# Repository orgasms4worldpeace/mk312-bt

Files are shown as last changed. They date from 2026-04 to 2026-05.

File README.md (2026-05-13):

# MK-312BT

DIY build of the **ErosTek ET-312B** e-stim power box, with Bluetooth (HC-05) or WiFi (ESP8266) wireless control. Boards, BOM, firmware, case, and the documentation needed to actually build one.

> ⚠️ **Safety.** This is a high-voltage device. Don't injure yourself. No warranty.

## How to build one

Work through the numbered directories in order. The full step-by-step walkthrough is in **[`build-guide.md`](build-guide.md)**.

| Step | Directory | What you do |
|---|---|---|
| 1 | [`1-order-boards/`](1-order-boards/) | Send the main-board + front-panel gerbers to JLCPCB |
| 2 | [`2-order-parts/`](2-order-parts/) | Import the BOM into Mouser. Pre-match MOSFETs by Vt — this prevents Error 20 |
| 3 | [`3-build-and-flash/`](3-build-and-flash/) | Solder, print the case, flash the ATmega16A |
| 4 | [`4-wireless/`](4-wireless/) | Pick **Bluetooth** (HC-05) or **WiFi** (ESP8266 — required for macOS / iOS) |
| 5 | [`5-software/`](5-software/) | Pick a control client (links to upstream projects — none bundled) |

If anything misbehaves, [`3-build-and-flash/troubleshooting/`](3-build-and-flash/troubleshooting/) has per-failure-code analyses and the archived metafetish.club forum threads.

## Speculative work in progress

See [`Roadmap.md`](Roadmap.md) for hardware/firmware ideas that haven't been verified end-to-end yet. Nothing in there is on the build path until it lands in the numbered directories.

## What this repo is (and isn't)

A 2026 reorganization of two dormant upstream projects into one build-journey monorepo. Scope: **boards, BOM, firmware, case, build instructions**. Control software stays upstream where it's maintained.

- Upstream for the box: [CrashOverride85/mk312-bt](https://github.com/CrashOverride85/mk312-bt) — boards, firmware, case
- Upstream for the WiFi adapter: [Rangarig/MK312WIFI](https://github.com/Rangarig/MK312WIFI) — pulled into [`4-wireless/wifi/`](4-wireless/wifi/) as a `git subtree`
- Control clients (`mk312-gui`, `ErosWeb`, `three-twelve-bee`, `restim`, etc.): index at [`5-software/`](5-software/) — install whichever from its own repo

This repo is **not** a fork claiming originality, **not** the "official" MK-312BT (there is no official), and **not** a maintained software hub. It's a curation effort with attribution preserved.

### Hardware lineage

```
ErosTek ET-312B               commercial e-stim box (early 2000s, still sold)
└─ metafetish/mk312-bt        community DIY clone, repo deleted ~Dec 2020
   └─ CrashOverride85/mk312-bt   preservation fork, current upstream
      └─ this repo                  2026 reorganization
```

v1.4 board files were DM'd to CrashOverride85 shortly after the metafetish repo was deleted, with no original Eagle source. The design has been built successfully by several people. v1.2 / v1.3 boards (with Eagle source) live in the upstream `CrashOverride85/mk312-bt` repo for anyone who wants to modify the design. Longer story in [`build-guide.md`](build-guide.md#provenance).

### Forum archive

The `metafetish.club` forum — where most community debugging knowledge accumulated — is now offline. Threads on building, Error 20, parts substitution, and firmware live as PDFs in [`3-build-and-flash/troubleshooting/`](3-build-and-flash/troubleshooting/).

## Credit

| Person / project | What they did |
|---|---|
| **CrashOverride85** | Preserved the metafetish repo; ongoing upstream for the box |
| **Rangarig** & **cLx** | MK312WIFI design, schematics, ESP firmware |
| **timduru** | Additional MK312WIFI code contributions |
| **kinkytofu** | [`buttshock-py`](https://github.com/kinkytofu/buttshock-py) — original ET-312 serial-protocol library, predecessor of every Python client |
| **clxjaguar** (cLx) | [`mk312-gui`](https://github.com/clxjaguar/mk312-gui) PyQt client, `mk312-raw-control` |
| **fenbyfluid** | [`three-twelve-bee`](https://github.com/fenbyfluid/three-twelve-bee) web client |
| **boyinsea** | [`ErosWeb`](https://github.com/boyinsea/ErosWeb) sub/dom remote-play client |
| **diglet48** | [`restim`](https://github.com/diglet48/restim) audio-input signal generator |
| **Rubberfate** | [`mk312com`](https://github.com/Rubberfate/mk312com) Python wrapper |
| **Carumbad** | Home Assistant + MQTT bridges |
| **The metafetish.club community** | Board iteration + decades of debug knowledge sitting in the archived threads |
| **ErosTek** | Designers of the ET-312B that this clones |

License: each upstream's original license carries over. New connective material in this repo (READMEs, `build-guide.md`, BOM tooling) is offered freely.

## Getting help

The active community lives in the `#boxes-pulse-based-diy` and `#312-chat` channels on [Joanne's E-Stim Community Discord](https://discord.gg/rY8C27S).

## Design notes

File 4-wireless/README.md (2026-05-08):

# Step 4 — Wireless control

The MK-312BT exposes a serial protocol on the same header that drives the wireless module. Pick one of two pin-compatible options:

## Bluetooth (HC-05) — [`bluetooth/`](bluetooth/)

- **Original / canonical** option. Uses an HC-05 ZS-040 module
- Cheapest, most documented, works with any Bluetooth Classic SPP client
- Pairing: `MK-312BT` / pin `1234`
- Range and reliability hit the usual Bluetooth Classic limits
- Auto-config flow: flash a one-time `.bin` to the AVR that AT-configures the HC-05 for you. See [`bluetooth/hc05-setup.md`](bluetooth/hc05-setup.md)

## WiFi (ESP8266) — [`wifi/`](wifi/)

- **Drop-in replacement** for the HC-05 — pin-compatible. Plug an ESP8266-01S module into the same socket.
- Better range and reliability than Bluetooth, easier integration with VR and network apps
- Configuration: power on → device boots into AP mode (`WifiAP` shown on LCD) → connect with phone → set your WiFi → device joins the network and shows its IP on the LCD
- Communication: UDP broadcast `MK312-ICQ` on port 8842 returns the device IP, then TCP on port 8843 (one client at a time)
- Source: [Rangarig/MK312WIFI](https://github.com/Rangarig/MK312WIFI), pulled in as a git subtree
- Includes the ESP firmware (Arduino), a custom KiCad PCB design, and a .NET example client

### Ordering the adapter PCB — [`wifi/pcb/jlcpcb-package/`](wifi/pcb/jlcpcb-package/)

Drop-in upload bundle for **JLCPCB SMT-only assembly**: gerbers, BOM, and CPL prebuilt. JLC pre-mounts the only SMD part (U1, AMS1117-3.3 regulator); you hand-solder the 6 through-hole parts (caps, transistor, button, headers). ~$20-25 for 5 boards. See [`wifi/pcb/jlcpcb-package/README.md`](wifi/pcb/jlcpcb-package/README.md) for the upload walkthrough and THT parts shopping list.

## Which should I use?

| Use case | Pick |
|---|---|
| Standard / phone app control | Bluetooth (HC-05) |
| VR headset, network app, or "BT just doesn't work for me" | WiFi (ESP8266) |
| Scripting the protocol from Python or Unity | WiFi — TCP is friendlier than rfcomm |

## The serial header is the same for both

Both modules use the same physical pinout (TX/RX/GND/VCC/STATE) on the MK-312BT mainboard. Swap between them without changing the box itself.

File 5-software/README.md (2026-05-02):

# Step 5 — Software

Once the box is built, flashed, and equipped with a wireless adapter (or wired through the LINK port with an RS-232 cable), you need a client to control it. **This directory is a links-only index** — no bundled forks. Use the upstream projects directly.

Earlier versions of this repo bundled `clxjaguar/mk312-gui` as a git subtree. The 2026-04 cleanup removed it — this repo focuses on the hardware/PCB/firmware stack, not on maintaining forks of someone else's control GUI. Pick whichever client below matches your transport and platform, and follow its install instructions.

The MK312WIFI bundled .NET reference client at [`../4-wireless/wifi/DotNetClient/`](../4-wireless/wifi/DotNetClient/) stays in place — part of the upstream MK312WIFI package (shipped alongside the firmware and PCB) and a useful Unity/VR starting point. Not an end-user GUI.

## Recommended

| Client | Transport | Platform | Status | When to pick |
|---|---|---|---|---|
| **[clxjaguar/mk312-gui](https://github.com/clxjaguar/mk312-gui)** | LINK serial cable, **MK312WIFI bridge** (UDP/TCP) | Win/Mac/Linux (PyQt5) | Active 2025-10 | **Default pick.** Speaks the WiFi-adapter protocol natively (cLx co-authored MK312WIFI). The canonical PyQt control GUI. |
| **[fenbyfluid/three-twelve-bee](https://github.com/fenbyfluid/three-twelve-bee)** ([live demo](https://three-twelve-bee.netlify.app)) | Web Serial API (Chrome/Edge) | Any OS with Chrome/Edge | Stale 2024-01 | Browser-based — no install. Targets ET-312 specifically; protocol-compatible with MK-312-BT. Ships the ErosLink routine viewer. |
| **[boyinsea/ErosWeb](https://github.com/boyinsea/ErosWeb)** | Web Serial API (USB-serial cable to LINK port) | Mac/Win/iPad (Chrome/Edge for sub) | Stale 2020-10 | Sub/Dom remote-play architecture with PeerJS voice/video built in. |

## Other / specialized

| Project | What | Notes |
|---|---|---|
| [clxjaguar/mk312-raw-control](https://github.com/clxjaguar/mk312-raw-control) | Python "link mode" override via serial — for protocol experimentation | Active 2026-02 |
| [diglet48/restim](https://github.com/diglet48/restim) | Audio-input signal generator (funscript / video sync) | Active 2026-04. **Caveat:** the restim wiki's [commercial-hardware page](https://github.com/diglet48/restim/wiki/commercial-hardware) admits the 312-family audio-input integration is theoretically capable but **never validated end-to-end**. Treat as experimental. |
| [Rubberfate/mk312com](https://github.com/Rubberfate/mk312com) | Lower-level Python wrapper library | Stale 2021. A library, not a GUI — useful for custom integrations. |
| [Carumbad/HomeAssistant_ET312](https://github.com/Carumbad/HomeAssistant_ET312) | Home Assistant integration | Active 2026-04. ET-312 native, protocol-compatible with MK-312-BT. |
| [Carumbad/et312_mqtt](https://github.com/Carumbad/et312_mqtt) | MQTT bridge | Stale 2020. |
| [kinkytofu/buttshock-py](https://github.com/kinkytofu/buttshock-py) | Original Python ET-312 protocol library | Archived 2016 — historical reference, predecessor of all the above. |

## What's in the MK312WIFI bundle (for completeness)

(See note above on the .NET reference client at [`../4-wireless/wifi/DotNetClient/`](../4-wireless/wifi/DotNetClient/) — kept with the WiFi package as upstream shipped it.)

## Bluetooth (HC-05) clients?

If you went the bluetooth route in step 4, **none of the above speak Bluetooth Classic SPP** — they're all serial-cable or WiFi-bridge clients. Options:

- An Android app from the e-stim community (search the [#312-chat Discord](https://discord.gg/rY8C27S) channel)
- A serial-over-Bluetooth shim on Windows/Linux (HC-05 paired as virtual COM port)
- **macOS users: HC-05 won't work reliably** because Apple deprecated SPP. Use the WiFi adapter instead.

## What you need physically

Whatever client you pick, you'll need one of:
- An **MK312WIFI adapter** (built per [`../4-wireless/wifi/`](../4-wireless/wifi/)) — pin-compatible drop-in for the HC-05 socket, talks WiFi
- An **HC-05 module** (BOM-listed) — works on Win/Linux/Android, **broken on macOS Monterey+**
- A **USB-to-RS232 cable** for the LINK port (BOM lists the [DSD-TECH FT232RL cable](https://www.amazon.com/DSD-TECH-RS232-Serial-FT232RL/dp/B07XXWVH69/) under "PC Link Cable") — works everywhere

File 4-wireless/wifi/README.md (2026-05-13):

# MK312 WiFi adapter

A drop-in replacement for the HC-05 Bluetooth module on the MK-312BT, based on the **ESP8266-01S**. Pin-compatible with the same Radio Header socket — the box doesn't need any change.

This is a collaboration between **Rangarig** and **cLx**, with additional code imported from [timduru's branch](https://github.com/timduru/MK312WIFI/commits/timdev/). Upstream lives at [Rangarig/MK312WIFI](https://github.com/Rangarig/MK312WIFI) and is pulled into this repo as a `git subtree`.

> No guarantees are given. If you use this hardware to injure yourself, no responsibility is taken.

## Why use the WiFi adapter instead of the HC-05?

- Better range and reliability than Bluetooth Classic
- Works on **macOS Monterey+** and **iOS** (where HC-05 / Bluetooth Classic SPP is broken/unsupported)
- Easier integration with VR headsets, network apps, scripting from any language

The serial header on the MK-312BT is identical for both — swap modules without changing the box.

## What's in this directory

| Path | Contents |
|---|---|
| [`firmware/`](firmware/) | Arduino `.ino` source plus pre-built `.bin` files for the ESP8266 |
| [`pcb/`](pcb/) | KiCad schematic + board source and fab gerbers for the adapter PCB |
| [`pcb/jlcpcb-package/`](pcb/jlcpcb-package/) | Ready-to-upload bundle for ordering 5 boards from JLCPCB with SMT assembly (~$20–25) — see its [README](pcb/jlcpcb-package/README.md) |
| [`media/`](media/) | Photos and schematics referenced by this README |

## Hardware

Use the provided PCB layout, or wire your own. **The MK-312BT supplies 5 V** on the Radio Header, so you need a 3.3 V regulator (the AMS1117-3.3 on the adapter PCB) — direct 5 V will kill the ESP. The signal-level resistor bridge is already on the box side, so no extra level-shifting is needed.

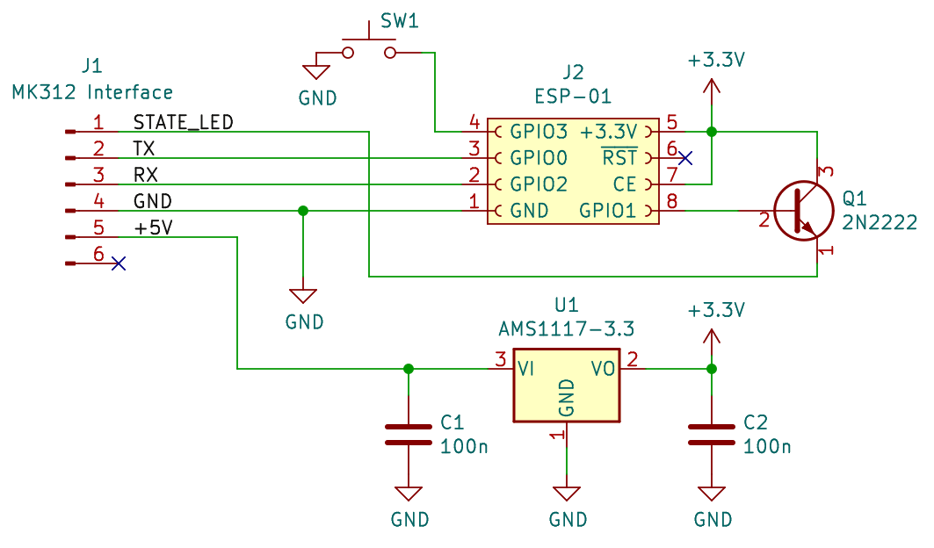
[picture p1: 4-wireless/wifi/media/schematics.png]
MK312 WiFi adapter schematic


| ESP pin | In between | MK-312BT |
|---|---|---|
| GND | — | GND |
| VCC | 3.3 V regulator (AMS1117-3.3) | VCC (5 V) |
| CHIP_EN | — | — |
| GPIO0 | — | TX |
| GPIO2 | — | RX |
| GPIO1 | NPN transistor | STATE |
| GPIO3 | AP-mode switch to GND | — |

The hardware UART outputs bootloader garbage that confuses the MK-312BT, so the firmware uses a software-serial implementation on the pins listed above.

## BOM (per adapter)

| Qty | Component |
|-----|---|
| 1 | ESP8266-01S module |
| 1 | AMS1117-3.3 regulator |
| 2 | 100 nF (104) ceramic disc capacitors |
| 1 | 2N2222 NPN transistor |
| 1 | Tactile switch 6×6 mm |
| 1 | 5-pin pin header, **right-angle** |
| 1 | 2×4 socket header, angled |

If you're ordering the PCB from JLCPCB, the [`pcb/jlcpcb-package/`](pcb/jlcpcb-package/) bundle has JLC pre-mount the AMS1117 for you — you hand-solder the six through-hole parts (~5–10 min per board).

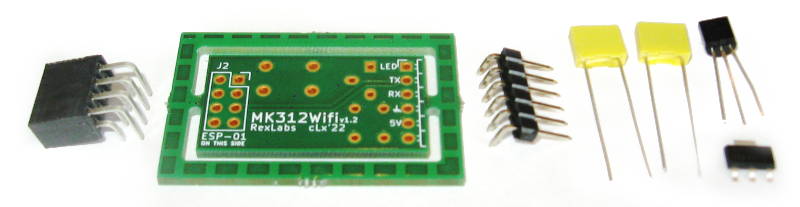
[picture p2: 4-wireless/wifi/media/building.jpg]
Built adapter


## Flashing the ESP firmware

The ESP8266-01 runs on 3.3 V — **set your USB-serial adapter to 3.3 V mode** or the chip will die.

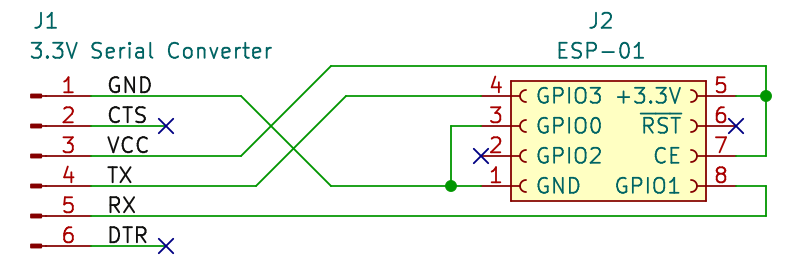
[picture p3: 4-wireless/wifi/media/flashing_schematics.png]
USB-serial wiring
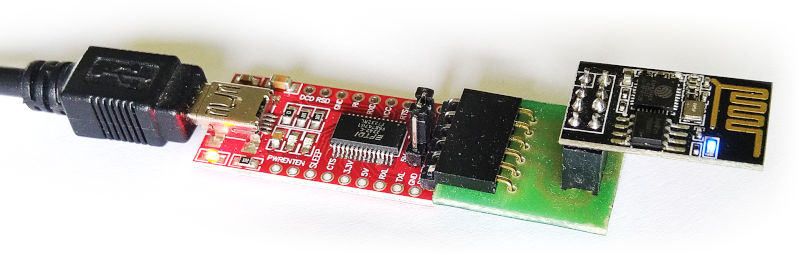
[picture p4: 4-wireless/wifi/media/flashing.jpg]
USB-serial connected
 

ESP-01 top view (row 1 = closer to the board edge):

| Row 1 | Pins | Row 2 |
|---|---|---|
| TX | o&nbsp;&nbsp;o | GND |
| EN | o&nbsp;&nbsp;o | — |
| RST | o&nbsp;&nbsp;o | PRG |
| 3.3V | o&nbsp;&nbsp;o | RX |

To enter programming mode, hold IO0/PRG at GND and briefly pulse RST to GND (or wire RTS from the USB-serial adapter to do it automatically — usually unnecessary).

### Option A — flash the provided `.bin` files

```sh
esptool --chip esp8266 --port /dev/ttyUSB0 --baud 115200 \
        write_flash 0x0 MK312Wifi.ino.bin

esptool --chip esp8266 --port /dev/ttyUSB0 --baud 115200 \
        write_flash 0xEB000 MK312Wifi.mklittlefs.bin
```

The second file holds the HTML/CSS/JS for the web UI on LittleFS at `0xEB000`.

If you have Arduino installed, `esptool` is also available at `~/.arduino15/packages/esp8266/hardware/esp8266/3.1.2/tools/esptool/esptool.py`.

### Option B — build from source with the Arduino IDE

Tested versions:

- Arduino IDE 1.8.19
- ESP8266 boards package 3.0.2 — add `http://arduino.esp8266.com/stable/package_esp8266com_index.json` under **File → Preferences → Additional Boards Manager URLs**, then install **Generic ESP8266 module** in Tools → Board Manager
- WifiManager library 2.0.5-beta — install from [tzapu/WifiManager](https://github.com/tzapu/WifiManager) via **Sketch → Include Library → Add .ZIP Library**
- LittleFS upload plugin — install [arduino-esp8266littlefs-plugin](https://github.com/earlephilhower/arduino-esp8266littlefs-plugin/releases) into the Arduino tools folder. The `data/` directory contents need to be uploaded to LittleFS for the web UI to work.

Open the `.ino`, compile, flash.

## First boot

Plug the adapter into the HC-05 socket facing the correct way and power on the MK-312BT.

The firmware negotiates a key with the box. If negotiation fails, the message LED blinks an error code:

| Blinks | Cause |
|---|---|
| 1 | Invalid checksum |
| 2 | Handshake failed at step 1 |
| 3 | Handshake failed at step 2 |
| 4 | Handshake failed at step 3 |
| 5 | Unexpected reply from device |
| 10 | Unexpected reply from poke operation |
| 11 | Unexpected reply from peek operation |

After successful handshake, the adapter enters AP mode. The MK-312BT LCD shows `WifiAP`.

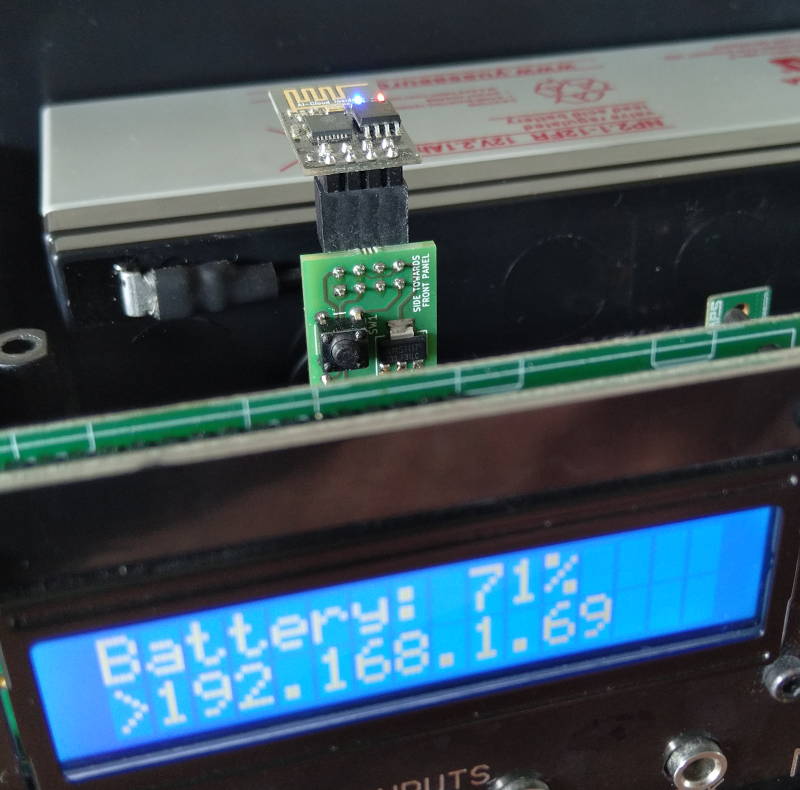
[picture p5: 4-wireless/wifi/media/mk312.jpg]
MK-312BT with WiFi adapter after power-on


1. Connect your phone to the WiFi network `MK312CONFIG-AP`
2. WifiManager's captive portal opens — pick your home WiFi and enter the password
3. The adapter connects to your network and shows its IP address on the MK-312BT LCD
4. The network settings are persisted — subsequent boots reconnect automatically

To change networks later: press the AP-mode button on the adapter, or boot with the configured network unavailable (it falls back to AP mode automatically).

## Network protocol

### Discovery

Send a UDP broadcast to port **8842** containing `MK312-ICQ`. The adapter replies with its IP address.

### Control

Open a TCP connection to the adapter on port **8843**. **One client at a time.**

From here it speaks the same protocol as the LINK serial port. Full reference: [docs.buttplug.io — Erostek ET-312B protocol](https://docs.buttplug.io/docs/stpihkal/protocols/erostek-et312b/).

- **Encrypted mode** (default): send `0x00`, receive `0x07`, then do the standard key negotiation.
- **Unencrypted mode** (optional): instead of normal key negotiation, send `0x2f4242`. This is an invalid checksum but the firmware recognizes it as a request for unencrypted mode. The reply is `0x69`. No encryption needed from there.

Existing serial-protocol clients should adapt with minimal changes; the encryption is the only difference.

## Web interface

Connect a browser to the adapter's IP on **port 80**. Simple HTML page using a **websocket server on port 81** for control. Message format: `<command>=<argument>`.

HTTP also exposes:

- `GET /EXEC?cmd=<command>&val=<argument>`
- `GET /RAW?cmd=<address>&val=<byte>`

Commands:

| Command | Argument |
|---|---|
| `Mode` | `0x76`–`0x8e` for the different modes |
| `DisableADC` | `1` to override pots, `0` to re-enable |
| `EnableADC` | `1` to restore pots, `0` to override |
| `LevelA` | `0`–`255` (requires `DisableADC=1`) |
| `LevelB` | `0`–`255` (same) |
| `startRamp` | (no argument) |
| `CutLevels` | `1` to set both channels to zero |
| `MultiAdjust` | `0`–`100` (scaled in the current mode range) |

## Using legacy serial clients

Software written for a real serial port (HC-05, RS-232 cable) can talk to the adapter through a virtual COM port:

- **Linux:** `socat -v pty,link=/home/$USER/tcptty0,raw tcp:<adapter-ip>:8843` — then connect your client to `/home/$USER/tcptty0`
- **Windows:** [VSPE](https://www.youtube.com/watch?v=7g6v_m208LQ) (Virtual Serial Port Emulator) is known to work

## Native clients

- See the example C# implementation that ships alongside this README upstream
- [clxjaguar/mk312-gui](https://github.com/clxjaguar/mk312-gui) — PyQt GUI with native support for cable, unencrypted, and legacy network links

## Bonus

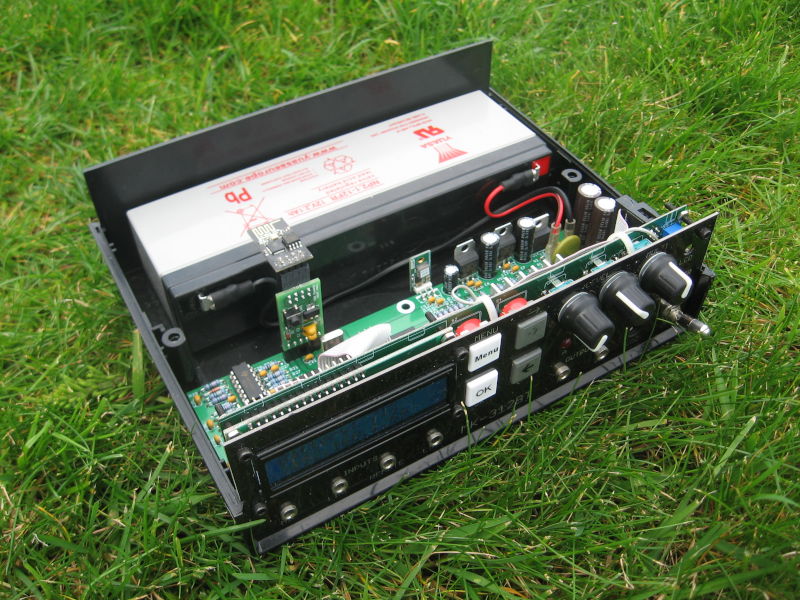
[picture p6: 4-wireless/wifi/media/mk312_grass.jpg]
MK-312BT with WiFi adapter in the grass


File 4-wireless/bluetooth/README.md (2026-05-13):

# Bluetooth (HC-05)

The original wireless option for the MK-312BT. An HC-05 ZS-040 module plugs into the J9 "Radio Header" socket.

## Files in this directory

| File | What it is |
|---|---|
| **[`hc05-setup.md`](hc05-setup.md)** | **Canonical configuration walkthrough.** Wiring, AT-mode entry, per-platform terminal setup (picocom on macOS/Linux, Arduino IDE Serial Monitor or Termite on Windows), every AT command you need, the IPSCAN power tradeoff with comparison table, pairing per OS, and the macOS "Disconnected" cosmetic quirk. **Read this when configuring an HC-05.** |
| `HC05PINOUT.png` | HC-05 inner module pinout. Solder pin 32 (STATE) to the breakout board to drive the front-panel "Radio" LED. |
| `MK-312BT V1.2 HC-05 Initialization ATMEGA16.bin` | One-shot AVR firmware that auto-configures the HC-05 from the box itself — useful only without a USB-TTL adapter. Flash it, plug HC-05 in, power on with HC-05 button held, watch LCD. Then re-flash with the real firmware. |
| `MK-312BT V1.2 HC-05 Initialization ATMEGA16.bas` | BASIC source of the auto-config firmware (BASCOM-AVR), for reference and modification. |
| `AT COMMANDS README.txt` | Original short-form AT command list. Superseded by `hc05-setup.md`. |

## Which HC-05 module to buy

Not all HC-05 modules are equal. After building several units, the **DSD Tech HC-05 Pass-through Module ([Amazon B01G9KSAF6](https://www.amazon.com/DSD-TECH-HC-05-Pass-through-Communication/dp/B01G9KSAF6))** has been the most reliable for mk312-bt builds, for two reasons:

- **Pin 32 (STATE) is already soldered to the breakout board.** This is the #1 fiddly step on cheap clones — you have to manually wire-bridge a 0.5 mm pad on the inner module to drive the front-panel "Radio" LED. The DSD Tech variant ships with this connection already made.
- **Stable AT-mode firmware.** Some JY-MCU and generic ZS-040 clones reject `AT+NAME?` queries even when the name was set successfully (see warning in [`hc05-setup.md`](hc05-setup.md)) and have other quirks. DSD Tech modules pass the standard AT command set without surprises.

Generic ZS-040 modules from random sellers will work too if you're willing to solder pin 32 yourself and tolerate AT-command quirks — but for a build-once, ship-it unit, the DSD Tech version is worth the extra $1–2.

## Quick start

If you'd rather skip the reading: pair as `MK-312BT` with PIN `1234`, but configure those values onto the HC-05 first — it ships as `HC-05` / `1234` / 9600 baud and the box speaks 19200. See [`hc05-setup.md`](hc05-setup.md) for how.

## Heads up

- **macOS Monterey+ has poor Bluetooth Classic SPP support.** HC-05 pairs, but data sessions drop. Use the [WiFi adapter](../wifi/) instead.
- **iOS doesn't speak SPP at all** — WiFi adapter is your only option.
- **HC-05 idle draw is ~43 mA on default settings**, which makes the stock 7805 linear regulator run warm. Either swap to a switching regulator (mEZD71201A-G drop-in) or set `AT+IPSCAN=1024,1,1024,512` to drop idle to ~15 mA. See the IPSCAN section in `hc05-setup.md`.

→ Back to [Step 4 — Wireless](../README.md) | Up to [build guide → Bluetooth](../../build-guide.md#bluetooth-hc-05-configuration)

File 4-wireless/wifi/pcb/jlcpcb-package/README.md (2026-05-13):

# JLCPCB-ready package — MK312 WiFi adapter

A drop-in upload bundle for ordering the [MK312WIFI adapter PCB](../) from JLCPCB with **SMT-only assembly**: JLC pre-mounts the one SMD part (U1, the 3.3V regulator); you hand-solder the 6 through-hole parts.

This is the **cheapest reasonable path** for this board: ~$20–25 for 5 boards. Full PCBA-with-THT runs $65–100+ because of THT setup fees; DIY-everything is $12–17 if you're willing to hand-solder the SOT-223 regulator too.

## Files in this package

| File | What it is | Upload to JLC |
|---|---|---|
| [`gerbers.zip`](gerbers.zip) | Standard KiCad gerbers (9 files) — copper, masks, silkscreen, edge cuts, drill | ✅ Yes |
| [`bom.csv`](bom.csv) | BOM: just U1 (AMS1117-3.3, LCSC `C6186`) — the only part JLC assembles | ✅ Yes (in PCBA tab) |
| [`cpl.csv`](cpl.csv) | Pick-and-place: position and rotation for U1 | ✅ Yes (in PCBA tab) |
| [`cpl-all-parts.csv`](cpl-all-parts.csv) | Full pick-and-place (all 7 parts) — reference only, not uploaded | ❌ No |

## Step-by-step at JLCPCB

1. Go to https://jlcpcb.com → **Order Now**
2. Upload `gerbers.zip`
3. PCB settings — defaults are fine. Confirm:
   - **Layers: 2**
   - **Dimensions: 30 × 17 mm** (auto-detected)
   - **Quantity: 5** (minimum) or however many you want
   - **PCB Color: any** (green default is cheapest)
   - **Surface Finish: HASL (with lead)** — cheapest, fine for hand-soldering. Lead-free HASL or ENIG also work
4. Scroll down → enable **PCB Assembly**
   - **Assembly Side: Top side** (U1 is on top)
   - **Tooling holes: Added by JLCPCB** (free, optional)
   - **PCBA Qty: 5** (or however many you want assembled)
5. Click **Confirm** → upload `bom.csv` for the BOM and `cpl.csv` for the CPL
6. JLC shows a parts review screen. Confirm:
   - **U1 / AMS1117-3.3 / C6186** — should be flagged as **Basic** part (no extended-part fee). Rock-solid — JLC has stocked this for years
7. Confirm placement preview — U1 should sit roughly at the middle-left of the board
8. Save to cart → checkout

## What you'll receive

5 boards (or however many) with **only U1 (the SOT-223 regulator) pre-soldered on the top side**. The 6 holes for the THT parts stay empty — that's expected.

## Then hand-solder these 6 THT parts

Buy from Mouser/Digikey/Amazon/AliExpress — these are commodity parts:

| Ref | Part | Qty per board | Sourcing notes |
|-----|---|---|---|
| C1, C2 | 100 nF (0.1 µF) ceramic disc capacitor, 50V, 2.54mm pitch | 2 | Any generic 100nF disc cap |
| Q1 | PN2222A NPN transistor, TO-92 | 1 | PN2222A or 2N2222A interchangeable |
| SW1 | 6mm tactile pushbutton switch, 4-pin THT | 1 | Standard "Omron-style" tactile switch |
| J1 | 1×6 male pin header, **right-angle**, 2.54mm pitch | 1 | Plugs into the MK-312BT mainboard's HC-05 socket — **angled is critical** |
| J2 | 2×4 female socket header, 2.54mm pitch | 1 | The ESP-01S plugs into this — make sure it's **female** (socket), not male |

You also need the **ESP-01S module itself** (~$2 on AliExpress / Amazon). It plugs into J2 after assembly.

## Soldering order (suggested)

1. C1, C2 (lowest profile first — easier with the board flat)
2. Q1 (TO-92, watch flat-side orientation per silkscreen)
3. SW1 (tactile button)
4. J2 (2×4 socket — solder pins straight; the ESP-01S plugs in later)
5. J1 (1×6 right-angle header — pins point outward from the board edge to plug into the MK-312BT)
6. Plug in the ESP-01S module — done

Total hand-soldering: ~5-10 minutes per board.

## Verifying assembly

Before plugging into the MK-312BT:

1. Visually check J1 orientation — pin 1 should match the MK-312BT's HC-05 socket pin 1 (see the [MK312WIFI README](../../README.md) for the pinout table)
2. Multimeter continuity check from J1's VCC pin → U1 input → U1 output → ESP socket VCC pin (J2)
3. Power check: apply 5V to J1's VCC/GND, measure 3.3V at J2's VCC pin — must read 3.3V before plugging the ESP in
4. If 3.3V is good, plug in the ESP-01S, install in the MK-312BT, power on. The LCD should show `WifiAP` on first boot

## Caveats / things to verify before clicking "submit"

- **LCSC Part C6186 stock**: rock-solid Basic part historically, but verify on JLC's PCBA Parts Library at order time
- **Rotation of U1**: the CPL specifies 0° rotation. KiCad's `Regulator_Linear:AMS1117-3.3` footprint puts pin 1 at upper-left at 0° — JLC's expected orientation for SOT-223 also puts pin 1 upper-left at 0°. They should match. If JLC's preview shows U1 visibly rotated wrong, edit the rotation in their web UI before confirming
- **Footprint check**: the upstream MK312WIFI project author generated these gerbers for v1.2 of their design. Builders have used them successfully — this is not a fresh untested PCB
- **THT parts library at JLC**: irrelevant for the SMT-only path (you're not asking JLC to source them). But if you ever switch to full PCBA-with-THT, expect some of the 6 THT parts to need substitutes from JLC's smaller THT inventory

## Regenerating from source

The KiCad source is at [`../kicad-source/`](../kicad-source/) (sibling of this package). With KiCad 6+ installed:

```bash
cd ../kicad-source
kicad-cli pcb export gerbers MK312-Wifi.kicad_pcb --output ../jlc-fresh-gerbers/
kicad-cli pcb export pos MK312-Wifi.kicad_pcb --format csv --units mm \
  --use-drill-file-origin --output cpl-fresh.csv
```

This package was hand-built from the upstream `fab-files.zip` (originally `MK312WIFI_PCB_v1.2_Fabrication_Files.zip`) plus manual parsing of the `.kicad_pcb` source for placements.

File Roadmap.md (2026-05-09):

# Roadmap

Speculative ideas, unverified hardware, and "would be nice if" investigations that aren't part of the build path. Move items into the main docs only after they're verified end-to-end on real hardware.

---

## OSOYOO ESP8266 module as a third wireless option

The [OSOYOO ESP8266 WiFi module](https://osoyoo.com/2020/12/20/osoyoo-esp8266-wi-fi-module/) advertises itself as a 6-pin module in HC-05 footprint with a built-in 5 V → 3.3 V converter. If true, it would physically drop into the same socket as the HC-05 with no MK312WIFI PCB to fabricate.

**Status: unverified — likely won't "just work."** The product page documents 5 V tolerance and a 6-pin layout (VCC, GND, E_RX, E_TX, RST, KEY), but stays silent on the two questions that decide whether it functions as a transparent serial-over-WiFi bridge:

- Does it ship with a transparent UART-over-TCP/UDP bridge mode out of the box, or only AT-command operation? Their tutorials reference AiThinker firmware, which is AT-controlled — the host sends AT commands rather than reading/writing serial bytes.
- Can the baud rate be set to **19200** (what the MK-312BT speaks)?

Even with "yes" to both, the existing client software ([clxjaguar/mk312-gui upstream](https://github.com/clxjaguar/mk312-gui) and the [.NET reference client](4-wireless/wifi/DotNetClient/) bundled here) speaks the MK312WIFI protocol (UDP `MK312-ICQ` discovery on port 8842, TCP control on 8843) — an OSOYOO module won't speak that without custom firmware. You'd need to fork the GUI's transport, write a small bridge, or flash MK312Wifi.ino onto the OSOYOO module (assuming GPIO0/1/2/3 are accessible — they may not be).

**TL;DR:** physically a candidate; protocol-wise unproven and probably needs work. Stick with [`4-wireless/wifi/`](4-wireless/wifi/) (build the small PCB) unless you want to experiment on the firmware and client.

---

## bkifft/MK-312WS — alternative ESP32 wireless adapter

[`bkifft/MK-312WS`](https://github.com/bkifft/MK-312WS) is an ESP32-based webserver replacement for the HC-05 socket. ESP32 D1 Mini dev board plugs into a small carrier PCB (KiCad source + gerbers v1/v2/v3 included; v4 marked buggy by the author). Browser-only UI at `http://mk-312ws.local`, no separate client software install.

bkifft is the same builder from the Metafetish forum threads (#8 in the parts substitution thread) — real engineering, not a hobby drive-by. 16 stars, last commit 2022-10-02 (~3.5 years dormant).

### Why it's interesting

- No SMT assembly required — plug an off-the-shelf ESP32 dev board into the carrier
- No client software install — any browser works
- Bigger MCU (ESP32 vs ESP-01S) gives headroom for future features
- Built-in GUI with knobs, mode select, battery display

### Why it's NOT a replacement for the current Rangarig MK312WIFI

Looked at the actual source (`MK-312WS.ino`, `mk312.cpp`, `mk312.h`):

| Feature | Rangarig MK312WIFI | bkifft MK-312WS |
|---|---|---|
| Mode select | ✅ | ✅ |
| Read battery | ✅ | ✅ |
| LevelA / LevelB direct write | ✅ | ❌ planned |
| MultiAdjust (MA) | ✅ | ❌ planned |
| startRamp | ✅ | ❌ commented out in source |
| CutLevels | ✅ | ❌ |
| DisableADC / EnableADC (pot override) | ✅ | ❌ |
| User program upload | ✅ via raw protocol | ❌ planned |
| EEPROM read/write | ✅ via raw protocol | ❌ |
| Recording / playback | ❌ | ❌ planned |
| **Raw protocol proxy** (lets mk312-gui, .NET ref, ErosWeb, three-twelve-bee connect) | ✅ TCP 8843 | ❌ — `handleWebSocketMessage_ws_bytes()` is an empty function; "raw byte websocket" is in the author's `2do.txt` |
| Encryption | ✅ optional | ❌ |
| Configurable AP password | ✅ | ❌ hardcoded `12345678` |

The web UI exposes a fraction of the box's capability, and the empty byte-passthrough means no existing client software can talk to it. The repo went dormant before shipping the planned features.

### Bar to make this the default

- Wire up the empty `handleWebSocketMessage_ws_bytes()` to proxy raw bytes (the table-stakes feature) — would let existing clients connect
- Or: ship the listed planned features in the web UI to reach UI-only feature parity with mk312-gui
- Active maintenance (or someone forking it forward)
- Make the AP password configurable
- Resolve the unanswered "bt overrules webserver?" note in `notes.txt`

Until then: alternative to investigate, not a replacement.

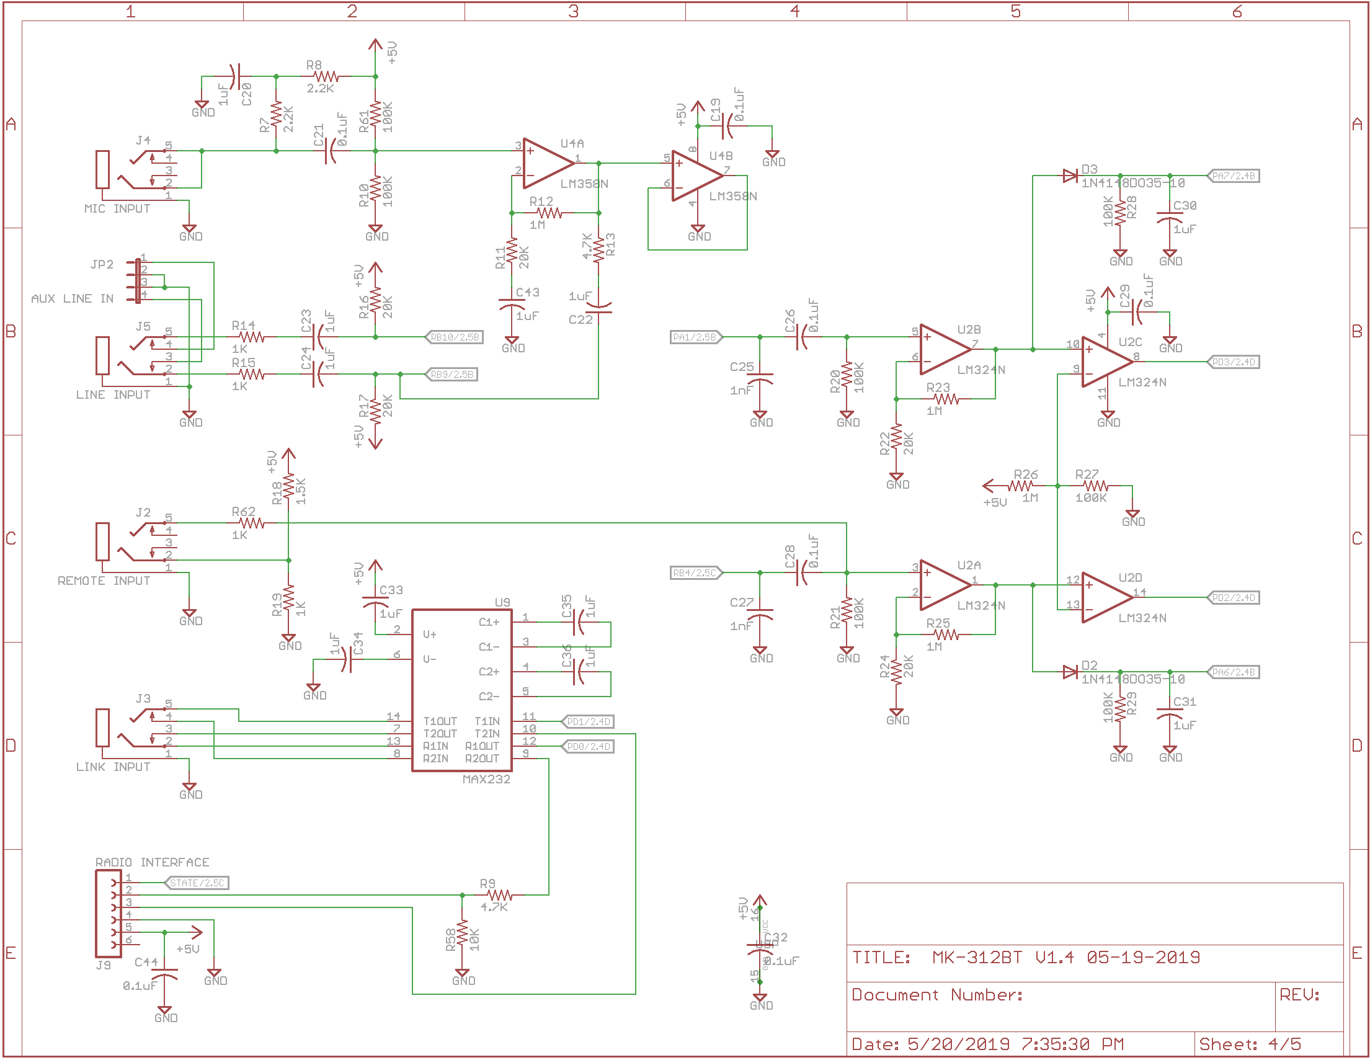
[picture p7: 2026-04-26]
1-order-boards/schematics/pages/v1.4 Schematic Page 4.png

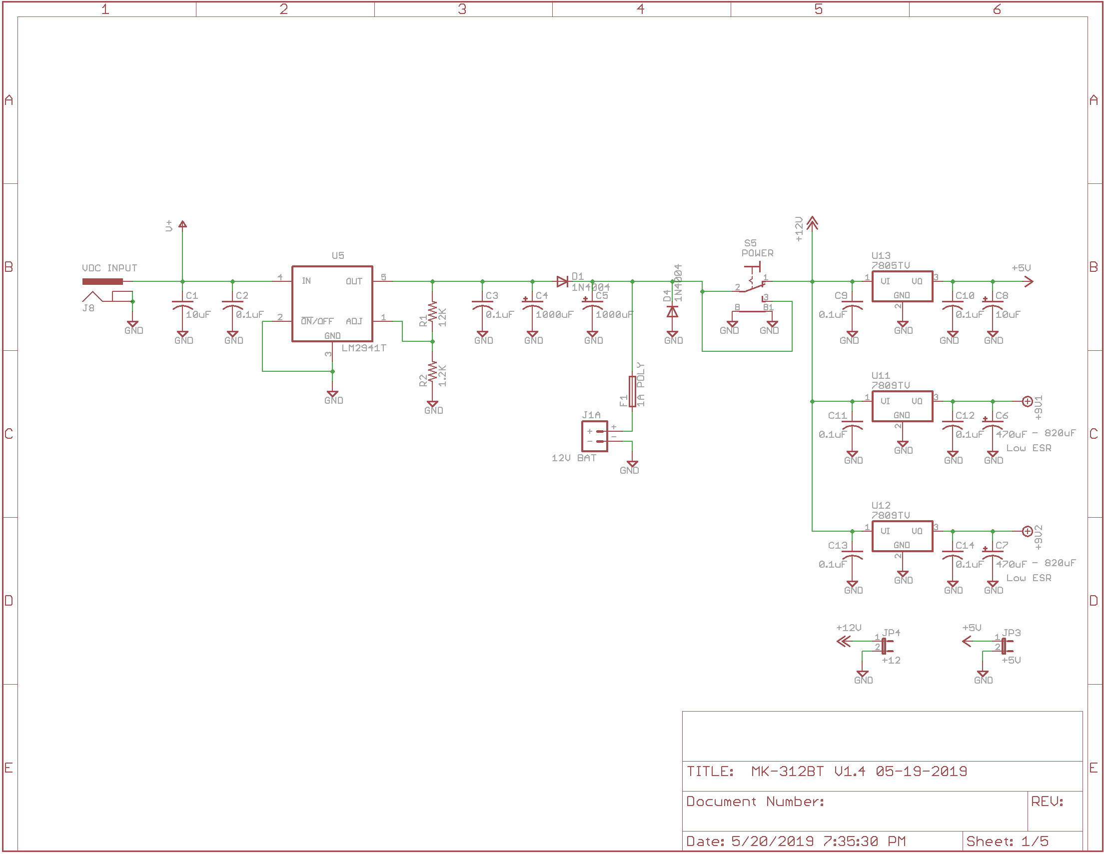
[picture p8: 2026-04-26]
1-order-boards/schematics/pages/v1.4 Schematic Page 1.png

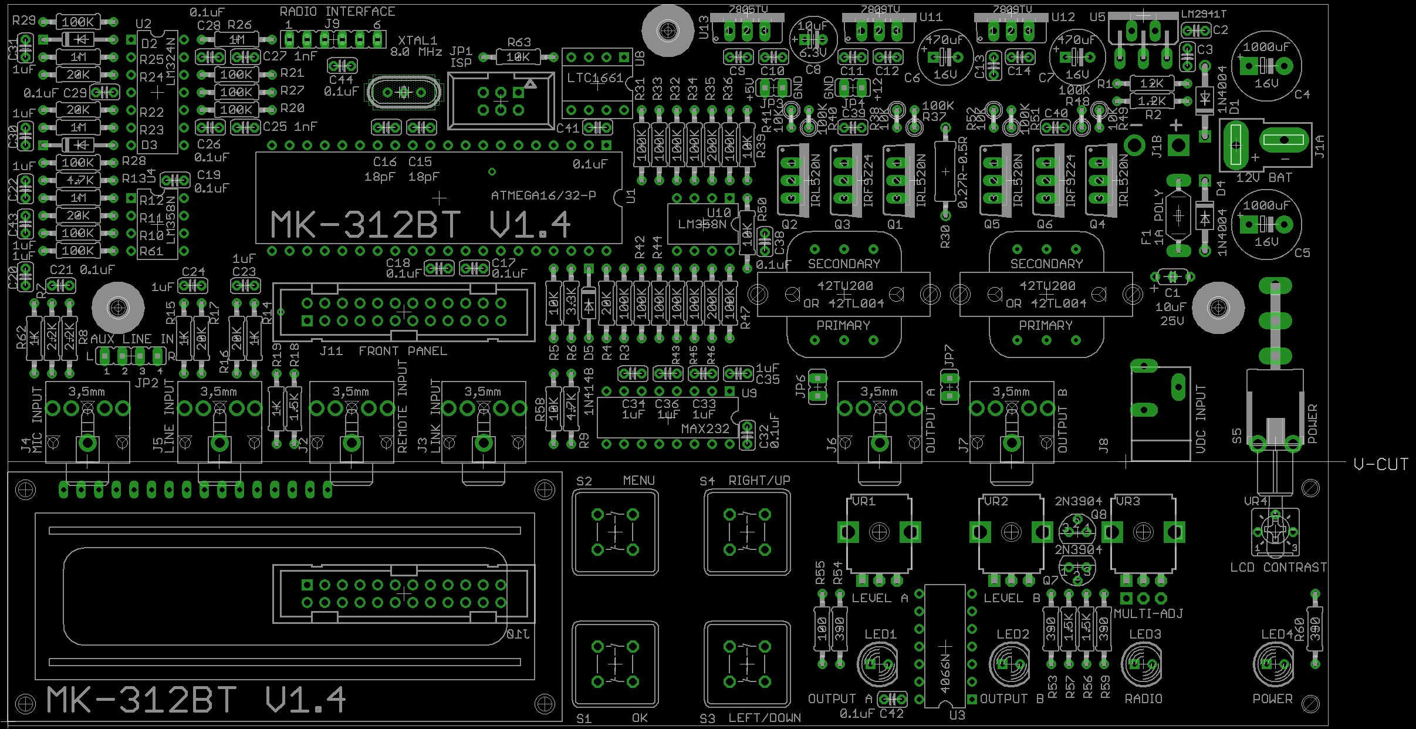
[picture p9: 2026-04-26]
1-order-boards/schematics/v1.4 Part Placement.png

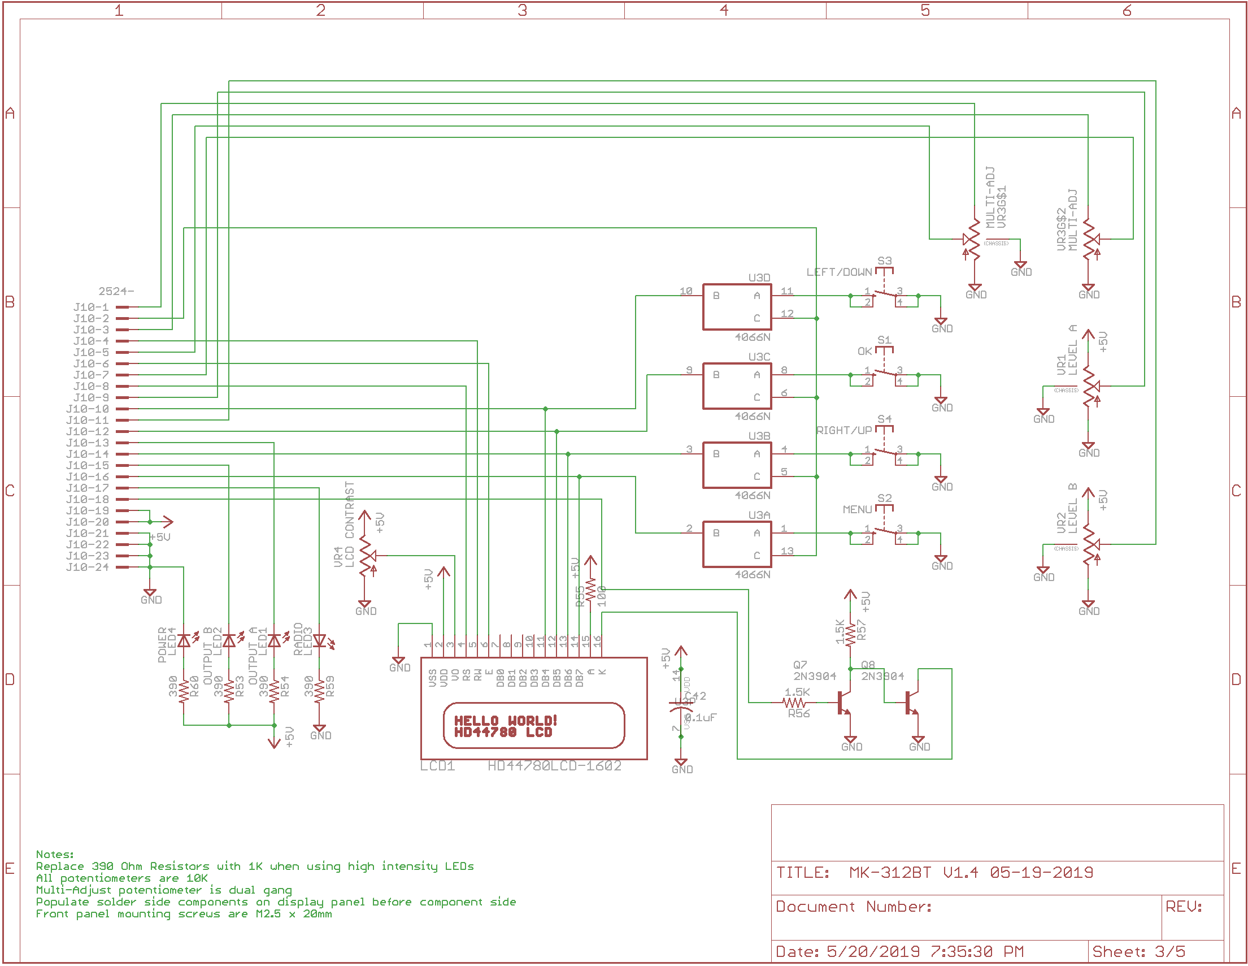
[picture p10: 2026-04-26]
1-order-boards/schematics/pages/v1.4 Schematic Page 3.png

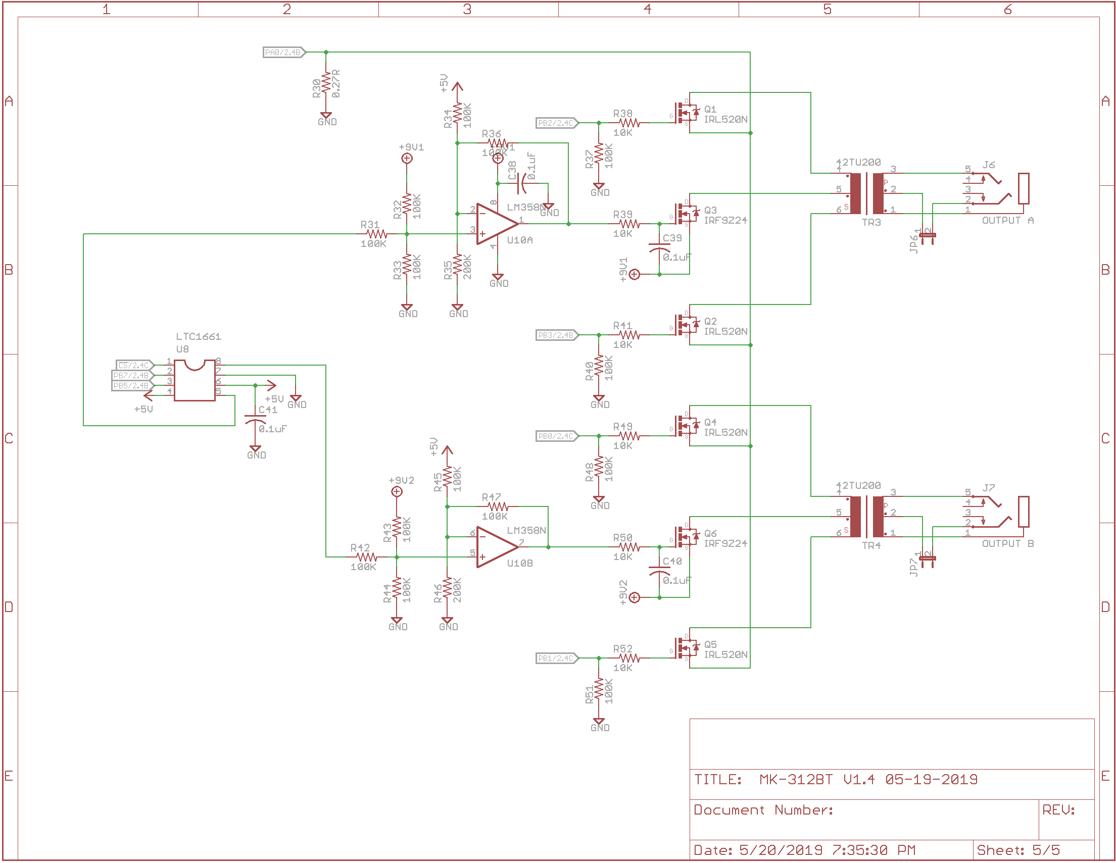
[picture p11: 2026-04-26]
1-order-boards/schematics/pages/v1.4 Schematic Page 5.png

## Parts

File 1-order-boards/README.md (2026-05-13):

# Step 1 — Order boards

You need **two** PCBs to build a working unit, and there's a third optional one most builders should order at the same time:

| Board | File | Required? | Notes |
|---|---|---|---|
| Main board (v1.4) | [`gerbers/v1.4-main-board.zip`](gerbers/v1.4-main-board.zip) | **Yes** | Latest revision. See [v1.4 release notes](v1.4-release-notes.txt) for changes vs v1.3 |
| Front panel (v1.2) | [`gerbers/v1.2-front-panel.zip`](gerbers/v1.2-front-panel.zip) | **Yes** | Front panel design unchanged — v1.2 is current |
| WiFi adapter (optional) | [`../4-wireless/wifi/pcb/jlcpcb-package/gerbers.zip`](../4-wireless/wifi/pcb/jlcpcb-package/gerbers.zip) | Optional but recommended | If you're already paying JLCPCB shipping for the main board + front panel, the marginal cost to add this is ~$5–10. See [combining orders](#combine-with-the-wifi-adapter-while-you-pay-shipping) below. |

Order each as a **separate item in one JLCPCB cart** — the per-board settings differ, but they ship together.

## Recommended fab

[JLCPCB](https://jlcpcb.com) — they detect 2-layer and dimensions automatically when you upload the zip.

## Per-board fab settings

| Setting | Main board | Front panel |
|---|---|---|
| Layers | 2 | 2 |
| Thickness | 1.6 mm | 1.6 mm |
| Surface finish | HASL (Pb-free preferred) | HASL (Pb-free preferred) |
| Copper weight | 1 oz | 1 oz |
| Material | FR4 | FR4 |
| Solder mask | Any color | **Black** recommended (matches case) |
| Silkscreen | White | White |
| Different Design | 2 | 1 |
| Special instructions | V-score the panel as indicated | Place fab markings on **bottom** side |

"Different Design" differs because the main board panel holds 2 panelized designs; the front panel is a single design.

## Combine with the WiFi adapter while you pay shipping

The MK-312-BT supports two wireless options — the original HC-05 Bluetooth module (no PCB needed) and a small WiFi adapter daughter-board that's pin-compatible with the HC-05 socket. The adapter board is its own JLCPCB order with **SMT assembly** (one part, the AMS1117-3.3 regulator), and you hand-solder six through-hole parts after.

If you're already submitting an order for the main board + front panel, the WiFi adapter can ride along in the same cart. JLCPCB lets you submit multiple PCB jobs in one order and ship them together — you only pay shipping once.

| Board | Order type | Setup |
|---|---|---|
| Main board (v1.4) | PCB only | Settings table above |
| Front panel (v1.2) | PCB only | Settings table above |
| WiFi adapter | **PCB + SMT assembly** (one part) | Full step-by-step at [`../4-wireless/wifi/pcb/jlcpcb-package/README.md`](../4-wireless/wifi/pcb/jlcpcb-package/README.md) |

Cost reality check (5-board minimum at JLCPCB, mid-2026 pricing):
- Main board × 5: ~$8–15 PCBs + ~$10–25 shipping
- Front panel × 5: ~$8–15
- WiFi adapter × 5 with SMT: ~$20–25 (PCBs + AMS1117-3.3 assembly)
- **Combined order ships once** — adding the WiFi adapter to a same-day order saves a second shipping charge

You don't have to commit to building WiFi units to order the boards — having spares means you can decide per unit whether to use the HC-05 (cheaper, simpler) or the WiFi adapter (better macOS / iOS support — see [`../4-wireless/README.md`](../4-wireless/README.md)).

## Schematics & layout

For visual reference (don't send these to the fab):

- [`schematics/v1.4 Part Placement.png`](schematics/v1.4%20Part%20Placement.png) — part placement on the main board
- [`schematics/pages/`](schematics/pages/) — schematic pages 1-5

## Need the source files?

v1.4 ships gerbers only — no Eagle source was ever released for v1.4. To modify the design you'd need to either reverse the gerbers in KiCad/Eagle, or work from the older v1.3 Eagle source preserved upstream at [`CrashOverride85/mk312-bt`](https://github.com/CrashOverride85/mk312-bt) (note: v1.3 has known issues that v1.4 fixes — porting changes is non-trivial).

→ Next: [Step 2 — Order parts](../2-order-parts/)

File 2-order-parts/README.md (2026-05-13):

# Step 2 — Order parts

Two BOM files, one purpose: get the right parts in the right quantities.

| File | What it's for |
|---|---|
| [`BOM_Mouser.csv`](BOM_Mouser.csv) | Direct import into Mouser's BOM Tool. Strict 4-column format — don't edit. |
| [`BOM_full.csv`](BOM_full.csv) | Human-readable master with descriptions, designators, and Mouser + Amazon search links. |

## How to use

1. Sign in to [mouser.com](https://www.mouser.com/) and open the **BOM Tool**.
2. Upload `BOM_Mouser.csv`.
3. Review and add to cart.
4. For anything Mouser doesn't carry (or anything cheaper on Amazon — screws, standoffs, headers, LCD), use the Amazon links in `BOM_full.csv`.

## v1.4 part recommendations

[`../1-order-boards/v1.4-release-notes.txt`](../1-order-boards/v1.4-release-notes.txt) covers what changed from v1.3:

- C6, C7 should be **low-ESR** electrolytics
- With 42TU200 transformers and higher output, use 0.27 Ω at R30 and 680–820 µF at C6/C7
- R55 backlight: 100–220 Ω for New Haven LCDs
- J2-J7 can be substituted with [STX-3100-5N](https://www.mouser.com/ProductDetail/Kycon/STX-3100-5N) (no plastic back cover)

## ⚠️ Critical parts — the BOM deliberately over-orders five things

These are intentional over-quantities for matching and spares. **Don't reduce them** when you place the order.

| Part | Designators | Need per board | BOM qty | Why |
|---|---|---|---|---|
| **IRL520N** | Q1, Q2, Q4, Q5 | 4 | 12 | Sort by Vt and pick a quartet matched within ≤30 mV. Typical batch spread is 200–400 mV — you need 3× over-order to find a tight cluster of 4. |
| **IRF9Z24NPBF** | Q3, Q6 | 2 | 6 | Sort and pick a pair matched within ≤50 mV, with absolute Vt 2.85–3.05 V. Reject any > 3.30 V. |
| **R35, R46** (200 kΩ) | R35, R46 | 2 | 4 | Op-amp bias network — wrong value or a damaged trace is a top Failure 20 cause. Spares cost pennies. |
| **R30** (0.27 Ω 1 W) | R30 | 1 | 3 | Current-sense resistor — value-critical for F20 calibration. Easy to damage during desolder rework. |
| **XTAL1** (8 MHz) | XTAL1 | 1 | 2 | Cracked/cold-soldered crystal silently breaks ATmega ISP programming. Cheap insurance. |

The full reasoning — Vt-headroom math, the Vishay vs Infineon supplier trap, sort-and-pair logic for assigning specific FETs to specific board positions — lives in [`../3-build-and-flash/troubleshooting/debug-notes/failure-20-analysis.md`](../3-build-and-flash/troubleshooting/debug-notes/failure-20-analysis.md). Read it before populating boards if you want the full picture; the BOM quantities here are just enough to make that procedure possible.

## 🛠️ Step-by-step — matching the MOSFETs

Do this **before soldering**. Allow 30–45 minutes for 5 boards' worth of parts.

### What you need

- **Component tester** — LCR-P1 or LCR-T7 (the 2-decimal Mega328 variants). Plain 1-decimal Mega328 testers don't have the resolution to sort within 30 mV.
- **Fine-tip permanent marker** (sharpie) to label each FET with its measured Vt.
- **Sorting tray** — egg carton, ice-cube tray, or a piece of paper with rows labeled by Vt range.

### The flow

```mermaid
flowchart TD
    accTitle: MOSFET matching workflow
    accDescr: Six-step procedure for sorting and matching MOSFETs by Vt before soldering. Test each FET, label it, sort into clusters, then pick matched sets per board.

    start(["Power on tester<br/>(2-3 throwaway tests to warm up)"])
    discharge["Short Gate↔Source on next FET<br/>(tweezers, 1-2 sec)"]
    test["Insert in ZIF socket<br/>Press TEST<br/>Read Vt"]
    label["Write Vt on FET with sharpie<br/>Drop into sorting tray"]
    wait["Wait 30 sec"]
    more{"More FETs?"}
    sort["Group sorted FETs into matched sets:<br/>IRL520N quartets ≤30 mV<br/>IRF9Z24N pairs ≤50 mV"]
    done(["Solder matched sets per board"])

    start --> discharge
    discharge --> test
    test --> label
    label --> wait
    wait --> more
    more -->|yes| discharge
    more -->|no| sort
    sort --> done

    classDef action fill:#dbeafe,stroke:#2563eb,stroke-width:2px,color:#1e3a5f
    classDef decision fill:#fef9c3,stroke:#ca8a04,stroke-width:2px,color:#713f12
    classDef terminal fill:#dcfce7,stroke:#16a34a,stroke-width:2px,color:#14532d

    class discharge,test,label,wait,sort action
    class more decision
    class start,done terminal
```

### Per-FET procedure

1. **Discharge the gate.** Touch the leftmost lead (Gate) to the rightmost lead (Source) on the TO-220 with tweezers for 1–2 seconds. Skipping this step is the #1 cause of run-to-run jitter.
2. **Insert in the tester.** Hold the FET by the metal tab only — body heat on the leads shifts Vt by ~6 mV/°C, enough to corrupt the reading.
3. **Press TEST.** Read the Vgs(th) value (e.g., `1.94 V`).
4. **Label and sort.** Write the Vt on the FET package with the sharpie. Drop it in your sorting tray under its Vt range.
5. **Wait ~30 seconds** before the next FET — thermal settling.

### Pick the matched sets

After all FETs are tested and sorted:

**IRL520N quartet — one per board (Q1, Q2, Q4, Q5):** pick four FETs within ≤30 mV of each other. Sort that quartet ascending, then pair the lowest two on channel A (Q1, Q2) and the next two on channel B (Q4, Q5).

Example with a clean quartet:

```
Sorted Vt:    1.91   1.92   1.92   1.93     (20 mV spread — excellent)
Channel A:    1.91   1.92                   → Q1, Q2
Channel B:           1.92   1.93            → Q4, Q5
```

**IRF9Z24N pair — one per board (Q3, Q6):** pick two FETs matched within ≤50 mV, **both in the 2.85–3.05 V cluster** if you can. The detailed Vt-acceptability tiers (Use first / Acceptable / Marginal / Reject) are in [`failure-20-analysis.md`](../3-build-and-flash/troubleshooting/debug-notes/failure-20-analysis.md).

### If your sample doesn't yield a tight quartet

Two options:

| Option | Tradeoff |
|---|---|
| Build with a wider quartet (50–80 mV) | Probably passes F20 but pulse symmetry is degraded. Output feels asymmetric and metal electrodes corrode faster (Lilly-wave electromigration). |
| Order more IRL520Ns from the same Mouser reel and merge into the pool | Tightens the available cluster. Adds ~$10 and a week of shipping per board you couldn't match. |

## Tester quirks worth knowing

The LCR-P1 has 2-decimal precision but ~30–100 mV of run-to-run noise from gate-charge memory, probe contact variation, and the tester's own ramp-and-detect algorithm. The per-FET procedure above is what controls those.

For a single FET you suspect of jittering more than expected:

1. Take **5 readings** of the same FET, with full discharge + 30 sec wait between each.
2. Drop the highest and lowest.
3. Average the middle 3 → that's your sorting value.

If a single FET still spreads > 50 mV after that procedure, the tester or ZIF socket has a problem (worn contacts, dead battery, EMI nearby). Borrow a different unit before trusting the data.

## Substitutions

Parts you couldn't find? The metafetish forum archive has practical substitutions from people who actually built the box: [`../3-build-and-flash/troubleshooting/MK-312BT parts substitution - Estim - Metafetish.pdf`](../3-build-and-flash/troubleshooting/MK-312BT%20parts%20substitution%20-%20Estim%20-%20Metafetish.pdf).

→ Next: [Step 3 — Build and flash](../3-build-and-flash/)

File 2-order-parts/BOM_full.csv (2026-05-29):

Last modified: 2026-05-29
Designator | Description | Quantity | Mouser Part # | Manufacturer Part # | Sourced? | Mouser URL | Amazon URL
R55 | RES 100R (LCD backlight series for Newhaven NHD-0216K1Z) | 1 | 71-CMF55100R00FHEB | CMF55100R00FHEB | X | mouser.com/c/?q=71-CMF55100R00FHEB | amazon.com/s?k=CMF55100R00FHEB
R53,R54,R59,R60 | RES 390R | 4 | 71-CMF55390R00FHEB | CMF55390R00FHEB | X | mouser.com/c/?q=71-CMF55390R00FHEB | amazon.com/s?k=CMF55390R00FHEB
C2,C3,C9,C10,C11,C12,C13,C14,C17,C18,C19,C21,C26,C28,C29,C32,C37,C38,C39,C40,C41,C42,C44 | CAP 0.1uF (0.1" spacing) 50V | 23 | 80-C320C104K5R | C320C104K5R5TA | ✓ | mouser.com/c/?q=80-C320C104K5R | amazon.com/s?k=C320C104K5R5TA
F1 | Polyfuse 1.1A hold / 2.2A trip radial 30V (battery in-line protection) | 1 | 652-MF-R110 | MF-R110 | X | mouser.com/c/?q=652-MF-R110 | amazon.com/s?k=MF-R110
R2 | RES 1.2K | 1 | 71-CMF551K2000FHEB | CMF551K2000FHEB | X | mouser.com/c/?q=71-CMF551K2000FHEB | amazon.com/s?k=CMF551K2000FHEB
R18,R56,R57 | RES 1.5K | 3 | 71-CMF551K5000FHEB | CMF551K5000FHEB | X | mouser.com/c/?q=71-CMF551K5000FHEB | amazon.com/s?k=CMF551K5000FHEB
R3,R10,R20,R21,R27,R28,R29,R31,R32,R33,R34,R36,R37,R40,R42,R43,R44,R45,R47,R48,R51,R61 | RES 100K | 22 | 71-CMF55100K00FHEB | CMF55100K00FHEB | X | mouser.com/c/?q=71-CMF55100K00FHEB | amazon.com/s?k=CMF55100K00FHEB
R5,R38,R39,R41,R49,R50,R52,R58,R63 | RES 10K | 9 | 71-CMF5510K000FHEB | CMF5510K000FHEB | X | mouser.com/c/?q=71-CMF5510K000FHEB | amazon.com/s?k=CMF5510K000FHEB
C1 | CAP 10uF CER | 1 | 810-FG11X7R1H106KRT6 | FG11X7R1H106KRT06 | X | mouser.com/c/?q=810-FG11X7R1H106KRT6 | amazon.com/s?k=FG11X7R1H106KRT06
R1A | RES 12K | 1 | 71-CMF5512K000FHEB | CMF5512K000FHEB | X | mouser.com/c/?q=71-CMF5512K000FHEB | amazon.com/s?k=CMF5512K000FHEB
C15,C16 | CAP 18pF | 2 | 80-C315C180J1G | C315C180J1G5TA | X | mouser.com/c/?q=80-C315C180J1G | amazon.com/s?k=C315C180J1G5TA
R14,R15,R19,R62 | RES 1K | 4 | 71-CMF551K0000FHEB | CMF551K0000FHEB | X | mouser.com/c/?q=71-CMF551K0000FHEB | amazon.com/s?k=CMF551K0000FHEB
R12,R23,R25,R26 | RES 1M | 4 | 71-CMF551M0000FHEB | CMF551M0000FHEB | X | mouser.com/c/?q=71-CMF551M0000FHEB | amazon.com/s?k=CMF551M0000FHEB
D1,D4 | DIODE 1N4004 | 2 | 621-1N4004 | 1N4004-T | X | mouser.com/c/?q=621-1N4004 | amazon.com/s?k=1N4004-T
D2,D3,D5 | DIODE 1N4148 | 3 | 512-1N4148 | 1N4148 | X | mouser.com/c/?q=512-1N4148 | amazon.com/s?k=1N4148
C25,C27 | CAP 1nF (0.1" spacing) | 2 | 80-C315C102K1G | C315C102K1G5TA | X | mouser.com/c/?q=80-C315C102K1G | amazon.com/s?k=C315C102K1G5TA
C20,C22,C23,C24,C30,C31,C33,C34,C35,C36,C43 | CAP 1uF (0.1" spacing) | 11 | 80-C315C105K3R | C315C105K3R5TA | X | mouser.com/c/?q=80-C315C105K3R | amazon.com/s?k=C315C105K3R5TA
R35,R46 | RES 200K | 2 | 71-CMF55200K00FHEB | CMF55200K00FHEB | X | mouser.com/c/?q=71-CMF55200K00FHEB | amazon.com/s?k=CMF55200K00FHEB
R11,R16,R17,R22,R24,R4 | RES 20K | 6 | 71-CMF5520K000FHEB | CMF5520K000FHEB | X | mouser.com/c/?q=71-CMF5520K000FHEB | amazon.com/s?k=CMF5520K000FHEB
J10,J11 | PAK100/2500-24 - 2425- 3M WALL HEADER | 2 | 517-N2524-6002RB | N2524-6002RB | X | mouser.com/c/?q=517-N2524-6002RB | amazon.com/s?k=N2524-6002RB
Q7,Q8 | TRANS. 2N3904 | 2 | 512-2N3904BU | 2N3904BU | X | mouser.com/c/?q=512-2N3904BU | amazon.com/s?k=2N3904BU
R6 | RES 3.3K | 1 | 71-CMF553K3000FHEB | CMF553K3000FHEB | X | mouser.com/c/?q=71-CMF553K3000FHEB | amazon.com/s?k=CMF553K3000FHEB
R7,R8 | RES 2.2K | 2 | 71-CMF552K2000FHEB | CMF552K2000FHEB | X | mouser.com/c/?q=71-CMF552K2000FHEB | amazon.com/s?k=CMF552K2000FHEB
R9,R13 | RES 4.7K | 2 | 71-CMF554K7000FHEB | CMF554K7000FHEB | X | mouser.com/c/?q=71-CMF554K7000FHEB | amazon.com/s?k=CMF554K7000FHEB
U3 | CD4066N | 1 | 595-CD4066BE | CD4066BE | X | mouser.com/c/?q=595-CD4066BE | amazon.com/s?k=CD4066BE
U13 | Replaces 7805CV - Switching Regulator | 1 | 495-TSR-1-2450 | TSR 1-2450 | X | mouser.com/c/?q=495-TSR-1-2450 | amazon.com/s?k=TSR%201-2450
U11,U12 | VREG 7809TV | 2 | 511-L7809CV | L7809CV | ✓ | mouser.com/c/?q=511-L7809CV | amazon.com/s?k=L7809CV
XTAL1 | 8MHZ XTAL HC-49S | 1 | 717-9B-8.000MEEJ-B | 815-ABL-8-B2 | X | mouser.com/c/?q=717-9B-8.000MEEJ-B | amazon.com/s?k=815-ABL-8-B2
U1 | ATMEGA 16P | 1 | 556-ATMEGA16A-PU | ATMEGA16A-PU | X | mouser.com/c/?q=556-ATMEGA16A-PU | amazon.com/s?k=ATMEGA16A-PU
LCD1 | LCD HD44780LCD-1602 | 1 | 763-0216K1Z-NSW-BBW | NHD-0216K1Z-NSW-FBW-L | X | mouser.com/c/?q=763-0216K1Z-NSW-BBW | amazon.com/s?k=NHD-0216K1Z-NSW-FBW-L
Q3,Q6 | MOSFET IRF9Z24N P-ch 60V 8A — Vt-matching pool: order 6 total, install 2 closest-matched pair | 6 | 942-IRF9Z24NPBF | IRF9Z24NPBF | X | mouser.com/c/?q=942-IRF9Z24NPBF | amazon.com/s?k=IRF9Z24NPBF
Q1,Q2,Q4,Q5 | MOSFET IRL520N N-ch 100V 10A — Vt pool: order 12, measure all, install 2 closest-matched per channel (Q1+Q2 ch.A, Q4+Q5 ch.B) | 12 | 942-IRL520NPBF | IRL520NPBF | X | mouser.com/c/?q=942-IRL520NPBF | amazon.com/s?k=IRL520NPBF
JP1 | ISP 6 PIN | 1 | 571-5-146254-3 | 5-146254-3 | X | mouser.com/c/?q=571-5-146254-3 | amazon.com/s?k=5-146254-3
U14 | LM2941 | 1 | 926-LM2941CT/NOPB | LM2941CT/NOPB | X | mouser.com/c/?q=926-LM2941CT%2FNOPB | amazon.com/s?k=LM2941CT%2FNOPB
U2 | LM324N | 1 | 595-LM324N | LM324N | ✓ | mouser.com/c/?q=595-LM324N | amazon.com/s?k=LM324N
U10,U4 | LM358N | 2 | 512-LM358N | LM358N | ✓ | mouser.com/c/?q=512-LM358N | amazon.com/s?k=LM358N
LED1,LED2 | Kingbright 5mm Orange diffused (OUTPUT A & B) - Vf 2.0V typ - works as-is with existing 390R at R53/R54 | 2 | 604-WP7113OD | WP7113OD | X | mouser.com/c/?q=604-WP7113OD | amazon.com/s?k=WP7113OD
LED3 | Kingbright 5mm Red diffused (RADIO) - Vf 2.0V typ - works as-is with existing 390R at R59 | 1 | 604-WP7113ID | WP7113ID | X | mouser.com/c/?q=604-WP7113ID | amazon.com/s?k=WP7113ID
LED4 | Kingbright 5mm Green diffused (POWER) - GaP Vf 2.2V typ - works as-is with existing 390R at R60 | 1 | 604-WP7113GD | WP7113GD | X | mouser.com/c/?q=604-WP7113GD | amazon.com/s?k=WP7113GD
U9 | MAX232 | 1 | 700-MAX232CPE | MAX232CPE | X | mouser.com/c/?q=700-MAX232CPE | amazon.com/s?k=MAX232CPE
SOCKET FOR U2,U3 | DIL 14 IC SOCKET gold square-hole (Aries 600-11) | 2 | 535-14-600-11 | 14-600-11 | X | mouser.com/c/?q=535-14-600-11 | amazon.com/s?k=14-600-11
SOCKET FOR U9 | DIL 16 IC SOCKET gold square-hole (Aries 600-11) | 1 | 535-16-600-11 | 16-600-11 | X | mouser.com/c/?q=535-16-600-11 | amazon.com/s?k=16-600-11
SOCKET FOR U1 | DIL 40 IC SOCKET gold square-hole (Aries 600-11) | 1 | 535-40-600-11 | 40-600-11 | X | mouser.com/c/?q=535-40-600-11 | amazon.com/s?k=40-600-11
SOCKET FOR U10,U4,U8(A/B) | DIL 8 IC SOCKET gold square-hole (Aries 600-11) | 4 | 535-08-600-11 | 08-600-11 | X | mouser.com/c/?q=535-08-600-11 | amazon.com/s?k=08-600-11
JP6,JP7 | 2x1 SIP HEADER 0.1 | 2 | 571-5-146285-2 | 5-146285-2 | X | mouser.com/c/?q=571-5-146285-2 | amazon.com/s?k=5-146285-2
VR1, VR2 | ALPS 9mm 10K Pot | 2 | 688-RK09L1140A2U | RK09L1140A2U | X | mouser.com/c/?q=688-RK09L1140A2U | amazon.com/s?k=RK09L1140A2U
VR3 | ALPS 9mm 10K Dual Gang Pot | 1 | 688-RK09L1240A12 | RK09L1240A12 | X | mouser.com/c/?q=688-RK09L1240A12 | amazon.com/s?k=RK09L1240A12
VR4 | Bourns 3362P 10K Pot | 1 | 3362P-1-103LF | 3362P-1-103LF | X | mouser.com/c/?q=3362P-1-103LF | amazon.com/s?k=3362P-1-103LF
S1,S2,S3,S4 | Buttons | 4 | 611-D6C90F2LFS | D6C90 F2 LFS | X | mouser.com/c/?q=611-D6C90F2LFS | amazon.com/s?k=D6C90%20F2%20LFS
J8 | 2.1/5.5mm DC jack | 1 | 490-PJ-002A | PJ-002A | X | mouser.com/c/?q=490-PJ-002A | amazon.com/s?k=PJ-002A
S5 | Toggle Switch with safety actuator | 1 | 611-7101K2AV2BE | 7101K2AV2BE | X | mouser.com/c/?q=611-7101K2AV2BE | amazon.com/s?k=7101K2AV2BE
J9 | Radio Header | 1 | 538-90147-1206 | 90147-1206 | X | mouser.com/c/?q=538-90147-1206 | amazon.com/s?k=90147-1206
Gray button covers | Button Cover | 2 | 611-BTND610F | BTND610F | X | mouser.com/c/?q=611-BTND610F | amazon.com/s?k=BTND610F
White button covers | Button Cover | 2 | 611-BTND600F | BTN D6 00 F | X | mouser.com/c/?q=611-BTND600F | amazon.com/s?k=BTN%20D6%2000%20F
LCD HEADER | LCD Header | 1 | 710-61301611121 | 61301611121 | X | mouser.com/c/?q=710-61301611121 | amazon.com/s?k=61301611121
Knob | Potentiometer Knob | 3 | 450-BA761 | BA761 | X | mouser.com/c/?q=450-BA761 | amazon.com/s?k=BA761
BAT1 Lug (red) | Keystone female crimp lug 22/18 AWG (red) | 1 | 534-8291 | 534-8291 | X | mouser.com/c/?q=534-8291 | amazon.com/s?k=534-8291
BAT1 Lug (blue) | Keystone female crimp lug 16/14 AWG (blue) | 1 | 534-8293 | 534-8293 | X | mouser.com/c/?q=534-8293 | amazon.com/s?k=534-8293
J1A,J1B | PCB male quick-disconnect tab 0.187"/F1 vertical (battery + and −; mates with the 8291 crimps on the battery wire) | 2 | 534-1285 | 1285 | X | mouser.com/c/?q=534-1285 | amazon.com/s?k=Keystone+1285
Power Supply | 18V, 1A .5.5mm OD plug | 1 | 709-GST18U18-P1J | GST18U18-P1J | X | mouser.com/c/?q=709-GST18U18-P1J | amazon.com/s?k=GST18U18-P1J
20K Opt. Variant | RES 18K (optional variant) | 2 | 71-CMF5518K000FHEB | CMF5518K000FHEB | X | mouser.com/c/?q=71-CMF5518K000FHEB | amazon.com/s?k=CMF5518K000FHEB
R30 | RES 0.27R 1W | 1 | 660-MOSX1CT528RR27J | MOSX1CT528RR27J | X | mouser.com/c/?q=660-MOSX1CT528RR27J | amazon.com/s?k=MOSX1CT528RR27J
C4,C5,C6,C7 | Aluminum Organic Polymer Capacitors 25V 1000uF RAD Low ESR (14 mOhm) - upgraded from 470-820uF spec for use with 0.27R at R30 | 4 | 80-A750MV108M1EAAE14 | A750MV108M1EAAE014 | X | mouser.com/c/?q=80-A750MV108M1EAAE14 | amazon.com/s?k=A750MV108M1EAAE014
J2,J3,J4,J5,J6,J7 | Phone Connectors 3.5mm PCB STEREO BLK 5P W/SWITCH | 6 | 806-STX-3100-5N | STX-3100-5N | X | mouser.com/c/?q=806-STX-3100-5N | amazon.com/s?k=STX-3100-5N
TR1,TR2 | Audio Transformers / Signal Transformers XFMR OUT 200CT-8 3.2 | 2 | 42TU200-RC | 42TU200-RC | X | mouser.com/c/?q=42TU200-RC | amazon.com/s?k=42TU200-RC
PACTEC Case | Case | 1 | 616-63025-510-000 | 63025-510-000 | X | mouser.com/c/?q=616-63025-510-000 | amazon.com/s?k=63025-510-000
U8A | Digital to Analog Converters - DAC uP 2x 10-B DAC in MS | 1 | 584-LTC1661IN8#PBF | LTC1661IN8#PBF | X | mouser.com/c/?q=584-LTC1661IN8%23PBF | amazon.com/s?k=LTC1661IN8%23PBF
Ribbon Cable | Samtec IDSD-12-D-03.00 24-cond IDC socket 3.00in | 1 | 200-IDSD12D0300 | IDSD-12-D-03.00 | X | mouser.com/c/?q=200-IDSD12D0300 | amazon.com/s?k=IDSD-12-D-03.00
Battery | 12V 2.5AH Sealed Lead Acid Battery | 1 | 547-PS-1220F1 | PS-1220F1 |  | mouser.com/c/?q=547-PS-1220F1 | amazon.com/s?k=PS-1220F1
C8 | 10 uF 50V 77 mOhms ORganic aluminum Polymer Capacitor | 1 | 581-RPF0508100M050K | RPF0508100M050K |  | mouser.com/c/?q=581-RPF0508100M050K | amazon.com/s?k=RPF0508100M050K
 |  |  |  |  | X
Misc
- Hardware
 | M2.5 x 20mm socket head screw (Front panel screws) | 4 |  |  |  |  | amazon.com/s?k=M2.5%20x%2020mm%20socket%20head%20screw%20%28Front%20panel%20screws%29
 | #4 x 1/4" sheet metal screw (Main board to case) | 6 |  |  |  |  | amazon.com/s?k=%234%20x%201%2F4%22%20sheet%20metal%20screw%20%28Main%20board%20to%20case%29
 | M2.5 nut (Front panel nut) | 22 |  |  |  |  | amazon.com/s?k=M2.5%20nut%20%28Front%20panel%20nut%29
 | 18 Gauge Wire Black | 300mm |  |  |  |  | amazon.com/s?k=18%20Gauge%20Wire%20Black
 | 18 Gauge Wire Red | 300mm |  |  |  |  | amazon.com/s?k=18%20Gauge%20Wire%20Red
- Wireless Module (pick ONE — bluetooth OR wifi)
 | Bluetooth Module HC-05 — DSD Tech Pass-through (B01G9KSAF6) RECOMMENDED: pin 32 STATE pre-soldered to breakout (drives front-panel Radio LED — the #1 fiddly step on generic clones), reliable AT-mode firmware. Works with Bluetooth-classic clients on Win/Linux/Android — macOS Monterey+ has poor SPP support, use WiFi adapter instead | 1 |  |  |  |  | amazon.com/dp/B01G9KSAF6
 | (see BOM_full_WiFi.csv for the wifi adapter alternative)
- PC Link Cable (optional — required only for clients that talk to the LINK port instead of bluetooth/wifi adapter)
 | DSD TECH USB to RS232 cable (FT232RL chip) — connects PC to MK-312 LINK port; works with mk312-gui / three-twelve-bee / ErosWeb on Win/Mac/Linux | 1 |  |  |  |  | amazon.com/dp/B07XXWVH69
Build Tools
 | Component tester (LCR-P1 or LCR-T7 2-decimal Mega328 variant — REQUIRED for IRL520N / IRF9Z24N Vt matching to prevent Error 20. Plain 1-decimal Mega328 testers only resolve to ~50 mV which is useless for sorting at the 20-30 mV matching tolerance — see ../2-order-parts/README.md for procedure) | 1 |  |  |  |  | amazon.com/s?k=LCR-P1+component+tester
 | Backup / sanity tester (Mega328 1-decimal — use for absolute Vt sanity check, dead-FET detection, resistor/cap/diode tests; NOT precise enough for matching) | 1 |  |  |  |  | amazon.com/dp/B0DDBPWYP8
Firmware Flashing
 | USBasp programmer for ISP — KeeYees with 10→6-pin adapter. Cheapest option but ships WITHOUT the J1 jumper installed (status LEDs stay dark — flashing still works, you just can't see activity). Either drop a 0.1" jumper cap on J1 yourself, or pick a better one: see build-guide.md "Pick a programmer" — DIYmall B08F9FZKP9 (jumper installed), Adafruit USBtinyISP, or DIAMEX USB-ISP V4 are sturdier picks. | 1 |  |  |  |  | amazon.com/dp/B0885RKVMC
 | USB to TTL 5PIN Serial Converter (for HC-05 AT-mode config flashing) | 1 |  |  |  |  | amazon.com/dp/B07D6LLX19

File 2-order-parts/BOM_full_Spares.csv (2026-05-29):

Last modified: 2026-05-29
Designator | Description | Quantity | Mouser Part # | Manufacturer Part # | Sourced? | Mouser URL | Amazon URL
 |  | NOTE: These parts are ordered in excess of PCB footprint count. MOSFET spares are for Vt-threshold matching — test the full pool and install the closest-matched units. Crystal and resistor spares are insurance against handling damage.
XTAL1 (spare) | 8MHZ XTAL HC-49S | 1 | 717-9B-8.000MEEJ-B | 815-ABL-8-B2 | X | mouser.com/c/?q=717-9B-8.000MEEJ-B | amazon.com/s?k=815-ABL-8-B2
Q3,Q6 pool remainder | MOSFET IRF9Z24N P-ch 60V 8A — pool remainder after Vt matching: full pool of 6 ordered via main BOM, these 4 are surplus after selecting the closest-matched pair | 4 | 942-IRF9Z24NPBF | IRF9Z24NPBF | X | mouser.com/c/?q=942-IRF9Z24NPBF | amazon.com/s?k=IRF9Z24NPBF
Q1,Q2,Q4,Q5 pool remainder | MOSFET IRL520N N-ch 100V 10A — surplus after selecting 2 closest-matched per channel (Q1+Q2 ch.A, Q4+Q5 ch.B) from pool of 12 | 8 | 942-IRL520NPBF | IRL520NPBF | X | mouser.com/c/?q=942-IRL520NPBF | amazon.com/s?k=IRL520NPBF
R35,R46 spares | RES 200K CMF55 1/4W metal film | 2 | 71-CMF55200K00FHEB | CMF55200K00FHEB | X | mouser.com/c/?q=71-CMF55200K00FHEB | amazon.com/s?k=CMF55200K00FHEB
R30 spares | RES 0.27R 1W metal oxide | 2 | 660-MOSX1CT528RR27J | MOSX1CT528RR27J | X | mouser.com/c/?q=660-MOSX1CT528RR27J | amazon.com/s?k=MOSX1CT528RR27J

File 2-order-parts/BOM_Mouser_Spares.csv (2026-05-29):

Mouser Part Number | Quantity | Manufacturer Part Number | Customer Part Number | Description
717-9B-8.000MEEJ-B | 1 | 815-ABL-8-B2 | XTAL1 (spare) | 8MHz XTAL HC-49S (spare)
942-IRF9Z24NPBF | 4 | IRF9Z24NPBF | Q3,Q6 pool remainder (main BOM orders 6 total — install 2 closest-matched pair, these 4 are surplus after matching) | MOSFET P-ch 60V 8A IRF9Z24N
942-IRL520NPBF | 8 | IRL520NPBF | Q1,Q2,Q4,Q5 pool remainder (install 2 closest-matched per channel: Q1+Q2 ch.A, Q4+Q5 ch.B — 8 surplus after selecting best 4) | MOSFET N-ch 100V 10A IRL520N
71-CMF55200K00FHEB | 2 | CMF55200K00FHEB | R35,R46 spares | RES 200K
660-MOSX1CT528RR27J | 2 | MOSX1CT528RR27J | R30 spares | RES 0.27R 1W Metal Oxide

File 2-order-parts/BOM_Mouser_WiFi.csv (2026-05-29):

Mouser Part Number | Quantity | Manufacturer Part Number | Customer Part Number | Description
750-AMS1117-3.3 | 1 | AMS1117-3.3 | U1 (WiFi PCB) — SMD SOT-223 — DO NOT ORDER if using JLCPCB PCBA SMT assembly (LCSC C6186 factory-fitted) | LDO REG 3.3V SOT-223 (SKIP if using JLC PCBA)
80-C320C104K5R | 2 | C320C104K5R5TA | C1,C2 (WiFi PCB) | CAP 0.1uF 50V
512-PN2222ABU | 1 | PN2222ABU | Q1 (WiFi PCB) | TRANS. PN2222A NPN
653-B3F-1000 | 1 | B3F-1000 | SW1 (WiFi PCB) | Tactile Switch SPST
571-826629-6 | 1 | 826629-6 | J1 (WiFi PCB) | TE 6-pin Connector
200-PPPC042LFBN-RC | 1 | PPPC042LFBN-RC | J2 (WiFi PCB) | 4-pin Socket 2x2

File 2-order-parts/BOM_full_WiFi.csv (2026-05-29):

Last modified: 2026-05-29
Designator | Description | Quantity | Mouser Part # | Manufacturer Part # | Sourced? | Mouser URL | Amazon URL
 |  | NOTE: This is the WiFi adapter PCB BOM. The AMS1117-3.3 LDO regulator is an SMD SOT-223 part. If ordering via JLCPCB PCBA (recommended) it is factory-assembled — DO NOT order from Mouser. Only the 5 through-hole parts (C1 C2 Q1 SW1 J1 J2) need to be hand-soldered by the builder.
U1 (WiFi PCB) | AMS1117-3.3 LDO 3.3V regulator SOT-223 — SMD factory-assembled by JLCPCB PCBA (LCSC C6186) — DO NOT ORDER from Mouser if using JLC SMT assembly service | 1 | 750-AMS1117-3.3 | AMS1117-3.3 |  | mouser.com/c/?q=750-AMS1117-3.3 | amazon.com/s?k=AMS1117-3.3
C1,C2 (WiFi PCB) | CAP 0.1uF (0.1" spacing) 50V | 2 | 80-C320C104K5R | C320C104K5R5TA | X | mouser.com/c/?q=80-C320C104K5R | amazon.com/s?k=C320C104K5R5TA
Q1 (WiFi PCB) | TRANS. PN2222A NPN | 1 | 512-PN2222ABU | PN2222ABU | X | mouser.com/c/?q=512-PN2222ABU | amazon.com/s?k=PN2222ABU
SW1 (WiFi PCB) | Omron B3F-1000 SPST tactile switch | 1 | 653-B3F-1000 | B3F-1000 | X | mouser.com/c/?q=653-B3F-1000 | amazon.com/s?k=B3F-1000
J1 (WiFi PCB) | TE 826629-6 6-pin connector | 1 | 571-826629-6 | 826629-6 | X | mouser.com/c/?q=571-826629-6 | amazon.com/s?k=826629-6
J2 (WiFi PCB) | Samtec PPPC042LFBN-RC 4-pin socket | 1 | 200-PPPC042LFBN-RC | PPPC042LFBN-RC | X | mouser.com/c/?q=200-PPPC042LFBN-RC | amazon.com/s?k=PPPC042LFBN-RC

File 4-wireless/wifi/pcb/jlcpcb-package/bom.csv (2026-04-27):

Comment | Designator | Footprint | LCSC Part #
AMS1117-3.3 | U1 | SOT-223-3 | C6186

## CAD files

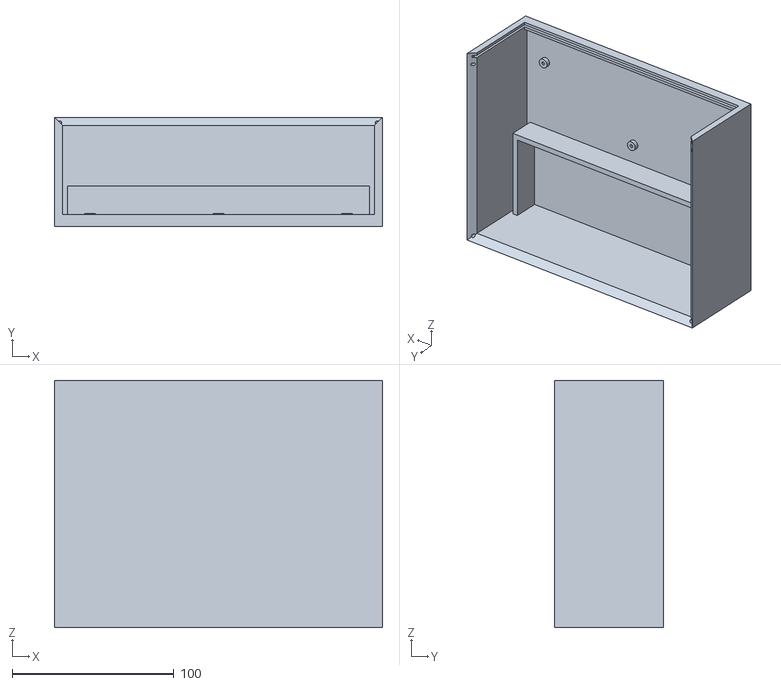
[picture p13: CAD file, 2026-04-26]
3-build-and-flash/case/case_v1.26.stl
203.0 x 67.5 x 153.0

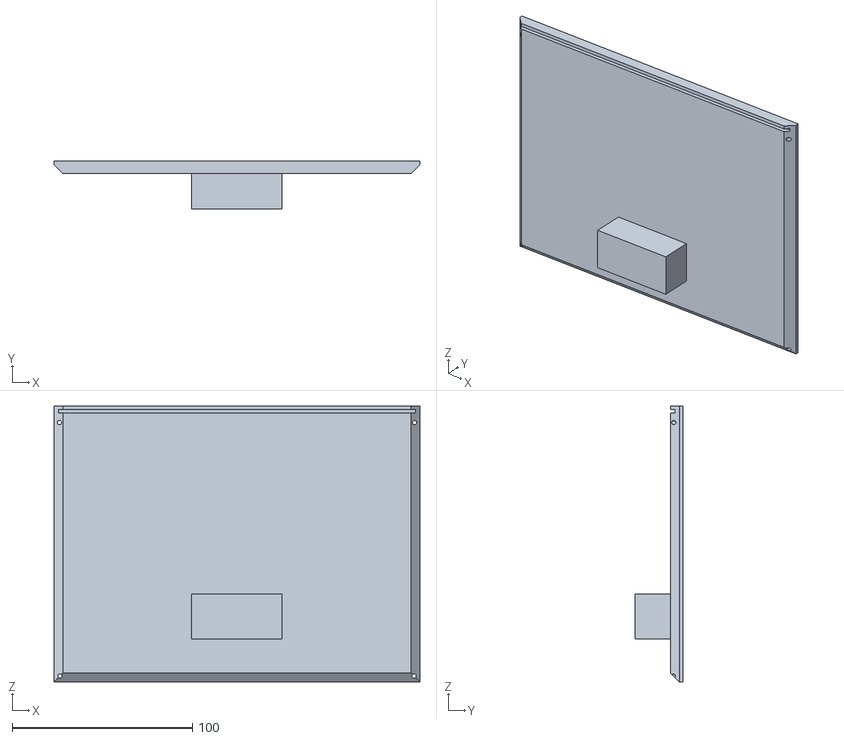
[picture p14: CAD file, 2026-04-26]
3-build-and-flash/case/lid_v1.26.stl
203.0 x 26.5 x 153.0

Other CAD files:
3-build-and-flash/case/case_v1.26.f3d

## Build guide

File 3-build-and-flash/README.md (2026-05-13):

# Step 3 — Build and flash

Boards arrived, parts arrived. Time to solder, print the case, flash the AVR.

The full walkthrough — assembly checklist, MOSFET matching, firmware flashing for macOS/Linux/Windows, fuse settings, HC-05 configuration — is in [`build-guide.md`](../build-guide.md) at the repo root.

## What's in this directory

| | |
|---|---|
| [`firmware/`](firmware/) | Pre-built `.bin` files for the ATmega16A + a quick-reference avrdude command |
| [`case/`](case/) | 3D-printable case STL + Fusion 360 source (v1.26) |
| [`troubleshooting/`](troubleshooting/) | Failure-code analyses, board test methodology, archived metafetish forum threads |

## Hardware you'll need (beyond the BOM)

- **AVR programmer** for the 6-pin ISP header (JP1) — USBasp clone ([B0885RKVMC](https://amazon.com/dp/B0885RKVMC) includes the 10→6-pin adapter) or anything avrdude supports
- **Case hardware** — 4× M2.5×20 screws, up to 3× M2.5×5 screws, double-sided foam tape for battery dampening

## When something goes wrong

- **Error 20 on first boot** → almost always mismatched MOSFETs. See [`troubleshooting/debug-notes/failure-20-analysis.md`](troubleshooting/debug-notes/failure-20-analysis.md) for the R32/R43 diagnostic and the pre-build matching procedure.
- **LCD shows solid blocks, no text** → see [`troubleshooting/debug-notes/board-test-methodology.pdf`](troubleshooting/debug-notes/board-test-methodology.pdf) for the bench procedure.
- **Anything else** → [`troubleshooting/`](troubleshooting/) has every other failure code and the metafetish forum archive.

→ Next: [Step 4 — Wireless control](../4-wireless/)

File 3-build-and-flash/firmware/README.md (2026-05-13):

# Firmware

Pre-built `.bin` files ready to flash to the ATmega16A on the main board.

| File | What it is |
|---|---|
| `cr-custom-boot-messages/f005-HelloFriend.bin` | **Default application firmware.** Patched frankenbutt-f005 with "Hello Friend" boot screen. Flash this and the box runs. |
| `cr-custom-boot-messages/f005-ElectrodesReady.bin` | Alternative: same f005 build, "Electrodes Ready" boot screen |
| `other-fw/f005.bin` | Alternative: unpatched frankenbutt-f005, no custom boot message |
| `backup_eeprom.bin`, `backup_flash.bin` | Reference dumps from a working unit (read with `avrdude -U eeprom:r:... -U flash:r:...`). Source for the disassembly-based [`../troubleshooting/debug-notes/`](../troubleshooting/debug-notes/) analyses. |

All bundled `.bin` files include the LCD character-map fix (left/right arrows instead of up/down) and work with the MK-312BT's stock display.

## How to flash

See **[`build-guide.md` → Firmware: flashing the AVR](../../build-guide.md#firmware-flashing-the-avr)** for the full Win/Mac/Linux walkthrough — programmer choice, avrdude install per platform, fuse settings, and exact commands for both USBasp and Arduino-as-ISP.

Quick reference (USBasp, all platforms):

```sh
# Set fuses (do this once per chip)
avrdude -c usbasp -p m16 -U lfuse:w:0xFF:m -U hfuse:w:0xDC:m

# Flash firmware
avrdude -c usbasp -p m16 -U flash:w:cr-custom-boot-messages/f005-HelloFriend.bin
```

## Source

The firmware is a patched version of **buttshock-et312-frankenbutt-f005**. The patches handle the LCD character-map differences. To rebuild from source, see the upstream buttshock project.

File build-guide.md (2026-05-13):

# MK-312BT build guide

Comprehensive end-to-end walkthrough — board ordering, parts, assembly, firmware, and HC-05 bluetooth configuration. For the at-a-glance journey, see the [root README](README.md).

## Provenance

The "original" content here came from the `metafetish/mk312-bt` repo at the point it was deleted (~27 Dec 2020), preserved by [CrashOverride85](https://github.com/CrashOverride85/mk312-bt). v1.4 files (gerbers, schematics, notes — no Eagle source) were DM'd to that maintainer shortly after the original was deleted; provenance of v1.4 itself is hazy but the design has been successfully built by several people. See the [v1.4 release notes](1-order-boards/v1.4-release-notes.txt) for changes vs v1.3 before ordering parts.

The metafetish.club forum is now offline — surviving posts are archived in [`3-build-and-flash/troubleshooting/`](3-build-and-flash/troubleshooting/).

The active community lives in the `#boxes-pulse-based-diy` and `#312-chat` channels on [Joanne's E-Stim Community Discord](https://discord.gg/rY8C27S).

## Parts ordering information

See the Documentation link above for BOMs.

Prebuilt Mouser cart for electronic components of the v1.3R board:
https://www.mouser.com/ProjectManager/ProjectDetail.aspx?AccessID=a2725b2f11

You will still need screws/standoffs/cases etc, which can be sourced
elsewhere as listed in the spreadsheet.

## Board ordering instructions

Preferred board house is https://jlcpcb.com

You'll need 2 gerber zip files (click links to download):

- [v1.2 Front Panel](1-order-boards/gerbers/v1.2-front-panel.zip) — the front panel design hasn't changed since v1.2
- [v1.4 Main Board](1-order-boards/gerbers/v1.4-main-board.zip) — current main board revision

**NOTE:** Order Front Panel and Main Board as seperate items (but they
can be in the same cart), due to difference in "Different Design"
setting. See below.

- 2 Layer PCB and Dimensions should be detected when you upload the
  zip with the gerbers
- Quantity: No requirement, choose whatever you like
- Thickness: 1.6
- PCB Color:
   - Main Boards: No requirement, choose whatever you like
   - Front Panel: Black is recommended, but not required. Choose whatever you like otherwise.
- Surface finish: HASL
- Copper weight: 1oz
- Gold fingers: No
- Material: Standard FR4
- Panel by jlcpcb: No
- Different Design 
   - Main Boards: 2
   - Front Panel: 1
- Remarks:
   - Main Boards: V Score the Main Boards panel as indicated.
   - Front Panel: Place all Fab Markings (Serial Numbers/Date Codes) on the BOTTOM side of the front panel board.
   
## Error 20: match the MOSFETs before you solder

Error 20 is by far the most common first-boot failure. It almost always traces to mismatched MOSFETs — when the IRL520 quartet or the IRF9Z24 pair have meaningfully different gate threshold voltages (Vt), the output stage can't keep R32 and R43 balanced and the firmware throws Error 20. The DAC (LTC1661) can contribute too, but the MOSFETs are the dominant cause and the only one you can prevent with five minutes of measurement.

**Before soldering**, measure the Vt of every IRL520 and every IRF9Z24 with a component tester (a cheap one that works fine: [amazon.com/dp/B0DDBPWYP8](https://www.amazon.com/dp/B0DDBPWYP8)). Group them by Vt and pick a tight set for each board:

- Bad set — `Vt = 1.82 V, 1.91 V, 2.21 V, 2.34 V` — half a volt of spread, will probably throw Error 20
- Good set — `Vt = 1.90 V, 1.91 V, 1.91 V, 1.92 V` — within ~20 mV, works reliably

Use four closely-matched IRL520s for one board, and likewise pair up the two IRF9Z24s.

**If the board is already built and Error 20 shows up**, measure the DC voltage across R32 and across R43 with the unit powered on:

- Both should read between **4.0 V and 4.4 V**.
- Far more important: **the two readings should be very close to each other**. A clear difference between R32 and R43 is the smoking gun for a MOSFET mismatch.

If R32 and R43 are matched and in range, the FETs aren't the issue — check FET orientation, transformer orientation, and that R35/R46 are 200 kΩ. If R32 and R43 are mismatched, the practical fix is to desolder the MOSFETs and drop in a matched set.

Background reading: [`3-build-and-flash/troubleshooting/MK-312BT Failure 20 - Estim - Metafetish.pdf`](3-build-and-flash/troubleshooting/MK-312BT%20Failure%2020%20-%20Estim%20-%20Metafetish.pdf).

## Board Assembly Instructions - IMPORTANT

1. Trim Potentiometer knobs to correct length if desired
2. Use black permanent marker to black out front panel hole walls if
   desired
3. Cut the tabs off of the base of the pots so the board sits flush
   with the display facade if desired
4. To correctly fit LCD - solder header to LCD board first. Next
   insert LCD panel into front panel daughter board. Then put screws
   on front panel facade and finger tighten M2.5 screws first. Adjust
   positions as needed so everything lines up and sits well. Finally
   solder LCD header to front panel daughter board.
5. Make sure Pin 32 (LED2) on the HC-05 module is actually soldered
   and making connection to the ZS-040 break out board or "Radio" LED
   may not function on the front panel
6. Be very careful not to bridge pins when soldering the LM 2941
   (U14). Apply heat to 1 pad only and carefully apply solder. If a
   bridge occurs - remove the IC, clean the pads throughly with flux
   and solder wick and then retry. Pins 2 and 3 can be bridged because
   they are both ground. Ensure that no other pins are bridged. Check
   with multimeter continuity tester for bridges before power on!
7. Make sure to check the orientation of all electrolytic caps. (+)
   indicates the positive and a solid white "|" indicates the negative.
8. **MAKE SURE YOUR POWER PLUG IS CENTER POSITIVE OR THINGS WILL GO
   BADLY.** If you fuck up and plug in a reversed polarity supply -
   replace electrolytic caps C1 and C4.
9. Please remember to adjust the LCD contrast potentiometer - if
   incorrectly set the unit and backlight will power on but the
   interface will not be displayed.
10. Place transformers with P facing the output jacks (yes we are
    using the transformers "backwards" if you follow orientation given
    in the transformer datasheet )
11. Trim pins of 4066 IC (U3) Socket on the front panel board flush
    before soldering so buttons can clear. If the buttons still
    interfere, carefully disassemble the button and cut off the bit of
    the plastic housing that interferes with the 4066 IC socket pins.
12. Using side cutters cut off the screw boss/screw mount on the case
    that touches/interferes with the ribbon cable socket on the
    display board.
13. The LCD display has metal retention tabs that may short the
    soldered leads of C43. When installing the display board ensure
    that this does not happen (shorten the capacitor leads and bend
    the offending metal tab out of the way if necessary
14. If Error 20 is encountered on first boot, see the **Error 20** section above — it covers MOSFET matching (the usual cause) and the R32/R43 voltage check that diagnoses it.

## Firmware: flashing the AVR

The board uses an **ATmega16A** clocked from an external **8 MHz crystal**. Flashing has three steps regardless of platform: connect a programmer to the 6-pin ISP header (JP1), set fuses so the chip uses the crystal, then write the firmware. The firmware itself is a raw `.bin` file that you can pull straight out of [`3-build-and-flash/firmware/`](3-build-and-flash/firmware/).

### Pick a firmware

| File | What it is |
|---|---|
| `cr-custom-boot-messages/f005-HelloFriend.bin` | **Recommended default.** Patched frankenbutt-f005 with a "Hello Friend" boot screen. Flash this and the box runs. |
| `cr-custom-boot-messages/f005-ElectrodesReady.bin` | Alternative: same f005 build, "Electrodes Ready" boot screen. |
| `other-fw/f005.bin` | Alternative: unpatched frankenbutt-f005, no custom boot message. |

All bundled `.bin` files include the LCD character-map fix (left/right arrows instead of up/down). If you just want a working box, flash `f005-HelloFriend.bin`.

### Pick a programmer

Ranked from "just buy this" to "if you have one already":

| Programmer | Cost | Why pick it |
|---|---|---|
| **[Adafruit USBtinyISP v2.0](https://www.adafruit.com/product/46)** | ~$22 | Drop-in for the USBasp use case (use `-c usbtiny` instead of `-c usbasp`). Adafruit-quality build, current firmware, includes 6-pin and 10-pin ribbon cables, status LEDs work out of the box. **Best balance of reliability and price.** |
| **[DIAMEX USB-ISP-Programmer V4](https://www.diamex.de/dxshop/USB-ISP-Programmer-PROG-USB-V4)** | ~$25 | German-made, current USBasp firmware, no driver dance. Best choice if you'll flash more than one board. Use `-c usbasp`. |
| **[Pololu USB AVR Programmer v2.1](https://www.pololu.com/product/3172)** | ~$22 | Speaks STK500v2 (use `-c stk500v2`), exceptionally reliable, includes 6-pin cable and integrated USB-to-serial adapter — bonus, you can use it for the LINK port too. |
| **DIYmall USBasp** ([Amazon B08F9FZKP9](https://www.amazon.com/dp/B08F9FZKP9)) | ~$10 | Cheapest option that explicitly ships with the **jumper cap installed** (lights the activity LEDs) and the **10→6-pin adapter included**. The defaults that the BOM pick (B0885RKVMC) is missing. |
| **HiLetgo USBasp** ([Amazon B00AX4WQ00](https://www.amazon.com/HiLetgo-ATMEGA8-Programmer-USBasp-Cable/dp/B00AX4WQ00)) | ~$8 | Most popular cheap clone. Has power + write LEDs; verify the listing includes the 6-pin adapter (varies by seller revision). |
| **Arduino UNO/Nano + ArduinoISP sketch** | $0 if you have one | Slower but uses what you already own. Uses `-c avrisp` — see [Arduino-as-ISP](#flash-with-arduino-as-isp) below. |
| **[Atmel-ICE](https://www.microchip.com/en-us/development-tool/ATATMEL-ICE)** | $80–100 | Microchip's official tool. Overkill unless you're doing real AVR work. Use `-c atmelice_isp`. |

> ⚠️ **The current BOM pick — KeeYees [B0885RKVMC](https://amazon.com/dp/B0885RKVMC) — works but has a real problem:** it ships **without the J1 jumper installed**, so the status LEDs stay dark and you can't tell if the USBasp is actually doing anything. The fix is either to drop a 0.1" jumper cap on J1 yourself ($0.50 in any electronics drawer) or to pick one of the better options above. For a single build the KeeYees is fine if you don't mind blind-flashing; for a kit you'll use again, the Adafruit USBtinyISP is the real recommendation.

**Cheap-clone gotchas in general:**
- **Stale firmware** → slow SPI. Add `-B 8` to the avrdude command if you get sync errors. Higher = slower.
- **Proprietary non-USBasp firmware** → some ship with AT89-style firmware that avrdude can't talk to. If your OS sees "USBTiny" or similar instead of "USBasp," return it.
- **Missing 10→6-pin adapter** → the MK-312BT's ISP header (JP1) is 6-pin, not the 10-pin standard the USBasp output uses. Verify the listing includes the adapter or buy one separately for ~$2.
- **Missing or absent jumpers** → JP1/J1 controls LED activity on most clones; without it, no visible feedback. Dropping a jumper cap on yourself is fine if you're comfortable with that.

### Install avrdude

#### macOS (Homebrew)

```sh
brew install avrdude
```

That's it. USBasp works out of the box, no driver setup.

#### Linux (Debian / Ubuntu / Mint)

```sh
sudo apt install avrdude
```

For non-root USB access add a udev rule (otherwise you'll need `sudo` on every flash):

```sh
sudo tee /etc/udev/rules.d/99-usbasp.rules <<'EOF'
SUBSYSTEM=="usb", ATTR{idVendor}=="16c0", ATTR{idProduct}=="05dc", GROUP="plugdev", MODE="0666"
EOF
sudo udevadm control --reload-rules
sudo usermod -aG plugdev $USER   # log out and back in for this to take effect
```

#### Windows

1. Install avrdude. Pick one:
   - [WinAVR](https://sourceforge.net/projects/winavr/) — bundles avrdude + GCC, last release is dated but works fine for flashing
   - Standalone modern build from [mariusgreuel/avrdude](https://github.com/mariusgreuel/avrdude/releases)
   - GUI wrapper if you want one: [AVRDUDESS](https://github.com/ZakKemble/AVRDUDESS)
2. Plug the USBasp in. Windows will fail to install a driver — expected.
3. Install [Zadig](https://zadig.akeo.ie/), select **USBasp** in the device dropdown, set the driver target to **libusb-win32**, click **Replace Driver**.
4. avrdude can now talk to the USBasp.

### The three things you actually need to do

Everything else above is supporting detail. The actual flashing is three commands. If you understand what each flag means, you can adapt them to any programmer / chip / firmware file.

#### Step 1 — Identify your programmer's avrdude name

avrdude doesn't auto-detect what's plugged in; you have to tell it via the `-c` flag. Here's what to use:

| Hardware you have | `-c` flag value |
|---|---|
| USBasp clone (the BOM pick, the HiLetgo, the DIAMEX, basically anything labeled "USBasp") | `usbasp` |
| Arduino UNO/Nano running the ArduinoISP sketch | `avrisp` (and you'll also need `-P <port> -b 19200`) |
| Atmel/Microchip Atmel-ICE | `atmelice_isp` |
| Atmel AVRISP mkII | `avrispmkII` |

Don't know what you've got? List every supported programmer:

```sh
avrdude -c help 2>&1 | head -40
```

For this guide we'll use `-c usbasp` since that's what the BOM lists.

#### Step 2 — Set the fuses

Fuses are tiny configuration bits stored in the chip that control hardware behavior — most importantly, where the chip gets its clock from. The MK-312BT board has an external 8 MHz crystal soldered on, but the ATmega16 ships configured for its slow internal RC oscillator. You have to switch it once per chip.

```sh
avrdude -c usbasp -p m16 -U lfuse:w:0xFF:m -U hfuse:w:0xDC:m
```

What each flag means:

| Flag | Meaning |
|---|---|
| `avrdude` | The flasher program itself |
| `-c usbasp` | Use the USBasp programmer (from Step 1) |
| `-p m16` | Target chip is an ATmega16. (`m16a` works too — the A is silicon revision, same fuse map) |
| `-U lfuse:w:0xFF:m` | **U**pload to memory area `lfuse` (low fuse byte), action `w` (write), value `0xFF`, format `m` (immediate, the value is right there in the command) |
| `-U hfuse:w:0xDC:m` | Same idea for the high fuse byte: write `0xDC` |

**Why `0xFF` and `0xDC`?** Those values configure: external 8+ MHz crystal, JTAG disabled, EEPROM preserved across flashes, brownout detector at 4.3 V. Full bit-by-bit breakdown in the [Fuse byte reference](#fuse-byte-reference) below.

> ⚠️ **Don't fat-finger the fuse values.** Wrong fuses can lock the chip out of ISP — recovering it requires a high-voltage parallel programmer. Copy/paste the command above; don't retype.

avrdude will read the current fuses, write the new values, and read them back to verify. Look for `lfuse verified` and `hfuse verified`.

#### Step 3 — Flash the firmware

```sh
avrdude -c usbasp -p m16 -U flash:w:f005-HelloFriend.bin
```

Same flags as before, with one new `-U` operation:

| Flag | Meaning |
|---|---|
| `-U flash:w:f005-HelloFriend.bin` | Memory area `flash` (program code), action `w` (write), source = the file `f005-HelloFriend.bin`. avrdude auto-detects the file format from the extension (`.bin` = raw binary, `.hex` = Intel HEX). |

avrdude erases flash, writes the new firmware, then reads it back byte-for-byte to verify. Takes ~30 seconds on a USBasp. You'll see `verified` at the end if all good.

Power-cycle the box and you should see the boot screen.

#### Useful extra flags

| Flag | When to add it |
|---|---|
| `-v` | Verbose. Shows what avrdude is doing — add it any time something's not working. |
| `-B 8` | Slow down the SCK (clock) line. Cheap USBasp clones often need this if you get "target doesn't answer." Higher number = slower. Try `-B 32` if `-B 8` doesn't help. |
| `-n` | Dry run / no-write. Reads but doesn't write. Useful for testing the connection before committing to a fuse change. |
| `-e` | Erase chip first (avrdude does this automatically before `flash:w:`, so you rarely need it explicitly). |
| `-P <port>` | Specify the serial port. Only needed for serial-based programmers like Arduino-as-ISP — USBasp uses libusb and doesn't need a port. |
| `-b <baud>` | Baud rate. Same: only for serial-based programmers (Arduino-as-ISP needs `-b 19200`). |

#### Test the connection before flashing

Optional but useful — run avrdude in just-look-at-the-chip mode to confirm the wiring is right before you commit:

```sh
avrdude -c usbasp -p m16 -v
```

Expect `AVR device initialized and ready to accept instructions` followed by the device signature `0x1e9403` (ATmega16) or `0x1e9489` (ATmega16A). If something goes wrong, see [Troubleshooting](#troubleshooting-flashing) below — don't start adding flags blindly.

### First-time walkthrough (USBasp on macOS — same idea on Linux/Windows)

> **For a normal build with reputable parts, the four commands below should just work.** No `-B 8`, no `-F`, no slow-SCK tricks, no driver gymnastics. Workarounds belong in the troubleshooting section, not the happy path.

**1. Plug the USBasp into your computer.** USB cable to your Mac/PC. ISP cable not yet connected to the board.

**2. Connect the USBasp to the board's ISP header (JP1).** Use the 10→6-pin adapter that came with the USBasp. Pin 1 on both ends — a small triangle on the silkscreen, a red stripe on the ribbon cable. Match them.

**3. Power the board** with its normal 18 V supply.

**4. Verify the chip:**

```sh
avrdude -c usbasp -p m16 -v
```

Expect `Device signature = 0x1e9403` (ATmega16) or `0x1e9489` (ATmega16A). That confirms the programmer reached the chip.

**5. Set the fuses** (once per chip):

```sh
avrdude -c usbasp -p m16 -U lfuse:w:0xFF:m -U hfuse:w:0xDC:m
```

Look for `lfuse verified` and `hfuse verified`.

**6. Flash the firmware:**

```sh
cd /path/to/mk312-bt/3-build-and-flash/firmware/cr-custom-boot-messages
avrdude -c usbasp -p m16 -U flash:w:f005-HelloFriend.bin
```

Progress bars, then `verified`. About 30 seconds on a USBasp.

**7. Disconnect, power-cycle, smile.** Pull the ISP cable, unplug the 18 V supply, plug it back in. The LCD should show "Hello Friend" briefly, then the main menu. If you get **Error 20**, see the [Error 20 section](#error-20-match-the-mosfets-before-you-solder) above — that's a hardware problem, not a flashing problem.

### Troubleshooting flashing

Most builds don't need this section. If steps 4–6 above fail, work through these checks **in order** — diagnose first, apply the targeted fix.

```mermaid
flowchart TD
    accTitle: AVR flashing troubleshooting decision tree
    accDescr: Diagnostic flow for avrdude failures. First check whether the OS sees the programmer, then check whether the programmer can reach the chip, then check whether the signature is valid.

    start(["avrdude failed"])
    sees_prog{"OS sees the<br/>programmer?"}
    fix_usb["Try different USB cable/port<br/>brew reinstall avrdude (macOS)<br/>Re-run Zadig (Windows)<br/>Re-check udev rule (Linux)"]
    reaches_chip{"Programmer reaches<br/>chip?<br/>(Device signature reads)"}
    fix_cable["Flip ISP cable orientation<br/>Check board is powered<br/>If still bad: -B 8 to slow SCK<br/>(only after the above)"]
    valid_sig{"Signature is<br/>0x1e9403 or<br/>0x1e9489?"}
    bad_prog["Signature like 0x1e0000 or 0x000000<br/>= programmer/cable fault.<br/>Try a different programmer.<br/>Cross-test with ATmega328P:<br/>avrdude -c usbasp -p m328p"]
    proceed(["Proceed to step 5<br/>(set fuses)"])

    start --> sees_prog
    sees_prog -->|no| fix_usb
    sees_prog -->|yes| reaches_chip
    reaches_chip -->|no| fix_cable
    reaches_chip -->|yes| valid_sig
    valid_sig -->|no| bad_prog
    valid_sig -->|yes| proceed

    classDef bad fill:#fee2e2,stroke:#dc2626,stroke-width:2px,color:#7f1d1d
    classDef question fill:#fef9c3,stroke:#ca8a04,stroke-width:2px,color:#713f12
    classDef good fill:#dcfce7,stroke:#16a34a,stroke-width:2px,color:#14532d

    class fix_usb,fix_cable,bad_prog bad
    class sees_prog,reaches_chip,valid_sig question
    class start,proceed good
```

**Programmer not detected** — `could not find USB device with vid=0x16c0 pid=0x5dc`:

| OS | Confirm what's plugged in | If missing |
|---|---|---|
| macOS | `system_profiler SPUSBDataType \| grep -A 4 -i usbasp` — expect VID `0x16c0`, PID `0x05dc` | Different USB cable / port. USB-C-only Mac? Try a powered USB-A → C adapter. `brew reinstall avrdude`. |
| Linux | `lsusb \| grep -i usbasp` | Missing udev rule (see Install section). Did you log out/in after `usermod -aG plugdev $USER`? |
| Windows | Device Manager → **libusb-win32 devices** → "USBasp" | Re-run Zadig, replace driver with libusb-win32 for USBasp specifically. |

**Programmer detected, chip not** — `target doesn't answer`:

1. Flip the 6-pin ISP connector — pin 1 mismatch is the most common cause. Backwards orientation won't damage anything, just won't work.
2. Confirm the board is powered (its 18 V supply, plus check 5 V regulator output).
3. *Only after* the above two: try `-B 8` to slow SCK. Some cheap USBasp clones with stale firmware need this. If `-B 8` doesn't help, try `-B 32`. If still failing, the clone itself is the problem — borrow a different programmer.

**Signature reads as `0x1e0000` or all zeros:** the programmer or cable is faulty, not the target. This is **not** a slow-SCK problem and `-B 8` won't fix it. Cross-test by trying to read an unrelated chip (e.g., an Arduino's ATmega328P at `-p m328p`). Same partial signature on a different chip = programmer/cable issue. Get a different programmer.

**Don't reach for `-F` (force).** That flag tells avrdude to ignore signature mismatches and write anyway. It only makes sense if you've already confirmed the chip is fine and the signature read is broken for unrelated reasons. If you're tempted to use `-F` to "just make it work," you're about to flash a chip that doesn't match the firmware build target.

### Flash with Arduino-as-ISP

If you don't have a USBasp but do have an Arduino UNO/Nano lying around, it works as a programmer:

1. Open Arduino IDE → **File → Examples → 11. ArduinoISP → ArduinoISP** → upload to the Arduino.
2. Wire the Arduino to the MK-312BT ISP header: pin 10 → RESET, 11 → MOSI, 12 → MISO, 13 → SCK, plus 5 V and GND. Add a 10 µF cap between the Arduino's RESET and GND to stop the IDE auto-resetting it during flash operations.
3. Find the Arduino's serial port:
   - **macOS**: `ls /dev/cu.usb*` → e.g., `/dev/cu.usbmodem14101`
   - **Linux**: `ls /dev/ttyACM*` → e.g., `/dev/ttyACM0`
   - **Windows**: Device Manager → Ports → look for "Arduino", e.g., `COM7` (use `\\.\COM7` in avrdude commands)

Test, set fuses, flash — same three steps, just `-c avrisp -P <port> -b 19200` instead of `-c usbasp`:

```sh
# macOS / Linux
avrdude -c avrisp -P /dev/cu.usbmodem14101 -b 19200 -p m16 -t
avrdude -v -c avrisp -P /dev/cu.usbmodem14101 -b 19200 -p m16 -U lfuse:w:0xFF:m -U hfuse:w:0xDC:m
avrdude -v -c avrisp -P /dev/cu.usbmodem14101 -b 19200 -p m16 -U flash:w:f005-HelloFriend.bin
```

```cmd
:: Windows (substitute your COM port number)
avrdude -c avrisp -P \\.\COM7 -b 19200 -p m16 -t
avrdude -v -c avrisp -P \\.\COM7 -b 19200 -p m16 -U lfuse:w:0xFF:m -U hfuse:w:0xDC:m
avrdude -v -c avrisp -P \\.\COM7 -b 19200 -p m16 -U "flash:w:f005-HelloFriend.bin"
```

### Fuse byte reference

| Fuse | Value | Means |
|---|---|---|
| Low fuse  | `0xFF` | External crystal (8 MHz+), max startup time |
| High fuse | `0xDC` | JTAG disabled, EEPROM preserved across flash, BOD enabled at 4.3 V |

**Don't fat-finger these.** Wrong fuse bytes can lock out ISP — recovery requires an HV (parallel) programmer. Copy/paste the commands above; don't retype.

### Build from source (advanced)

The `.bin` files in this repo are pre-built. To rebuild from scratch:

1. **Get the toolchain.** macOS: `brew install avr-gcc`. Linux: `sudo apt install gcc-avr binutils-avr avr-libc`. Windows: install [WinAVR](https://sourceforge.net/projects/winavr/) (it bundles avr-gcc).
2. **Get the source.** The project is **buttshock-et312-frankenbutt-f005**. Clone it from GitHub if it's still there, or grab a copy from the e-stim community Discord (`#312-chat`).
3. **Get the original ET-312 firmware blob.** ErosTek ships their firmware encrypted/scrambled. The `buttshock-et312-firmware` toolchain has a script that downloads and unscrambles it:
   ```sh
   git clone https://github.com/buttshock/buttshock-et312-firmware
   cd buttshock-et312-firmware
   scripts/fw-utils.py --downloadfw
   ```
   Per [cLx's notes](http://clx.freeshell.org/mk312bt.html), this download path may not work anymore — if it fails, the unscrambled blob is also floating around the same Discord / Telegram channels.
4. **Build the patched version:**
   ```sh
   cd ../buttshock-et312-frankenbutt/m005
   make
   ```
   This produces `m005.bin` ready for `avrdude -U flash:w:m005.bin`.
5. The MK-312BT-specific patches (left/right arrows for the LCD character map) are already applied in the bundled `f005-*.bin` files in this repo. If you build from clean upstream you'll need to re-apply those, or you'll see garbled arrows on screen.

### Internal oscillator? Don't.

There's a workaround involving the chip's calibration byte and `OSCCAL` if you skip the external 8 MHz crystal. It's fragile per-chip, and gets you timing/interrupt/serial failures whenever it's slightly off. Forget this crap. Use the external crystal, period.

## MK312-BT Original Fab Notes

(These are the old fab notes from the repo, mostly kept here for
history sake. Ordering instructions above cover most of this.)

### Main Boards

1. V Score the Main Boards panel as indicated.
2. Main Boards has 2 board designs panelized on 1 panel.
3. Thickness is standard 1.6mm (0.063inches)
4. Board is 2 layers
5. HASL Finish - Pb Free Preferred if possible, otherwise Pb HASL is OK
6. 1oz copper
7. FR4 material
8. Main Boards : Green solder mask, White Silkscreen (silkscreen BOTH top and bottom sides)
9. ITAR : NO
10. IPC-A-610 - Class2 (If possible - otherwise ignore)
11. Main Board Dimensions : (193.04mm x 104.14mm) or (7.600 inches x 4.100 inches) 

### Front Panel Boards

1. Place all Fab Markings (Serial Numbers/Date Codes) on the BOTTOM side of the front panel board. 
2. Thickness is standard 1.6mm (0.063inches)
3. Board is 2 layers
4. HASL Finish - Pb Free Preferred if possible, otherwise Pb HASL is OK
5. 1oz copper
6. FR4 material
7. Front Panel Boards : Black Solder Mask, While Silkscreen
8. ITAR : NO
9. IPC-A-610 - Class2 (If possible - otherwise ignore)
10. Front Panel Board Dimensions :  (196.85mm x 58.72mm) or (7.750inches x 2.312inches) 

## Bluetooth (HC-05) configuration

The HC-05 module ships with default settings (name "HC-05", PIN 1234, baud 9600) — it needs to be reconfigured before it'll talk to the MK-312BT. Skip this entire section if you're using the WiFi adapter instead — see [`4-wireless/wifi/`](4-wireless/wifi/).

> **macOS users:** HC-05 / Bluetooth Classic SPP is unreliable on macOS Monterey+ (Apple deprecated SPP support). Pairing works but data drops out. Use the [WiFi adapter](4-wireless/wifi/) instead.

### Two ways to configure it

| Method | Effort | When to pick |
|---|---|---|
| **Manual via USB-TTL serial adapter** ⭐ | Plug HC-05 into laptop, send AT commands. ~5 minutes. | Recommended. You already need a USB-TTL adapter for the LINK port anyway (BOM lists `amazon.com/dp/B07D6LLX19`). |
| **Auto-config via one-shot AVR firmware** | Flash a special firmware that AT-configures the HC-05 in-place from the AVR side, then flash the real firmware back. | Only useful if you're building several boards or have no USB-TTL adapter. Firmware: [`4-wireless/bluetooth/MK-312BT V1.2 HC-05 Initialization ATMEGA16.bin`](4-wireless/bluetooth/) (BASIC source `.bas` also included). |

### Manual config (recommended path)

**👉 See [`4-wireless/bluetooth/hc05-setup.md`](4-wireless/bluetooth/hc05-setup.md) for the complete walkthrough** — it covers the three quirks that quietly break first-time setups (no local echo, CR+LF requirement, fixed 38400 baud in command mode), per-platform terminal setup (picocom on macOS/Linux, Arduino IDE Serial Monitor or Termite on Windows), the IPSCAN power-vs-responsiveness tradeoff with a comparison table, and the macOS "Disconnected" cosmetic quirk.

Quick summary of what you'll do:

1. **Wire** USB-TTL adapter to HC-05: VCC↔VCC, GND↔GND, **TX↔RXD**, **RX↔TXD** (the cross is the most common mistake — each board labels pins from its own perspective). If your HC-05 breakout has no button, also wire 3.3 V to the HC-05's `EN` pin.
2. **Enter AT mode**: hold the button on the HC-05 breakout (or pull `EN` high) while connecting power. LED should blink slowly (~once every 2 s). Fast blink = data mode, retry.
3. **Find the serial device**: `ls /dev/cu.usbserial-*` (macOS), `ls /dev/ttyUSB*` (Linux), Device Manager (Windows).
4. **Open a terminal at 38400 baud with CR+LF and local echo enabled** (AT mode is hardcoded to 38400 regardless of what you set with `AT+UART`):
   ```sh
   picocom -b 38400 --omap crcrlf --echo /dev/cu.usbserial-XXXXXXXX
   ```
5. **Test**: type `AT` + Enter → expect `OK`. If nothing comes back, see the troubleshooting in `hc05-setup.md`.
6. **Configure** (each command should reply `OK`):
   ```
   AT+NAME=MK-312BT
   AT+UART=19200,0,0
   AT+PSWD=1234
   AT+POLAR=1,1
   AT+IPSCAN=1024,1,1024,512
   ```
7. **Verify** by reading values back: `AT+NAME?`, `AT+UART?`, `AT+PSWD?`, `AT+IPSCAN?`.
8. **Check / solder pin 32** on the HC-05 inner module to the breakout board (the STATE pin — drives the front-panel "Radio" LED). The recommended **DSD Tech HC-05 (Amazon B01G9KSAF6)** ships with this connection already made — verify with a multimeter (continuity from inner-module pin 32 to the breakout's STATE/EN pad) and skip the solder step if it's already there. On generic ZS-040 clones you'll need to bridge it yourself with a fine wire. See [`HC05PINOUT.png`](4-wireless/bluetooth/HC05PINOUT.png).
9. **Plug into the MK-312BT** at the J9 "Radio Header" socket. Pair from your host with PIN `1234`.

#### A note on IPSCAN

The community-default `AT+IPSCAN=1024,1,1024,1` makes the HC-05 nearly invisible (~5 mA idle) but slow to reconnect (~30 s after every power-on). The more practical `1024,1,1024,512` gives ~15–20 mA idle and <2 s reconnect by keeping page-scan at full duty cycle while killing the inquiry-scan that dominates idle current. Use `1024,512,1024,512` (HC-05 default) only if you've replaced the 7805 with a switching regulator (see cLx's page for the mEZD71201A-G drop-in mod, currently silicon for ~$15).

`hc05-setup.md` has the full table comparing all three settings against the stock 7805 thermal limits.

### Auto-config alternative

If you'd rather not buy a USB-TTL adapter, the repo includes a one-shot AVR firmware that configures the HC-05 in-place:

1. Verify pin 32 on the HC-05 inner module is connected to the breakout board (auto-config relies on the STATE line to detect the HC-05). DSD Tech B01G9KSAF6 modules have this pre-soldered; generic ZS-040 clones need a wire bridge — see [`HC05PINOUT.png`](4-wireless/bluetooth/HC05PINOUT.png).
2. Flash [`4-wireless/bluetooth/MK-312BT V1.2 HC-05 Initialization ATMEGA16.bin`](4-wireless/bluetooth/) onto the ATmega16 using the same avrdude commands from the [Firmware section](#firmware-flashing-the-avr) above.
3. Plug the HC-05 into the board's J9 socket — but **don't power up yet**.
4. **Put the HC-05 in command mode BEFORE the AVR boots.** The HC-05 only checks its EN (KEY) pin at power-on, so timing matters:
   - **Press and hold** the button on the HC-05 breakout (pulls EN high)
   - **While still holding the button**, apply power to the MK-312BT
   - The HC-05 enters command mode instantly at power-on. Its LED slow-blinks (~0.5 Hz once per ~2 s) to confirm.
   - You can **release the button after ~2 seconds** — command mode persists until power is removed. The auto-config AVR firmware now sends its AT commands while the HC-05 is listening.

   Holding the button *after* power-up doesn't put the HC-05 in command mode — the EN check only happens at boot. Get the timing right or the auto-config silently fails.
5. Watch the LCD: it'll display progress and finally "HC-05 OK" (or similar).
6. Power off, flash the real application firmware (`f005-HelloFriend.bin` or another `f005-*.bin`) back onto the AVR.
7. If it stops on "Communicating with HC-05," your fuses are wrong — make sure the external 8 MHz crystal fuses are set per the [Firmware section](#firmware-flashing-the-avr). Don't try to make this work with the internal RC oscillator.

### Pairing

After config, pair from your host with PIN `1234`:

| Platform | How |
|---|-----|
| **macOS** | System Settings → Bluetooth → "MK-312BT" → 1234. After ~30 s the panel will show "Disconnected" — this is cosmetic; the bond is permanent. Verify with `ls /dev/cu.MK-312BT*`. **SPP support is poor on Monterey+; consider the WiFi adapter.** |
| **Linux** | `bluetoothctl` → `pair XX:XX:XX:XX:XX:XX` → 1234. To get a serial port: `sudo rfcomm bind 0 XX:XX:XX:XX:XX:XX` → use `/dev/rfcomm0`. |
| **Windows** | Settings → Devices → Bluetooth → "MK-312BT" → 1234. A virtual COM port appears in Device Manager. |
| **Android** | Settings → Bluetooth → "MK-312BT" → 1234. App connects to the bonded device. |
| **iOS** | Doesn't speak Bluetooth Classic SPP at all. Use the WiFi adapter. |

Then point your control client (e.g., [`mk312-gui`](https://github.com/clxjaguar/mk312-gui)) at the assigned serial port at 19200 baud.

## 3D Printable Case

STL files for a 3D printable case are in [`3-build-and-flash/case/`](3-build-and-flash/case/). For hardware, this case requires:

- 4 M2.5x20 screws
- up to 3 M2.5x5 screws
- some dampening for the battery (double sided foam tape may work)

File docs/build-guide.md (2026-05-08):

# MK-312BT build guide

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

## Provenance

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

The metafetish.club forum is now offline — surviving posts are archived in [`troubleshooting/`](troubleshooting/).

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

## Parts ordering information

See the Documentation link above for BOMs.

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

## Board ordering instructions

Preferred board house is https://jlcpcb.com

You'll need 2 gerber zip files (click links to download):

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

Use four closely-matched IRL520s for one board, and likewise pair up the two IRF9Z24s.

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

Background reading: [`troubleshooting/MK-312BT Failure 20 - Estim - Metafetish.pdf`](troubleshooting/MK-312BT%20Failure%2020%20-%20Estim%20-%20Metafetish.pdf).

## Board Assembly Instructions - IMPORTANT

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

## Firmware: flashing the AVR

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

### Pick a firmware

| File | What it is |
|---|---|
| `cr-custom-boot-messages/f005-HelloFriend.bin` | **Recommended default — application firmware.** Patched frankenbutt-f005 with a "Hello Friend" boot screen. Flash this and the box runs. |
| `cr-custom-boot-messages/f005-ElectrodesReady.bin` | Alternative application: same f005 build, "Electrodes Ready" boot screen. |
| `other-fw/f005.bin` | Alternative application: unpatched frankenbutt-f005, no custom boot message. |
| `other-fw/t002_bootloader.bin` | **Optional ET-312 bootloader.** Flash this *first* if you want to update the firmware over the LINK port later without dragging the USBasp out again. Then flash one of the f005 application firmwares on top. By itself the bootloader doesn't run the box — you still need the application. |
| `other-fw/unpatched_312-16.upg` | **Source input for the patcher** — not flashable directly. Encrypted ET-312 v1.6 firmware blob from ErosTek. Feed into buttshock fw-utils when rebuilding from source. See [Build from source](#build-from-source-advanced) below. |

All bundled `.bin` files include the LCD character-map fix (left/right arrows instead of up/down). If you just want a working box, flash `f005-HelloFriend.bin` and skip ahead. If you want field-updatable firmware, flash `t002_bootloader.bin` first and then `f005-HelloFriend.bin`.

### Pick a programmer

Ranked from "just buy this" to "if you have one already":

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

### Install avrdude

#### macOS (Homebrew)

```sh
brew install avrdude
```

That's it. USBasp works out of the box, no driver setup.

#### Linux (Debian / Ubuntu / Mint)

```sh
sudo apt install avrdude
```

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

```sh
sudo tee /etc/udev/rules.d/99-usbasp.rules <<'EOF'
SUBSYSTEM=="usb", ATTR{idVendor}=="16c0", ATTR{idProduct}=="05dc", GROUP="plugdev", MODE="0666"
EOF
sudo udevadm control --reload-rules
sudo usermod -aG plugdev $USER   # log out and back in for this to take effect
```

#### Windows

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

### The three things you actually need to do

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

#### Step 1 — Identify your programmer's avrdude name

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

Don't know what you've got? List every supported programmer:

```sh
avrdude -c help 2>&1 | head -40
```

For this guide we'll use `-c usbasp` since that's what the BOM lists.

#### Step 2 — Set the fuses

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

```sh
avrdude -c usbasp -p m16 -U lfuse:w:0xFF:m -U hfuse:w:0xDC:m
```

What each flag means:

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

#### Step 3 — Flash the firmware

```sh
avrdude -c usbasp -p m16 -U flash:w:f005-HelloFriend.bin
```

Same flags as before, with one new `-U` operation:

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

Power-cycle the box and you should see the boot screen.

#### Useful extra flags

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

#### Test the connection before flashing

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

```sh
avrdude -c usbasp -p m16 -v
```

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

### First-time walkthrough (USBasp on macOS — same idea on Linux/Windows)

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

**3. Power the board** with its normal 18 V supply.

**4. Verify the chip:**

```sh
avrdude -c usbasp -p m16 -v
```

Expect `Device signature = 0x1e9403` (ATmega16) or `0x1e9489` (ATmega16A). That confirms the programmer reached the chip.

**5. Set the fuses** (once per chip):

```sh
avrdude -c usbasp -p m16 -U lfuse:w:0xFF:m -U hfuse:w:0xDC:m
```

Look for `lfuse verified` and `hfuse verified`.

**6. Flash the firmware:**

```sh
cd /path/to/mk312-bt/3-build-and-flash/firmware/cr-custom-boot-messages
avrdude -c usbasp -p m16 -U flash:w:f005-HelloFriend.bin
```

Progress bars, then `verified`. About 30 seconds on a USBasp.

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

### Troubleshooting flashing

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

```mermaid
flowchart TD
    accTitle: AVR flashing troubleshooting decision tree
    accDescr: Diagnostic flow for avrdude failures. First check whether the OS sees the programmer, then check whether the programmer can reach the chip, then check whether the signature is valid.

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

    class fix_usb,fix_cable,bad_prog bad
    class sees_prog,reaches_chip,valid_sig question
    class start,proceed good
```

**Programmer not detected** — `could not find USB device with vid=0x16c0 pid=0x5dc`:

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

**Programmer detected, chip not** — `target doesn't answer`:

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

### Flash with Arduino-as-ISP

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

```sh
# macOS / Linux
avrdude -c avrisp -P /dev/cu.usbmodem14101 -b 19200 -p m16 -t
avrdude -v -c avrisp -P /dev/cu.usbmodem14101 -b 19200 -p m16 -U lfuse:w:0xFF:m -U hfuse:w:0xDC:m
avrdude -v -c avrisp -P /dev/cu.usbmodem14101 -b 19200 -p m16 -U flash:w:f005-HelloFriend.bin
```

```cmd
:: Windows (substitute your COM port number)
avrdude -c avrisp -P \\.\COM7 -b 19200 -p m16 -t
avrdude -v -c avrisp -P \\.\COM7 -b 19200 -p m16 -U lfuse:w:0xFF:m -U hfuse:w:0xDC:m
avrdude -v -c avrisp -P \\.\COM7 -b 19200 -p m16 -U "flash:w:f005-HelloFriend.bin"
```

### Fuse byte reference

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

### Build from source (advanced)

The `.bin` files in this repo are pre-built. To rebuild from scratch:

1. **Get the toolchain.** macOS: `brew install avr-gcc`. Linux: `sudo apt install gcc-avr binutils-avr avr-libc`. Windows: install [WinAVR](https://sourceforge.net/projects/winavr/) (it bundles avr-gcc).
2. **Get the source.** The project is **buttshock-et312-frankenbutt-f005**. Clone it from GitHub if it's still there, or grab a copy from the e-stim community Discord (`#312-chat`).
3. **Get the original ET-312 firmware blob.** ErosTek ships their firmware encrypted/scrambled. The `buttshock-et312-firmware` toolchain has a script that downloads and unscrambles it:
   ```sh
   git clone https://github.com/buttshock/buttshock-et312-firmware
   cd buttshock-et312-firmware
   scripts/fw-utils.py --downloadfw
   ```
   Per [cLx's notes](http://clx.freeshell.org/mk312bt.html), this download path may not work anymore — if it fails, the unscrambled blob is also floating around the same Discord / Telegram channels.
4. **Build the patched version:**
   ```sh
   cd ../buttshock-et312-frankenbutt/m005
   make
   ```
   This produces `m005.bin` ready for `avrdude -U flash:w:m005.bin`.
5. The MK-312BT-specific patches (left/right arrows for the LCD character map) are already applied in the bundled `f005-*.bin` files in this repo. If you build from clean upstream you'll need to re-apply those, or you'll see garbled arrows on screen.

### Internal oscillator? Don't.

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

## MK312-BT Original Fab Notes

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

### Main Boards

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

### Front Panel Boards

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

## Bluetooth (HC-05) configuration

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

### Two ways to configure it

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

### Manual config (recommended path)

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

Quick summary of what you'll do:

1. **Wire** USB-TTL adapter to HC-05: VCC↔VCC, GND↔GND, **TX↔RXD**, **RX↔TXD** (the cross is the most common mistake — each board labels pins from its own perspective). If your HC-05 breakout has no button, also wire 3.3 V to the HC-05's `EN` pin.
2. **Enter AT mode**: hold the button on the HC-05 breakout (or pull `EN` high) while connecting power. LED should blink slowly (~once every 2 s). Fast blink = data mode, retry.
3. **Find the serial device**: `ls /dev/cu.usbserial-*` (macOS), `ls /dev/ttyUSB*` (Linux), Device Manager (Windows).
4. **Open a terminal at 38400 baud with CR+LF and local echo enabled** (AT mode is hardcoded to 38400 regardless of what you set with `AT+UART`):
   ```sh
   picocom -b 38400 --omap crcrlf --echo /dev/cu.usbserial-XXXXXXXX
   ```
5. **Test**: type `AT` + Enter → expect `OK`. If nothing comes back, see the troubleshooting in `hc05-setup.md`.
6. **Configure** (each command should reply `OK`):
   ```
   AT+NAME=MK-312BT
   AT+UART=19200,0,0
   AT+PSWD=1234
   AT+POLAR=1,1
   AT+IPSCAN=1024,1,1024,512
   ```
7. **Verify** by reading values back: `AT+NAME?`, `AT+UART?`, `AT+PSWD?`, `AT+IPSCAN?`.
8. **Check / solder pin 32** on the HC-05 inner module to the breakout board (the STATE pin — drives the front-panel "Radio" LED). The recommended **DSD Tech HC-05 (Amazon B01G9KSAF6)** ships with this connection already made — verify with a multimeter (continuity from inner-module pin 32 to the breakout's STATE/EN pad) and skip the solder step if it's already there. On generic ZS-040 clones you'll need to bridge it yourself with a fine wire. See [`HC05PINOUT.png`](../4-wireless/bluetooth/HC05PINOUT.png).
9. **Plug into the MK-312BT** at the J9 "Radio Header" socket. Pair from your host with PIN `1234`.

#### A note on IPSCAN

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

### Auto-config alternative

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

   Holding the button *after* power-up doesn't put the HC-05 in command mode — the EN check only happens at boot. Get the timing right or the auto-config silently fails.
5. Watch the LCD: it'll display progress and finally "HC-05 OK" (or similar).
6. Power off, flash the real firmware (`t002_bootloader.bin`, or one of the alternatives) back onto the AVR.
7. If it stops on "Communicating with HC-05," your fuses are wrong — make sure the external 8 MHz crystal fuses are set per the [Firmware section](#firmware-flashing-the-avr). Don't try to make this work with the internal RC oscillator.

### Pairing

After config, pair from your host with PIN `1234`:

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

## 3D Printable Case

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

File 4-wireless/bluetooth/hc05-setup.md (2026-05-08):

# Configuring an HC-05 Bluetooth Module for the mk312-bt

A cross-platform setup guide covering hardware, terminal configuration, the three quirks that quietly break most first-time setups, and the IPSCAN power/responsiveness tradeoff that matters for thermal and battery behavior.

---

## What you need

| Item | Notes |
|---|---|
| HC-05 module | ZS-040 breakout (with onboard button) is easiest |
| USB-to-TTL adapter | FTDI FT232RL or CP2102; must support 3.3V logic |
| 4 jumper wires | Female-to-female if the HC-05 has male headers |
| Terminal program | picocom (macOS/Linux), Arduino Serial Monitor or Termite (Windows) |

Any 3.3V-capable USB-to-TTL adapter will work for the HC-05 step. The DSD TECH SH-U09C5 (with a 1.8/2.5/3.3/5V slide switch) is preferred if you're building a full mk312-bt because the same adapter can later be used on the mk312's LINK port, which requires 1.8–3.6V signal levels.

---

## Wiring

| USB-TTL adapter | HC-05 |
|---|---|
| VCC (3.3V or 5V — both work; ZS-040 has its own regulator) | VCC |
| GND | GND |
| TX | RXD |
| RX | TXD |

The TX/RX cross is the single most common wiring error. Each board's pin labels are written from its own perspective: "TX" on one side connects to "RX" on the other.

If your HC-05 breakout has no button, also wire the adapter's 3.3V output to the HC-05's EN (or KEY) pin. If it has a button, leave EN unconnected.

---

## Entering AT mode

The HC-05 has two operating modes:

- **Data mode** — normal Bluetooth operation; runs at the configured baud (default 9600). AT commands ignored.
- **AT/command mode** — runs at a fixed 38400 baud. Accepts configuration commands.

To enter AT mode:

1. Disconnect VCC from the HC-05.
2. Press and hold the button on the breakout.
3. Reconnect VCC.
4. Release the button after ~2 seconds.

The status LED should now blink slowly, roughly once every 2 seconds. Fast blinking (~2 per second) means it booted into data mode and AT commands will not work — power-cycle and try again.

---

## Why first-time setups fail

The HC-05 has three undocumented behaviors that quietly break naive terminal sessions:

1. **No local echo.** Characters you type are not echoed. The screen stays blank until the module replies, so it feels like the keyboard is dead.
2. **Requires CR+LF line endings.** Every command must terminate with `\r\n`. Most terminals send only `\r` on Enter, and the module silently waits for a `\n` that never arrives.
3. **AT mode is hard-coded to 38400 baud.** Whatever baud you set with `AT+UART` applies only to data mode. Command mode is always 38400.

Nearly every "my HC-05 doesn't respond" thread online is one of these three.

---

## Connecting the terminal

### macOS

Find the device:

```
ls /dev/cu.usbserial-*
```

Connect:

```
picocom -b 38400 --omap crcrlf --echo /dev/cu.usbserial-XXXXXXXX
```

Install picocom via Homebrew if needed: `brew install picocom`.

Exit with `Ctrl-A` then `Ctrl-X`.

### Linux

Find the device:

```
ls /dev/ttyUSB*
```

Connect:

```
picocom -b 38400 --omap crcrlf --echo /dev/ttyUSB0
```

Install picocom: `sudo apt install picocom` (Debian/Ubuntu) or equivalent.

If you get a permission error, add yourself to the dialout group: `sudo usermod -aG dialout $USER`, then log out and back in.

### Windows

The COM port appears in Device Manager → Ports (COM & LPT) as "USB Serial Port (COMx)".

The simplest option is the **Arduino IDE Serial Monitor**:

1. Tools → Port → select COMx
2. Open Serial Monitor (magnifying-glass icon)
3. Baud rate dropdown (bottom right): **38400**
4. Line ending dropdown: **Both NL & CR**

Type commands in the input box and press Enter.

**Termite** (free, from CompuPhase) is also a clean option. Configure: 38400 baud, 8N1, "Append CR-LF" enabled, "Local echo" enabled.

PuTTY works but is fiddlier — it doesn't natively send CR+LF on Enter, requiring manual CTRL-J after each Enter, or workaround scripts. Avoid PuTTY for this task unless it's already installed and you don't want to add another tool.

---

## Verifying communication

Type:

```
AT
```

Press Enter. Expected reply: `OK`.

| Reply | Meaning |
|---|---|
| `OK` | Working correctly |
| `ERROR:(0)` | Command not recognized — almost always missing `\n` line ending |
| (nothing) | Wiring (TX/RX swap), wrong baud, or not in AT mode |

---

## Configuration for the mk312-bt

Once `AT` returns `OK`, send these in order. Each should reply `OK`.

```
AT+NAME=MK-312BT
AT+UART=19200,0,0
AT+PSWD=1234
AT+POLAR=1,1
```

> ⚠️ **Use `=` (equals), not `-` (hyphen) after the AT command.** Easy mistake when copy-pasting or typing fast. `AT+NAME=MK-312BT` is correct; `AT+NAME-MK-312BT` returns `ERROR:(0)` because the HC-05 parser thinks you're calling a command literally named `AT+NAME-MK-312BT`. The hyphen and equals keys are adjacent on US keyboards.

> ⚠️ **Don't put hyphens *inside* the name itself either** — many HC-05 clone firmwares accept only `[A-Za-z0-9]` for `AT+NAME=`. `AT+NAME=MK-312BT` returns `ERROR:(0)` on those firmwares even with the equals sign correct. Use `MK312BT` (no hyphen) instead — the Bluetooth advertising name is whatever you put here, it doesn't need to match the project's hyphenated convention. Same can be true if **macOS smart-dashes** silently converted your `-` into `–` (en-dash) somewhere in the paste path; turn it off in System Settings → Keyboard → Text Input → Edit… → uncheck "Use smart dashes" if you want to keep using a hyphen.

> ⚠️ **`AT+NAME?` returns `ERROR:(0)` on some HC-05 firmware revisions** even when the name is set correctly. JY-MCU clones and certain ZS-040 batches let you *set* the name with `AT+NAME=...` but won't let you *read* it back via the query form. Other queries (`AT+UART?`, `AT+PSWD?`, `AT+IPSCAN?`) still work. To verify the name actually took, exit AT mode and look for "MK-312BT" in your host's Bluetooth scan list — that's the only ground truth.

| Command | Purpose |
|---|---|
| `AT+NAME=MK-312BT` | Bluetooth advertising name |
| `AT+UART=19200,0,0` | Data-mode baud / 1 stop bit / no parity — matches the mk312's ATmega16 |
| `AT+PSWD=1234` | Pairing PIN |
| `AT+POLAR=1,1` | LED polarity for the radio LED on the mk312 front panel |

The IPSCAN command from the original mk312-bt repo is intentionally omitted here — it deserves its own section because the right value depends on your build.

---

## The IPSCAN tradeoff

`AT+IPSCAN` controls how often the HC-05's radio listens for inquiries (new devices wanting to discover it) and pages (already-paired devices wanting to reconnect). Format:

```
AT+IPSCAN=<inq_interval>,<inq_window>,<page_interval>,<page_window>
```

All four values are in 0.625ms units. The window must be ≤ the interval. The window-to-interval ratio is the radio's listening duty cycle.

| Pair | Controls |
|---|---|
| `inq_interval, inq_window` | Discovery by new (unpaired) devices |
| `page_interval, page_window` | Reconnection by already-paired devices |

### The math

Each IPSCAN unit is **0.625 ms** (one Bluetooth Classic time slot). So:

- `1024` = 640 ms scan interval
- `512` = 320 ms scan window (50% duty cycle of a 640 ms interval)
- `1` = 0.625 ms scan window (~0.1% duty cycle, basically off)

`page_window` matters most for reconnect speed: the wider the window, the more likely the host's reconnect attempt overlaps with the HC-05 actually listening. Below ~10 ms window, most hosts time out before they hit a listen slot, and reconnect either takes 30+ seconds or fails outright.

### Three sensible settings, ranked by host compatibility

| Setting | Idle draw | New-device discovery | Paired reconnect | Windows | macOS Sequoia/Sonoma | Best for |
|---|---|---|---|---|---|---|
| `1024,512,1024,512` (HC-05 default) | ~43 mA | <5 s | <2 s | ✅ Snappy | ✅ Best chance — but see SPP caveat below | Switching regulator installed, or always wall-powered |
| **`1024,1,1024,512` (hybrid — recommended)** | ~15–20 mA | 30 s – minutes | <2 s | ✅ Snappy | ✅ Snappy *when SPP works at all* | Stock 7805, fast reconnect priority. **Default pick for both Windows and macOS.** |
| `1024,1,1024,1` (mk312 repo default) | ~5–8 mA | 30 s – minutes | 30 s+ | ⚠️ Works but feels broken | ❌ Often fails — macOS times out before the 0.625 ms page window aligns with macOS's page request | Stock 7805, battery-life priority. Avoid if macOS is involved. |

### Why the mk312 repo picks the most aggressive setting

The mk312-bt project ships with `1024,1,1024,1` because the stock 7805 linear regulator must dissipate the HC-05's 43mA idle draw as heat at 12V input — enough to make the regulator noticeably warm. Reducing both duty cycles to ~0.1% drops idle current to roughly 5–8mA, eliminating the thermal load and substantially extending battery life.

The cost is responsiveness. Cold discovery may take a minute or more. More importantly, even already-paired devices will take 30+ seconds to reconnect after every power-on, because the page-scan window is narrower than most hosts' default page-scan timeouts.

### The hybrid is the practical sweet spot

`1024,1,1024,512` cuts the inquiry-scan to near zero — where most of the idle current goes, since the radio is broadcasting "I exist" continuously to nobody — while keeping page-scan at the default duty cycle so paired devices reconnect promptly. Discovery of new devices is slow, but that only matters during initial pairing, and you can temporarily revert to the default just for that one event.

### If you've installed a switching regulator

The cLx article (clx.freeshell.org/mk312bt.html) recommends replacing the 7805 with a drop-in 5V switching regulator such as the Texas Instruments mEZD71201A-G. With that mod, the thermal pressure is gone and battery life is markedly better even at full HC-05 idle draw. Use the default `1024,512,1024,512` and get fast everything with no tradeoff.

### Applying your choice

Re-enter AT mode and send the command:

```
AT+IPSCAN=1024,1,1024,512
```

(or whichever value you've chosen). Other settings are unaffected. IPSCAN can be changed independently any time.

---

## Verifying the configuration

Re-enter AT mode and read back the values:

```
AT+NAME?
AT+UART?
AT+PSWD?
AT+IPSCAN?
```

Confirm each response matches what you set. Common readback formats:

```
+NAME:MK-312BT
+UART:19200,0,0
+PSWD:"1234"
+IPSCAN:1024,1,1024,512
```

(Quote style on `PSWD` varies by firmware revision.)

---

## Pairing

Exit AT mode (close picocom or terminal) and power-cycle the HC-05 **without** holding the button. The LED should now blink fast — data mode, ready to advertise.

Pair from your host as you would any Bluetooth device, using PIN `1234`. The host will assign a serial port to the bonded device.

| Platform | Serial port path |
|---|---|
| macOS | `/dev/cu.MK-312BT` (or similar) |
| Linux | `/dev/rfcomm0` after `sudo rfcomm bind 0 <MAC>` |
| Windows | `COMx` — assigned automatically; visible in Device Manager |

### macOS quirk: "Disconnected" in the Bluetooth panel

On macOS, the System Settings Bluetooth panel will display "Disconnected" 15–30 seconds after pairing, even though pairing succeeded. This is documented Apple behavior across multiple HC-05/Classic-SPP forum threads — macOS only maintains an active RFCOMM channel when an application has the serial port open. The pairing/bonding is permanent.

To verify pairing actually worked:

```
ls /dev/cu.MK-312BT*
```

If the device exists, you're paired. Open it from any application and the panel will flip back to "Connected":

```
picocom -b 19200 /dev/cu.MK-312BT
```

Linux and Windows do not exhibit this cosmetic issue.

### macOS Bluetooth Classic SPP reality check

Even with everything configured perfectly, **Bluetooth Classic SPP support is genuinely flaky on macOS Sequoia/Sonoma at the OS level** — not anything you can fix with HC-05 settings. Symptoms include:

- Pairing succeeds, but data sessions drop unexpectedly mid-use
- Disconnects after ~30 seconds even when an app holds the port open
- "MK-312BT" appears in the Bluetooth scan, refuses to bond, and has to be retried
- Works once, fails the next session with no settings change

Confirmed across [Apple Support Communities](https://discussions.apple.com/thread/255488094), [Charith De Silva's HC-05 + Monterey writeup](https://charithdesilva.com/using-an-hc-05-bluetooth-module-for-arduino-with-macos-monterey-2fe0b3e4b63e), and the [Espruino HC-05-on-Mac discussion](https://github.com/orgs/espruino/discussions/4713).

**If macOS gives you grief no matter what IPSCAN value you try, the canonical advice is to use the WiFi adapter** at [`../wifi/`](../wifi/) instead. It exists in this repo specifically because BT Classic on modern macOS is unreliable in ways no HC-05 setting can fix. iOS doesn't speak BT Classic SPP at all and *requires* the WiFi adapter.

### macOS pairing tip: try PIN 0000 if 1234 fails

Several macOS sources note that **macOS attempts PIN `0000` by default** for Bluetooth Classic devices that don't display a PIN themselves. With our setup `AT+PSWD=1234`, macOS will prompt you to manually enter the PIN — usually fine, but if pairing silently fails or the PIN dialog never appears, **reconfigure the HC-05 to use PIN 0000** instead:

```
AT+PSWD=0000
```

Then re-pair from macOS. The mk312-bt convention is `1234`, but `0000` is functionally equivalent for the box and removes one source of macOS pairing weirdness.

---

## Reconfiguring later

Settings persist in the HC-05's flash and survive power cycles. To change them later — including after the module is installed in the mk312 — there's no need to desolder anything: pull the HC-05 daughterboard, jumper to the USB-to-TTL adapter exactly as in the wiring section, hold the button during power-up, and you're back at the AT prompt at 38400 baud.

The mk312 also accepts an RS232 cable plugged into its LINK port, which physically disconnects the Bluetooth module — useful for debugging if the Bluetooth side ever misbehaves in the field.

---

## Quick reference

**Connect (macOS/Linux):**
```
picocom -b 38400 --omap crcrlf --echo <device>
```

**Configure for mk312-bt:**
```
AT+NAME=MK-312BT
AT+UART=19200,0,0
AT+PSWD=1234
AT+POLAR=1,1
AT+IPSCAN=1024,1,1024,512
```

**Verify:**
```
AT+NAME?
AT+UART?
AT+PSWD?
AT+IPSCAN?
```

**Exit picocom:** `Ctrl-A` then `Ctrl-X`.

---

## Sources

Background reading and confirmed-working references for the macOS / Windows compatibility notes:

- [Apple Support Communities — HC-05 Bluetooth module connection to iMac issues](https://discussions.apple.com/thread/255488094)
- [Charith De Silva — Using an HC-05 with macOS Monterey](https://charithdesilva.com/using-an-hc-05-bluetooth-module-for-arduino-with-macos-monterey-2fe0b3e4b63e) — first-hand walkthrough of pairing fails and workarounds on Apple Silicon
- [Espruino discussion — HC-05 Bluetooth on Mac](https://github.com/orgs/espruino/discussions/4713) — community thread on macOS SPP flakiness
- [Wayne's Tinkering Page — HC-05 AT Commands](https://sites.google.com/site/wayneholder/hc-05-bluetooth-command-list) — most thorough AT command reference for ZS-040 boards
- [HC-05 AT Command Set (canonical PDF)](https://s3-sa-east-1.amazonaws.com/robocore-lojavirtual/709/HC-05_ATCommandSet.pdf) — original ITEAD reference
- [Instructables — How to Connect HC-05 to Windows 10/11 & Mac](https://www.instructables.com/How-to-Connect-HC-05-to-Windows-1011-Mac-Apple-Com/) — Windows pairing flow with screenshots
- [cLx — MK-312BT page](http://clx.freeshell.org/mk312bt.html) — switching-regulator (mEZD71201A-G) replacement for the 7805 if you want full HC-05 idle without thermal pressure

For the IPSCAN slot-time math (0.625 ms per unit, page-window-vs-host-timeout reasoning), the source is the Bluetooth Core Specification (Volume 2, Part B — page-scan / inquiry-scan). Not linked here because the spec is a 3000-page PDF; the practical takeaway is reflected in the table above.

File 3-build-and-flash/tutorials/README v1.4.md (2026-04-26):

# Jan 2021 update
The "original" branch of this repository matches the main metafetish/mk312-bt repo at the point it was deleted (which was on or 
about 27th Dec 2020), with zero changes. This represents the mk312-bt that many (myself included) have successfully built.

## v1.4
This master branch includes v1.4 files which were never in the original repo, but were kindly DM'd to me shortly after the original 
repo was deleted. These v1.4 files do not include updated eagle source files, etc., only output gerbers/schematics/notes. I'm 
somewhat hazy about the provenance of the v1.4 files, but I understand it has been successfully built by a few people already, and 
implements various improvements over v1.3 (see the v1.4 [notes](https://github.com/CrashOverride85/mk312-bt/blob/master/gerbers/MK-312BT%20V1.4%2005-19-2019%20Notes.txt) 
file for details and before ordering parts).

# MK-312BT V1.3

Documentation at : http://tinyurl.com/mk312bt-info

~~Forum - now archived/read-only, but with a lot of potentially useful information: https://metafetish.club ([Estim Specific Category Here](https://metafetish.club/c/estim), but may not include all estim messages)~~
Now offline. See a few posts in the [docs](docs/) folder that may help or be of interest.

There are many people familiar / knowledgable on the MK312-BT in the #boxes-pulse-based-diy and #312-chat channels of [Joanne's E-Stim Community](https://discord.gg/rY8C27S) discord server.

## Parts ordering information

See the Documentation link above for BOMs.

Prebuilt Mouser cart for electronic components of the v1.3R board:
https://www.mouser.com/ProjectManager/ProjectDetail.aspx?AccessID=a2725b2f11

You will still need screws/standoffs/cases etc, which can be sourced
elsewhere as listed in the spreadsheet.

## Board ordering instructions

Preferred board house is https://jlcpcb.com

You'll need 2 gerber zip files from the gerbers directory (click links below to download):

- [MK-312 V1.2 Front Panel](https://github.com/CrashOverride85/mk312-bt/blob/master/gerbers/ZIP%20FILES/MK-312BT%20Front%20Panel%20V1.2%20Gerber.zip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)
- [MK-312 V1.3 Main Board](https://github.com/CrashOverride85/mk312-bt/blob/master/gerbers/ZIP%20FILES/MK-312BT%20Main%20Boards%20V1.3%20Gerber.zip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)

**NOTE:** Order Front Panel and Main Board as seperate items (but they
can be in the same cart), due to difference in "Different Design"
setting. See below.

- 2 Layer PCB and Dimensions should be detected when you upload the
  zip with the gerbers
- Quantity: No requirement, choose whatever you like
- Thickness: 1.6
- PCB Color:
   - Main Boards: No requirement, choose whatever you like
   - Front Panel: Black is recommended, but not required. Choose whatever you like otherwise.
- Surface finish: HASL
- Copper weight: 1oz
- Gold fingers: No
- Material: Standard FR4
- Panel by jlcpcb: No
- Different Design 
   - Main Boards: 2
   - Front Panel: 1
- Remarks:
   - Main Boards: V Score the Main Boards panel as indicated.
   - Front Panel: Place all Fab Markings (Serial Numbers/Date Codes) on the BOTTOM side of the front panel board.
   
## Board Assembly Instructions - IMPORTANT

1. Trim Potentiometer knobs to correct length if desired
2. Use black permanent marker to black out front panel hole walls if
   desired
3. Cut the tabs off of the base of the pots so the board sits flush
   with the display facade if desired
4. To correctly fit LCD - solder header to LCD board first. Next
   insert LCD panel into front panel daughter board. Then put screws
   on front panel facade and finger tighten M2.5 screws first. Adjust
   positions as needed so everything lines up and sits well. Finally
   solder LCD header to front panel daughter board.
5. Make sure Pin 32 (LED2) on the HC-05 module is actually soldered
   and making connection to the ZS-040 break out board or "Radio" LED
   may not function on the front panel
6. Be very careful not to bridge pins when soldering the LM 2941
   (U14). Apply heat to 1 pad only and carefully apply solder. If a
   bridge occurs - remove the IC, clean the pads throughly with flux
   and solder wick and then retry. Pins 2 and 3 can be bridged because
   they are both ground. Ensure that no other pins are bridged. Check
   with multimeter continuity tester for bridges before power on!
7. Make sure to check the orientation of all electrolytic caps. (+)
   indicates the positive and a solid white "|" indicates the negative.
8. **MAKE SURE YOUR POWER PLUG IS CENTER POSITIVE OR THINGS WILL GO
   BADLY.** If you fuck up and plug in a reversed polarity supply -
   replace electrolytic caps C1 and C4.
9. Please remember to adjust the LCD contrast potentiometer - if
   incorrectly set the unit and backlight will power on but the
   interface will not be displayed.
10. Place transformers with P facing the output jacks (yes we are
    using the transformers "backwards" if you follow orientation given
    in the transformer datasheet )
11. Trim pins of 4066 IC (U3) Socket on the front panel board flush
    before soldering so buttons can clear. If the buttons still
    interfere, carefully disassemble the button and cut off the bit of
    the plastic housing that interferes with the 4066 IC socket pins.
12. Using side cutters cut off the screw boss/screw mount on the case
    that touches/interferes with the ribbon cable socket on the
    display board.
13. The LCD display has metal retention tabs that may short the
    soldered leads of C43. When installing the display board ensure
    that this does not happen (shorten the capacitor leads and bend
    the offending metal tab out of the way if necessary
14. If Error 20 is encountered on first boot:
   - Check that all FETs and Transformers are turned in the correct direction
   - Check that resistors R35 and R46 are the correct 200k values
   - [See this thread on the message board](https://metafetish.club/t/mk-312bt-failure-20/)

## MK312-BT Firmware

1. We are using an external 8mhz crystal instead of the internal RC
   oscillator that the original uses. We need to set the fuses to
   enable this. 
   - LOW FUSE: 0xFF 
   - HIGH FUSE: 0xDC
2. A patched version of buttshock-et312-frankenbutt-f005 is
   recommended.
3. The firmware needs to be changed to replace the up/down arrows on
   the UI with left right arrows (this is because the LCD we use has a
   different character set)
4. Obtain or modify a copy of the firmware and flash the result onto
   the AVR.
5. If you don't want to use an external crystal - we need to set the
   calibration byte for the internal oscillator. If programming a
   blank chip you first need to read the calibration bytes of that
   part (i.e. using avrdude -t “dump calibration” the fourth byte is
   the calibration byte for 8MHz or use atmel studio to read the
   oscillator calibration byte). Then program that byte into 0x3fff in
   your firmware. These bytes will differ on different chips even from
   the same batch. The firmware reads that byte to set OSCCAL on
   startup. If the byte is inaccurate various problems and failures
   will occur related to timing, interrupts, and serial communication.
   Just use an external crystal dammit.

## MK312-BT Original Fab Notes

(These are the old fab notes from the repo, mostly kept here for
history sake. Ordering instructions above cover most of this.)

### Main Boards

1. V Score the Main Boards panel as indicated.
2. Main Boards has 2 board designs panelized on 1 panel.
3. Thickness is standard 1.6mm (0.063inches)
4. Board is 2 layers
5. HASL Finish - Pb Free Preferred if possible, otherwise Pb HASL is OK
6. 1oz copper
7. FR4 material
8. Main Boards : Green solder mask, White Silkscreen (silkscreen BOTH top and bottom sides)
9. ITAR : NO
10. IPC-A-610 - Class2 (If possible - otherwise ignore)
11. Main Board Dimensions : (193.04mm x 104.14mm) or (7.600 inches x 4.100 inches) 

### Front Panel Boards

1. Place all Fab Markings (Serial Numbers/Date Codes) on the BOTTOM side of the front panel board. 
2. Thickness is standard 1.6mm (0.063inches)
3. Board is 2 layers
4. HASL Finish - Pb Free Preferred if possible, otherwise Pb HASL is OK
5. 1oz copper
6. FR4 material
7. Front Panel Boards : Black Solder Mask, While Silkscreen
8. ITAR : NO
9. IPC-A-610 - Class2 (If possible - otherwise ignore)
10. Front Panel Board Dimensions :  (196.85mm x 58.72mm) or (7.750inches x 2.312inches) 

## Bluetooth Serial Configuration

Refer to
[https://www.itead.cc/wiki/Serial_Port_Bluetooth_Module_(Master/Slave)_:_HC-05](https://www.itead.cc/wiki/Serial_Port_Bluetooth_Module_(Master/Slave)_:_HC-05)
for more information.

```
// Test command to check if we are communicating (expect to receive OK)
AT

//Name the module
AT+NAME=MK-312BT 

//Set baud rate to be same as the ATMEGA16
AT+UART=19200,0,0

//Set the pairing password
AT+PSWD=1234

//Set the LED Indicator polarity (1 = High Drive 0 = Low Drive)
AT+POLAR=1,1

// Reduce power consumption by increasing the scan interval. Without
// this it consumes ~43mA when not connected and causes the 5v regulator
// to get toasty (but still within operational temp range)
AT+IPSCAN=1024,1,1024,1 
```

To do this automatically:
1. Solder Pin32 of the HC05 module (See [bluetooth/HC05PINOUT.PNG](https://github.com/CrashOverride85/mk312-bt/blob/master/bluetooth_conf/HC05PINOUT.png) for reference)
2. Flash the included bin file onto the ATMEGA16
3. Plug the HC-05 bluetooth radio into the board (ensure pin 32 is
   soldered to the carrier board)
4. Place HC-05 in command mode by holding down the button on the HC-05
   module, power up MK-312BT and release button after 2 seconds. LEDs
   on HC-05 will blink slowly (0.5 Hz) to indicate command mode.
5. Watch GUI until it says the HC-05 configuration is finished and
   flash normal firmware back on to the ATMEGA16
6. If program stops on "Communicating with HC-05" make sure OSCCAL
   value for 8 MHz R/C position is copied to &H3FFF of bin location or
   use external 8 MHz crystal with appropriate fuse bits set (FFS use
   the external crystal)

## 3D Printable Case

STL files for a 3D printable case for the MK312 are available in the
case/ directory. For hardware, this case requires:

- 4 M2.5x20 screws
- up to 3 M2.5x5 screws
- some dampening for the battery (double sided foam tape may work)

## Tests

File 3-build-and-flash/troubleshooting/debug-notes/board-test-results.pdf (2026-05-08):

## MK-312-BT v1.4 — Test Results (fillable)

Black probe always = J1B (−) GND post. Click yellow boxes and type. Save the PDF when done.

## Test 1 — Power rails (multimeter: 20 V DC)

# | What to probe (red lead) | Expected | Result | Pass/Fail

1.1 | J1B (+) battery post | 11.5 – 13.5 V 13.3 V
1.2 | JP4 — +12V test point | 11.5 – 13.5 V 13.3 V
1.3 | JP3 — +5V test point | 4.85 – 5.15 V 5.0 V
1.4 | AVR socket pin 11 | 0 V (GND) 0
1.5 | AVR socket pin 31 | 0 V (GND) 0
1.6 | AVR socket pin 10 (VCC) | 4.85 – 5.15 V 5
1.7 | AVR socket pin 30 (AVCC) | 4.85 – 5.15 V 5
1.8 | LCD pin 1 (VSS) | 0 V 0
1.9 | LCD pin 2 (VDD) | 4.85 – 5.15 V 5
1.10 | LCD pin 3 (V0) — sweep VR4 | 0 V → 5 V across sweep .3

## Test 2 — AVR socket → LCD continuity (POWER OFF, AVR REMOVED, ribbon CONNECTED)

# | What to probe (red lead) | Expected | Result | Pass/Fail

2.1 | AVR pin 23 (PC1) → LCD pin 5 (R/W) | BEEP
2.2 | AVR pin 24 (PC2) → LCD pin 6 (E) | BEEP
2.3 | AVR pin 25 (PC3) → LCD pin 4 (RS) | BEEP
2.4 | AVR pin 26 (PC4) → LCD pin 11 (DB4) | BEEP
2.5 | AVR pin 27 (PC5) → LCD pin 12 (DB5) | BEEP
2.6 | AVR pin 28 (PC6) → LCD pin 13 (DB6) | BEEP
2.7 | AVR pin 29 (PC7) → LCD pin 14 (DB7) | BEEP

If any 2.x fails to BEEP, that signal's path is broken — check J11 and J10 pins, then trace.

## Test 3 — Solder bridge between adjacent pins (POWER OFF, AVR REMOVED)

# | What to probe (red lead) | Expected | Result | Pass/Fail

3.1 | AVR pin 22 ↔ 23 (PC0 / PC1) | NO beep
3.2 | AVR pin 23 ↔ 24 (PC1 / PC2) | NO beep
3.3 | AVR pin 24 ↔ 25 (PC2 / PC3) | NO beep
3.4 | AVR pin 25 ↔ 26 (PC3 / PC4) | NO beep
3.5 | AVR pin 26 ↔ 27 (PC4 / PC5) | NO beep
3.6 | AVR pin 27 ↔ 28 (PC5 / PC6) | NO beep
3.7 | AVR pin 28 ↔ 29 (PC6 / PC7) | NO beep

## Test 4 — LCD power, contrast, backlight (POWER ON)

# | What to probe (red lead) | Expected | Result | Pass/Fail

4.1 | Backlight glow (look in dim light) | YES
4.2 | Sweep VR4 fully both directions | Blocks fade dark↔light
4.3 | LCD pin 3 (V0) voltage as VR4 sweeps | ~0 V → ~5 V
4.4 | LCD DB4–7 floating (AVR out, probe 11–14) | ≈ 0 V each

## Notes / observations

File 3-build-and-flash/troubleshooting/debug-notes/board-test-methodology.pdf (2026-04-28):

# MK-312-BT v1.4 — Board Test Methodology

Systematic continuity & voltage checks to localize a build defect on a board that displays only solid blocks (no text). Tests verified against the v1.4 schematic and the BASCOM HC-05 firmware source which is known to drive this LCD correctly.

## Setup before any test

1. Power switch S5 OFF.
2. Disconnect the wall adapter from J8. Battery may stay connected to J1B during voltage tests, but pull it for continuity tests so the board is fully de-energized.
3. Pull the ATmega16 out of its socket using a chip extractor or two flat-blade screwdrivers, alternating from each end. Set it on antistatic foam.
4. Multimeter: rotary to continuity-beep mode for tests 2/3/4, to 20 V DC for test 1.
5. Identify a reliable ground reference on the mainboard: the negative (−) battery terminal at J1B. Every "GND probe" instruction in this document means "touch the J1B (−) post."
6. Test results in this document are derived from schematic page 2 (AVR & J11), schematic page 3 (front-panel J10/LCD/buttons), and the BASCOM HC-05 init source — the latter is ground truth because that firmware demonstrably drove this exact LCD model to readable text.

## Symptom under investigation

Power on → LCD top row shows solid black blocks, bottom row blank. No text ever (one transient "Failure 21" once after a ribbon-flip event, never reproduced). User has confirmed: +12 V at JP4 = 12.9 V ✓, +5 V at JP3 = 5.0 V ✓, fuses LFUSE=0xFF / HFUSE=0xDC ✓, f005 firmware verified after flash ✓.
Therefore: power rails and the AVR are healthy. The fault has to be in the front-panel signal path, in LCD power/contrast, or in a solder bridge between PORTC pins on the mainboard. Tests below isolate which.

# Reference 1 — ATmega16 pinout

The notch on the chip (and on the socket) marks the pin-1 end. With the notch oriented UP, pin 1 is top-left, pin counts go DOWN the left side, then UP the right side. Pins highlighted yellow are the ones referenced in the test procedures.

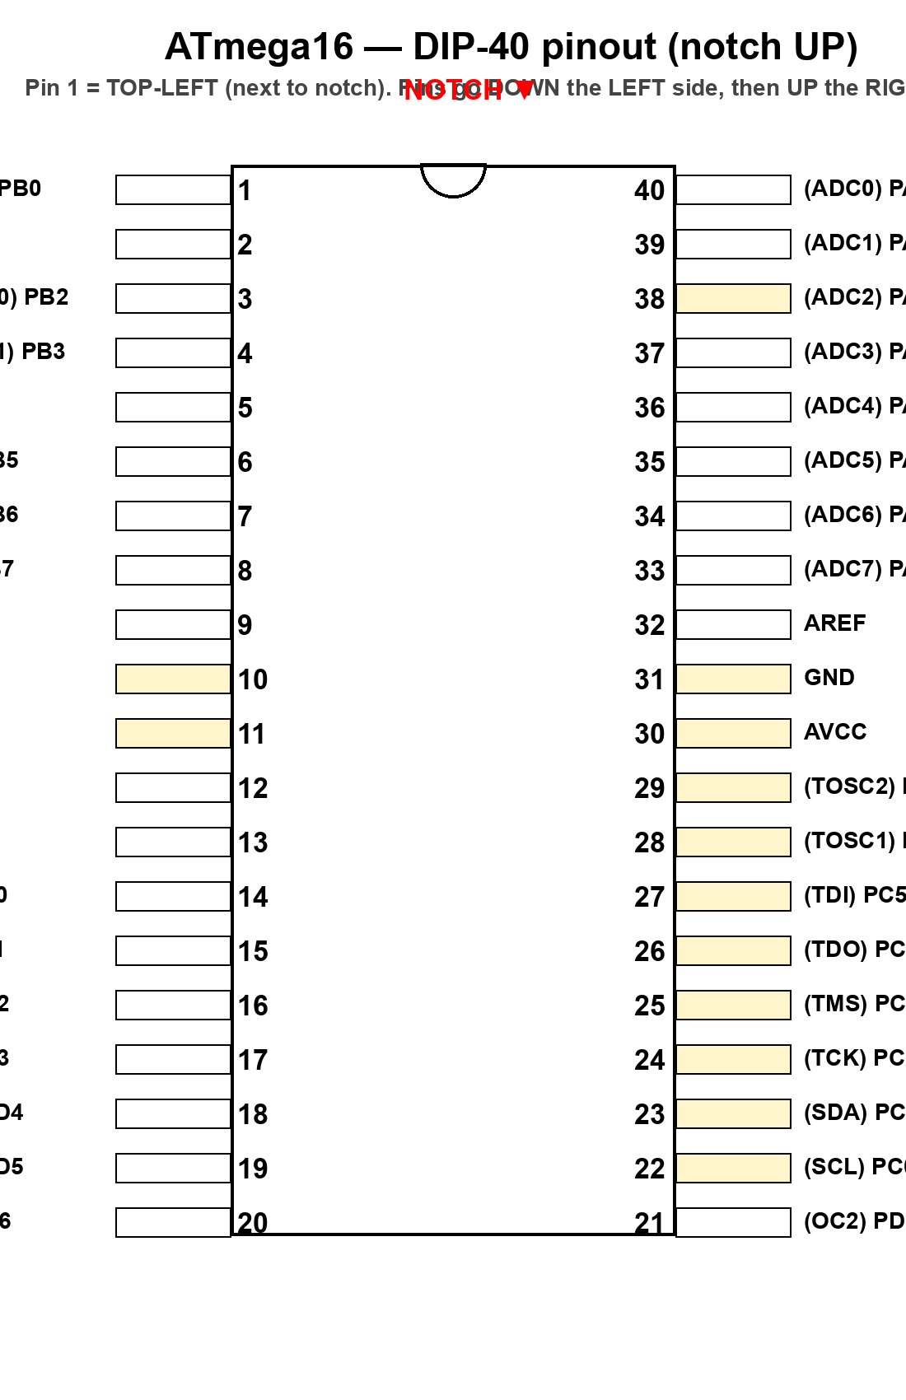
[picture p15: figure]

# Reference 2 — LCD pinout (NHD-0216K1Z)

Newhaven NHD-0216K1Z, HD44780/ST7066U-compatible, 16-pin single inline header. Pin 1 is on the LEFT when looking at the LCD from the FRONT (text side). The back of the module usually has "1" and "16" silkscreened next to the end pins.

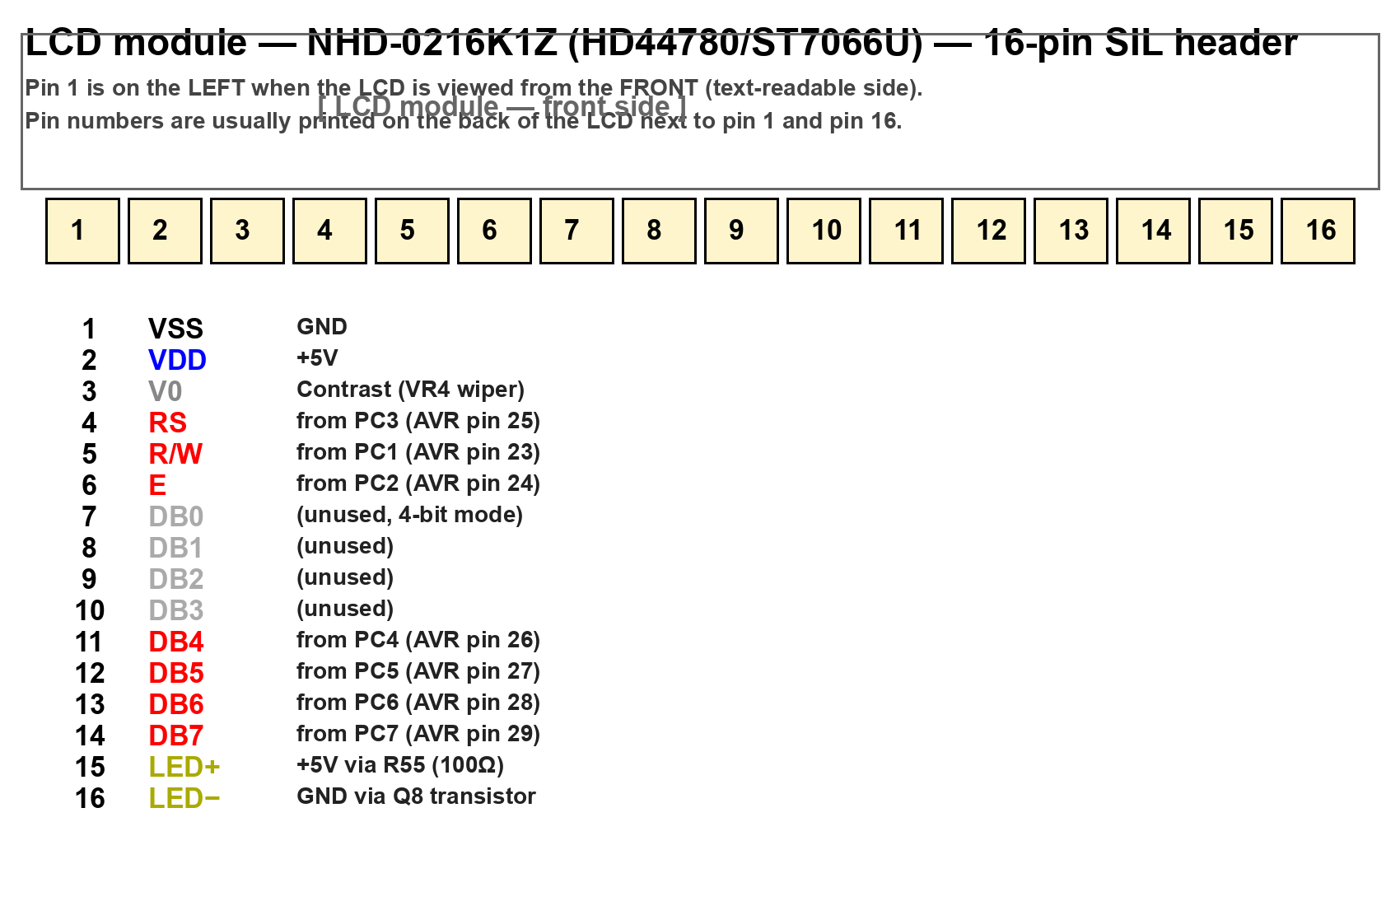
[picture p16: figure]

Pin assignments above are taken from schematic page 3 + the BASCOM HC-05 firmware source: Db4=PC4,
Db5=PC5, Db6=PC6, Db7=PC7, E=PC2, RS=PC3. R/W is firmware-driven LOW on PC1 — it is not tied to GND on the board, so probing PC1 → GND should NOT beep (this is correct).

# Reference 3 — Silkscreen overview (where the test points are)

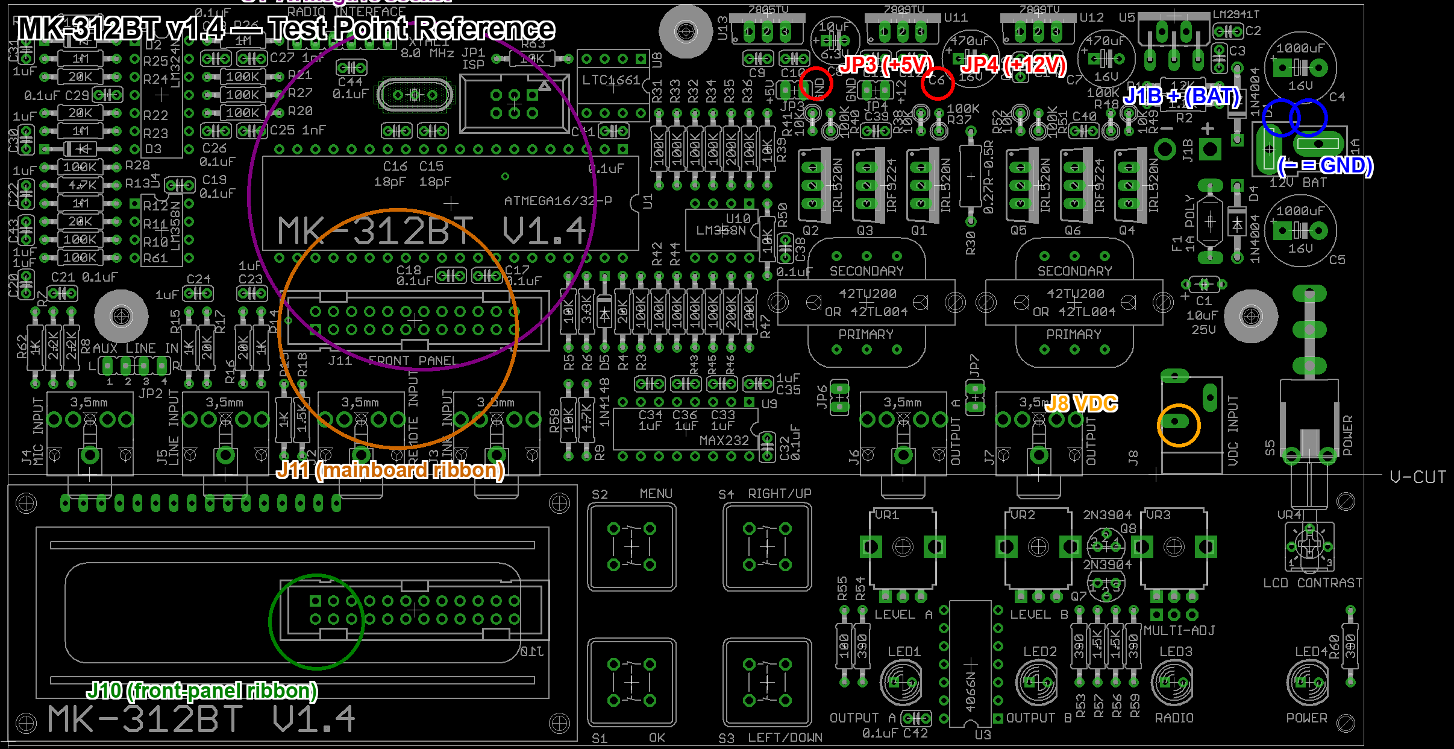
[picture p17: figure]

Top half of the panel = mainboard. Bottom half = front panel (LCD + buttons + pots).
- JP3 / JP4 — small 2-pin headers near the top, just below the linear regulators. JP3 = +5V/GND (the +5V rail test point). JP4 = +12V/GND (the +12V rail test point).
- J1B (battery) — two screw-terminal posts at top-right. Left = +12V battery, right = GND. The right post is the cleanest ground reference for everything in this document.
- J8 (VDC INPUT) — barrel jack on the right edge. Wall-adapter input. The center pin is +. Should read 0 V on battery-only operation.
- U1 (ATmega16 socket) — the 40-pin DIP socket in the middle of the mainboard, oriented with its long axis horizontal. The notch on the socket is on the LEFT.
- J11 — 24-pin ribbon header on the mainboard, just below U1. Connects via ribbon to J10 on the front panel.
- J10 — 24-pin ribbon header on the front-panel side. Other end of the ribbon. Same pin numbers as J11 (J11-1 ↔ J10-1).

# Test 1 — Power rails (DC voltage)

Multimeter: 20 V DC. Power switch S5: ON. AVR can stay in or out for this test.

# | Black probe | Red probe | Expected | Pass / Fail

1.1 | J1B (−) post | J1B (+) post | 11.5 – 13.5 V | ____
1.2 | J1B (−) post | JP4 (+12V pad) | 11.5 – 13.5 V | ____
1.3 | J1B (−) post | JP3 (+5V pad) | 4.85 – 5.15 V | ____
1.4 | J1B (−) post | AVR socket pin 11 | ≈ 0 V (GND) | ____
1.5 | J1B (−) post | AVR socket pin 31 | ≈ 0 V (GND) | ____
1.6 | J1B (−) post | AVR socket pin 10 | 4.85 – 5.15 V (VCC) | ____
1.7 | J1B (−) post | AVR socket pin 30 | 4.85 – 5.15 V (AVCC) | ____
1.8 | J1B (−) post | LCD pin 1 (VSS) | ≈ 0 V | ____
1.9 | J1B (−) post | LCD pin 2 (VDD) | 4.85 – 5.15 V | ____
1.10 | J1B (−) post | LCD pin 3 (V0) | 0.0 – 1.0 V (VR4 contrast) | ____

If 1.10 reads > 1.0 V or stays at 5 V regardless of VR4 rotation: contrast pot wiper is shorted or the V0 trace from VR4 to LCD pin 3 is broken. With contrast at 5 V the LCD will show ALL solid blocks and never text — this is a leading suspect for the symptom.
If 1.6 or 1.7 ≠ +5 V: a trace from JP3 to U1 VCC/AVCC is broken. AVR cannot start.

# Test 2 — AVR socket → LCD continuity (with ribbon connected)

POWER OFF, AVR REMOVED, RIBBON CABLE CONNECTED between J11 and J10. Multimeter to continuity-beep mode.
Each row tests one signal. Probe the SOCKET hole on the mainboard (where the AVR pin would land), and the LCD pin. The trace path is: AVR socket → mainboard trace → J11 pin → ribbon wire → J10 pin → front-panel trace → LCD pin. With a healthy build and correct ribbon orientation, this chain has < 5 Ω end-to-end and the meter beeps.
# | AVR socket pinSignal | | LCD pin | LCD signal | Should | Result

2.1 | 23 | PC1 / R/W | 5 | R/W | BEEP | ____
2.2 | 24 | PC2 / E | 6 | E | BEEP | ____
2.3 | 25 | PC3 / RS | 4 | RS | BEEP | ____
2.4 | 26 | PC4 / DB4 | 11 | DB4 | BEEP | ____
2.5 | 27 | PC5 / DB5 | 12 | DB5 | BEEP | ____
2.6 | 28 | PC6 / DB6 | 13 | DB6 | BEEP | ____
2.7 | 29 | PC7 / DB7 | 14 | DB7 | BEEP | ____
2.8 | 22 | PC0 / mux | — | (to U3 4066 B-pins, not LCD) | no LCD pin | n/a

If ANY of 2.1 – 2.7 fails to beep: there is a break in that signal's path. Most likely causes, in order: (a) cold solder joint on a J11 or J10 pin (re-solder both connectors), (b) cracked PCB trace on the front panel,
(c) ribbon cable wire broken (swap cable), (d) bent/missed pin in J11 or J10 receptacle.

Also worth checking — ribbon orientation: with both ends in the correct orientation, J11-1 connects to J10-1 (and J11-21 = +5V on both ends). If the ribbon is reversed, +5V on J10-21 would map to J11-4 (PC1) — which would push voltage backwards into the AVR's pin and is exactly the kind of event that could trigger a transient "Failure 21" only on the first switch-on after a flip. Verify red stripe on the cable is on the same end (pin 1 side) of both connectors.

# Test 3 — Solder-bridge check between adjacent socket pins

POWER OFF, AVR REMOVED. Continuity-beep mode.
Probe two ADJACENT socket holes. Should NOT beep. A beep here means molten solder bridged between two AVR pins underneath the socket — common cause of "all blocks, no text" because the AVR ends up driving multiple LCD lines together.
# | Pin A | Pin B | Signals | Should beep?

3.1 | 22 | 23 | PC0 (mux) — PC1 (R/W) | NO
3.2 | 23 | 24 | PC1 (R/W) — PC2 (E) | NO
3.3 | 24 | 25 | PC2 (E) — PC3 (RS) | NO
3.4 | 25 | 26 | PC3 (RS) — PC4 (DB4) | NO
3.5 | 26 | 27 | PC4 (DB4) — PC5 (DB5) | NO
3.6 | 27 | 28 | PC5 (DB5) — PC6 (DB6) | NO
3.7 | 28 | 29 | PC6 (DB6) — PC7 (DB7) | NO
3.8 | 29 | 30 | PC7 (DB7) — AVCC | NO (would short DB7 to +5V)
3.9 | 30 | 31 | AVCC — GND | NO (would dead-short the AVR)

If ANY pair beeps: visually inspect the underside of the AVR socket with a magnifying glass and good light. Look for a tiny solder ball or whisker between adjacent pads. Reflow with flux + braid to remove. Re-test before proceeding.

# Test 4 — LCD power, contrast, and backlight

POWER ON, AVR can be in or out. If the symptom is "all blocks, no text" and Test 1 passed, this test isolates contrast/backlight as the cause.

# | Step | Procedure | Expected

4.1 | Backlight on? | Look at the LCD with the lights dim. Is the green/blue backlight glowing? YES (glow visible)
4.2 | Contrast sweep | With the box on and showing blocks, slowly rotate VR4 (LCD CONTRAST) all the way one direction, then the other. Blocks should fade to pale, then darken to solid; SOMEWHERE in the sweep, characters should appear if signals are correct.
4.3 | V0 voltage | Multimeter 20 V DC. Black probe = J1B (−). Red probe = LCD pin 3 (V0). Sweep VR4. V0 should change continuously between ≈ 0 V and ≈ 5 V as VR4 rotates. If it sticks at 5 V → LCD always shows solid blocks regardless of data.
4.4 | DB lines static | AVR removed. Multimeter 20 V DC. Probe LCD pin 11/12/13/14 (DB4–7) vs GND. Without AVR, all DB lines should float ≈ 0 V (no pull-ups on the data bus). If any reads +5V steady, there's a short to VCC.

Why this matters: a stuck-high V0 line (5 V at LCD pin 3) makes the controller render every dot black regardless of what
data the AVR sends — it's a textbook "all blocks, no text" symptom that's purely analog and has nothing to do with
firmware. If 4.3 fails (V0 won't sweep), check VR4 wiper continuity and the 100 Ω R55 between V0 and the +5V backlight
rail.

# Decision tree

Run tests 1 → 2 → 3 → 4 in order. After each, branch on the result:

Test 1 (rails) FAILED any row.
Don't proceed. Fix the rail first — there's no point checking signal paths until VCC/AVCC are correct. Most likely: cold joint on regulator pin or 7805 input cap.
Test 2 (AVR → LCD continuity) FAILED any row.
That signal's trace is broken. Resolder both ends of the implicated J11/J10 pin first (cheapest fix). If still broken, inspect the trace with a magnifier — a hairline crack between J11 and the AVR socket is the most common build defect on this board.

Test 3 (solder bridge) FAILED any row.
Reflow the AVR socket pads with flux. A bridge between PC4–PC7 will look like "all blocks" because two LCD data lines get tied together — the controller sees garbage in both nibbles of every byte.

Test 4 (LCD power) FAILED.
If V0 won't sweep with VR4, the LCD itself can't render text — fix this before assuming anything is wrong with the firmware or the AVR.

All tests PASS but symptom persists.
At that point the LCD signal path is electrically clean and the AVR is healthy. Two remaining hypotheses, in order of likelihood:
(a) LCD module is dead or has wrong controller revision. Swap the LCD with a known-good 1602 (any HD44780/ST7066U/SPLC780 will do) and retry. ~$5 part, fastest test.
(b) LCD reset timing — the f005 firmware does an HD44780 init sequence assuming the LCD is in its reset state at power-on. The Newhaven ST7066U datasheet requires Vcc to rise from 0.1 V to 4.5 V within 0.1–10 ms for its internal POR to fire reliably. If the v1.4 power supply rises slower (typical with 1000 µF bulk caps + ferrite to AVCC), the LCD enters an undefined state and ignores the init sequence. Workaround: a watchdog reset pulse on the LCD or a firmware re-init. See docs/troubleshooting/debug-notes/failure-21-analysis.md §7.1 for the disassembly evidence.

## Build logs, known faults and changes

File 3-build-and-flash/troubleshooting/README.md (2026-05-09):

# Troubleshooting

Three kinds of material here:
1. **`debug-notes/`** — original, evidence-based debug documents written for this repo. Start here for live builds.
2. **`metafetish.club` archive** — saved forum threads from before the canonical MK-312BT discussion site went offline.
3. **`mosfetkiller.de` archive** — translated German DIY-electronics forum thread covering MK-312-BT builds, with a key correction to the canonical fuse settings.

## Active debug notes (read these first)

| File | When to read |
|---|---|
| [`debug-notes/board-test-methodology.pdf`](debug-notes/board-test-methodology.pdf) | **Symptom: LCD shows solid blocks, no text.** Step-by-step bench procedure with annotated silkscreen plus ATmega16/LCD pinout references. Power-rail, AVR-socket→LCD continuity, solder-bridge, and contrast/backlight tests with pass/fail decision tree. |
| [`debug-notes/failure-21-analysis.md`](debug-notes/failure-21-analysis.md) | Disassembly-grade analysis of the v1.4 boot self-test. Refutes the forum lore that "Failure 21 = channel B mirror of Failure 20" — F21 is the wall-adapter voltage sanity check at PA2 (≥17.1 V trips it). Includes the Newhaven ST7066U power-on reset timing hypothesis for the all-blocks-no-text symptom. |

## metafetish.club archive

The metafetish.club forum (the canonical MK-312BT discussion venue) went offline. These PDFs are saved threads from before the shutdown — the highest-quality archived troubleshooting material that exists for this board.

### What's here

| File | When to read |
|---|---|
| [`MK-312BT Failure 20 - Estim - Metafetish.pdf`](MK-312BT%20Failure%2020%20-%20Estim%20-%20Metafetish.pdf) | Box shows "Error 20" on boot — the most common build defect |
| [`Another Failure 20 with measurements and some test mode_ - Estim - Metafetish.pdf`](Another%20Failure%2020%20with%20measurements%20and%20some%20test%20mode_%20-%20Estim%20-%20Metafetish.pdf) | Failure 20 deeper dive with scope measurements and test mode usage |
| [`MK312BT Firmware and function issues (Failure 20), debug suggestions_ - Estim - Metafetish.pdf`](MK312BT%20Firmware%20and%20function%20issues%20%28Failure%2020%29%2C%20debug%20suggestions_%20-%20Estim%20-%20Metafetish.pdf) | Firmware-side debugging when hardware looks fine |
| [`MK-312BT Transformer Question - Estim - Metafetish.pdf`](MK-312BT%20Transformer%20Question%20-%20Estim%20-%20Metafetish.pdf) | Picking transformers, 42TU200 vs 42TL004 |
| [`MK-312BT parts substitution - Estim - Metafetish.pdf`](MK-312BT%20parts%20substitution%20-%20Estim%20-%20Metafetish.pdf) | Substitutes for parts Mouser is out of |
| [`Some oscillograms from estim units - Estim - Metafetish.pdf`](Some%20oscillograms%20from%20estim%20units%20-%20Estim%20-%20Metafetish.pdf) | Reference scope traces from a working unit |
| [`Tri Phase Cable on MK312BT - Estim - Metafetish.pdf`](Tri%20Phase%20Cable%20on%20MK312BT%20-%20Estim%20-%20Metafetish.pdf) | Tri-phase output cable wiring |
| [`Getting the Firmware for MK312 - Estim - Metafetish.pdf`](Getting%20the%20Firmware%20for%20MK312%20-%20Estim%20-%20Metafetish.pdf) | Where the AVR firmware comes from |
| [`Is the MK-312 BT modern_ - Estim - Metafetish.pdf`](Is%20the%20MK-312%20BT%20modern_%20-%20Estim%20-%20Metafetish.pdf) | Background and context — whether this design is still worth building |

## mosfetkiller.de archive

A German-language DIY-electronics forum where several builders worked through MK-312-BT problems in 2021–2022. The thread surfaces a **non-trivial correction to the canonical fuse settings** that the metafetish archive doesn't cover.

| File | When to read |
|---|---|
| [`mosfetkiller-mk312-thread-en.md`](mosfetkiller-mk312-thread-en.md) | **Read if your board flashes but boots into a row of solid white blocks on the LCD, or if RESET pin behaves wrong, or if Failure 20 persists despite verified MOSFETs.** Contains: HFUSE 0xDC → 0xD9 fix (boot-vector bug breaks application-only firmware), F20 fix via R32/R43 trim-pot tuning (alternative to MOSFET replacement), F21/F16 quick references. English translation with original German preserved. |

## Live community

For ongoing help: `#boxes-pulse-based-diy` and `#312-chat` on [Joanne's E-Stim Community Discord](https://discord.gg/rY8C27S).

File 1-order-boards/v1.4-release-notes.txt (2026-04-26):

MK-312BT V1.4 05-19-2019 

Noteable design changes:

Board reconfigured to allow 42TU200 transformers, 42TL004 still useable by bending the wires slightly during insertion.

U4B (Mic Preamp) reconfigured as recommended by TI application for an unused op-amp section.

J10 repositioned on display panel for much shorter ribbon cable.

U8A/U8B changed to U8 for LTC1661 

R63 10K added to reset line of ATMEGA.

C6 and C7 repositioned to allow better spacing from regulators.

D5 1N4148 added to DC input line for additional protection to ATMEGA incase wrong polarity power supply.

Recommendations:

C6 and C7 should be Low ESR type electrolytics.

When using 42TU200 Transformers, if higher output current is desired use 0.27 Ohm for R30, and 680uF-820uF for C6 and C7.
42TU200 transformers were tested and known to work with 0.5, 0.30 and 0.27 ohm resistors at R30.

R55 recommended 100 - 220 ohm for LCD backlight as it is a single LED in New Haven displays. 

J2-J7 can be replaced by STX-3100-5N, same part minus the plastic back cover.  https://www.mouser.com/ProductDetail/Kycon/STX-3100-5N

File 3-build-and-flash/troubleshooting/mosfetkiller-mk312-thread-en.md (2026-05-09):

# mosfetkiller.de MK-312-BT thread (English translation)

**Source:** [forum.mosfetkiller.de viewtopic.php?t=64758&start=15](https://forum.mosfetkiller.de/viewtopic.php?t=64758&start=15)

**Original language:** German.
**Captured:** 2026-05-09. Translation by AI; original German posts preserved at the end of each entry for verification.

A German DIY-electronics forum thread (mosfetkiller.de = "MOSFET killer", a friendly e-stim builder community) covering MK-312-BT troubleshooting. The most important technical contribution in the thread is **MWU's correction to the published fuse settings** — `hfuse=0xDC` (the canonical value distributed with the project) breaks the RESET pin behavior; `hfuse=0xD9` is the correct value. Confirmed by another builder in the next post.

---

## Critical findings — read first

### 1. The published `hfuse=0xDC` may be incorrect

Per **MWU** (post #13) and confirmed by **MauiKano** (post #14): the canonical fuse values cause the boot-vector fuse to be enabled, which breaks the RESET pin behavior. If the chip boots into a row of solid white blocks on the LCD and won't reset:

| | Canonical (this repo) | MWU's correction |
|---|---|---|
| LFUSE | 0xFF | 0xFF (same) |
| **HFUSE** | **0xDC** | **0xD9** |

Decoding `0xDC` vs `0xD9`:

- `0xDC` = `1101 1100` → BOOTSZ=11 (256 words), **BOOTRST=0** (boot vector enabled — jump to bootloader on reset)
- `0xD9` = `1101 1001` → BOOTSZ=11 (256 words), **BOOTRST=1** (boot vector disabled — jump to 0x0000 on reset)

The other bits (JTAGEN, OCDEN, SPIEN, etc.) are unchanged. Only BOOTRST differs.

So `0xDC` only works if you're flashing the t002 bootloader **first** and the application firmware on top — the boot vector is supposed to point at the bootloader. If you're flashing application firmware **alone** (no bootloader), use `0xD9` so the chip starts at address 0x0000 on reset.

**Suggestion for this repo:** verify what fuses the various firmware files actually expect and update `docs/build-guide.md` accordingly. The current build guide says `hfuse=0xDC` universally, which is correct **only if the t002 bootloader path is followed**. For builders flashing `f005-HelloFriend.bin` or similar application-only firmware directly, `hfuse=0xD9` is the correct value.

### 2. F20 fix without replacing MOSFETs

Per **MWU** (post #13): instead of swapping mismatched FETs, you can compensate at R32/R43:

- Replace R32 and R43 (the 100 kΩ resistors in the gate-bias network) each with a 470 kΩ trim pot
- Power on, observe F20
- Dial both pots down by equal small amounts, press RESET (you'll need a momentary button to GND on the ISP RESET pin)
- Repeat until F20 clears
- Note the resistance values, then dial up further until F20 returns
- Pick the midpoint, replace pots with fixed resistors at that value

MWU's working value: **120 kΩ for both**. This contradicts the canonical 100 kΩ — the resistance needed depends on the specific MOSFETs installed. With matched FETs the canonical 100 kΩ should work; with off-spec FETs you may need to adjust.

Optional scope verification: scope CH1 (2 V/div) on the ISP RESET pin (one-shot trigger on falling edge), CH2 (10 mV/div) on R30 or one of the FET sources. After RESET you should see two pulse ramps during the self-test. The R32/R43 value range that produces visible passing ramps is what you're looking for.

---

## Per-post translation

### Post 1 — MaxZ (Luca), 2021-10-21

> Good evening everyone. Good news, the box runs!
>
> To help others, let me briefly describe the problems that led to it not working.
>
> The MOSFETs were, as suspected, not the problem. Even so, I tried whether the IRL520N functions identically to the LU120N (both Infineon) — yes, both are recognized by the software without issues.
>
> The problem was an almost invisible break in a solder joint. Probably the previous board didn't start because of a mismatched audio transformer. And on the first board I had the wrong firmware.
>
> Well, a chain of unfortunate circumstances, but I learned a lot from the troubleshooting. That's the most important part.
>
> Beforehand I tested the display itself — I wrote software in Microchip Studio that just outputs simple text. That worked, and afterward the ATmega running the firmware also showed me an error, when previously I'd only gotten an uninitialized display. Maybe it just needed to start up once before things continued.
>
> If anyone has the same problem or is interested in an ET-312 clone build, feel free to PM me. Maybe we can find a solution together.
>
> Thanks again for your tips, that really helped me a lot.
>
> LG, Luca

### Post 2 — ebastler (Paul Wilhelm), 2021-10-22

> Hey Luca, glad you could finally solve the problem. — Paul

### Post 3 — SeriousD, 2021-10-28

> Great that you solved it, I sent you a PM.

### Posts 4–9 — Bombenleger802, Paul, tobias966 (front-panel manufacturing discussion)

These posts cover front-panel manufacturing logistics — Schaeffer AG vs JLCPCB for engraved aluminum vs PCB front panels. Tobias confirms (post #9) that JLCPCB-produced PCB front panels look great. Not relevant to the electrical/firmware problems this archive covers.

### Post 10 — MauiKano, 2021-12-09

> One step further. Looks like I'm close. I can flash firmware. When I flash the initial firmware for the HC-05 Bluetooth module, I see the correct dialog on the display — meaning AVR runs and the display is wired correctly. But when I flash the regular MK-312 firmware (e.g. `Custom Boot Message f005-MK312-BT`), I get either "Failure 20 Shut Off Power!!" or, by reducing input voltage, I can also provoke "Battery Low Shut Off Power."
>
> From all of this I conclude that the MK-312 firmware is running on the AVR but hangs on Error 20 due to some hardware (or other) error. Does anyone know more?

### Post 11 — MauiKano, 2022-01-04

> Hello Luca, I have exactly the problem you described. A row of white blocks in the display.
>
> I'm flashing with a GALEP-5. I think I've set the fuses for the external crystal correctly. All firmware (BT config, "electrodes ready," and F005.bin) produces the same result. A new hardware build behaves identically. What ultimately solved it for you?
>
> Florian

### Post 12 — Thunderbolt (Luca), 2022-01-22

> Hello Florian, sorry for the late reply. I got your PM but I'd rather answer here so others get the benefit.
>
> As mentioned in my earlier post, the issue was mainly with the solder joints. I built the board 4 times in the end before it ran correctly.
>
> When things go badly there's a chain of circumstances.
>
> Check all solder joints again, especially around the op-amps and the ATmega.
>
> Also check that you unzipped the .zip correctly and the .bin isn't corrupted. That happened to me once and I always thought the board didn't work.
>
> You could also scope the output stage during startup — there should be a ramp on startup. (I only have this info from others.)
>
> If problems persist, just contact me again. — Luca

### Post 13 — Thunderbolt (MWU?), 2022-01-24 ⭐ KEY TECHNICAL CONTRIBUTION

> Hello everyone. (I found V1.3R + front PCB on easyEDA and had them made by JLCPCB. Three sets still available. Built two: they work!)
>
> **The fuses are not correct. No boot vector should be used.** You can tell because the RESET pin at ISP (add 10k pull-up to plus and 0.1 µF to GND) doesn't work. **Correct values are e.g. L:FF and H:D9** (I use L:3F H:C9).
>
> Now with the device powered on you can do a reset (briefly tie RESET pin to GND) and trigger a restart.
>
> **Error 21:** Supply voltage / wall adapter should be between 15–19 V.
>
> **Error 20:** Often comes when MOSFETs other than specified are used.
>
> Solution: adjust both 100 kΩ resistors R32 and R43.
>
> 1. Solder a pot (e.g. 470 kΩ) in place of each.
> 2. Install a momentary button to GND on the RESET pin of the ISP.
> 3. Set both pots to max R.
> 4. Power on the device.
> 5. Error: turn both pots down by the same small amount and press RESET.
> 6. At the same time, experiment with both pots.
> 7. Repeat until no more error.
> 8. Measure the pot resistance values out-of-circuit and remember them.
> 9. Continue tweaking until the error returns.
> 10. Determine values, calculate the midpoint of both, and install a matching fixed resistor.
>
> If you have a scope: CH1 (2 V/div) on the ISP RESET pin, one-shot trigger on falling edge. CH2 (10 mV/div) on R30 or one of the FET sources. After RESET you should see two pulse ramps during the self-test. (Important: one-shot trigger.) From a certain resistance up to a certain resistance it will work. I picked the middle and soldered it in. For me, it's **120 kΩ for both**.
>
> **Error 16:** Solution: factory reset. Hold UP/DOWN during power-on until the self-test completes.
>
> Best regards and good luck. MWU

### Post 14 — MauiKano, 2022-01-24

> Hello everyone. Many thanks to Luca and MWU. The solution was as MWU described: **correcting the high fuse setting to D9**. Now the box runs.
>
> Florian

### Post 15 — MauiKano, 2022-03-06

> Good evening everyone. My MK-312 BT runs with the known firmware, after some startup difficulties. Because I wanted to extend/modify the box, I started rebuilding the firmware. I now have a software state that I wouldn't yet call a production release, but the essential functions are implemented and working — so I'm publishing it as a first alpha release at https://github.com/MauiKano/DFD312. Looking forward to feedback from the ET/MK 312 community.

---

## Cross-reference to repo

- The `hfuse=0xD9` correction should be evaluated against the firmware files in `3-build-and-flash/firmware/`. If application-only firmware (e.g. `f005-HelloFriend.bin`) is flashed without the t002 bootloader, MWU's `0xD9` is likely the correct value, not the `0xDC` currently documented.
- The R32/R43 trim-pot procedure for F20 is an alternative path when MOSFET matching isn't possible (no spare FETs, no component tester, or working with a built board that already has soldered FETs). Documented in `docs/troubleshooting/debug-notes/failure-20-analysis.md` as the "Fix" section can be expanded with this procedure.
- The "row of white blocks on display" symptom is now linked to the wrong-fuse condition — worth documenting in the build guide alongside the LCD contrast explanation.
- MauiKano (post #15) wrote his own alternative firmware: [MauiKano/DFD312](https://github.com/MauiKano/DFD312). Could be added to ROADMAP.md as a firmware alternative to investigate.

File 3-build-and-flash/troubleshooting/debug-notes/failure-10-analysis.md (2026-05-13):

# Failure 10 — DAC write value out-of-range (≥ 224)

| Field | Value |
| --- | --- |
| Code (decimal) | **10** |
| Branch site | `0x0bba` (`rjmp .+2746` → `0x1676`) |
| Test type | Argument range check inside the DAC writer |
| When it runs | Every DAC update — ramp engine, knob change, mode switch |
| Class | Firmware/state — almost never hardware |

## Summary

F10 fires when the firmware tries to push a value ≥ 224 to the SPI DAC via the
routine at `0x0b98`. The routine cascades through three range checks and routes
legal values into different sub-paths; anything ≥ 0xE0 falls off the end of the
cascade and trips F10. In normal operation valid DAC values stay below 0xC0,
so F10 indicates that the firmware's intensity/level state has gotten into a
bad value — usually a knob/pot reading way out of band, a bus glitch corrupting
an intermediate calculation, or a ramp/multiplier bug. F10 is rare in the wild
compared to F20/F21.

## Disassembly evidence

The DAC writer at `0x0b98` takes the requested value in `r26`:

```
0b98:  push r30, r31, r28
0b9e:  lds  r30, 0x0207        ; load DAC channel flag
0ba2:  and  r30, r30
0ba4:  breq 0x0bac             ; if no override, use r26 directly
...
0bac:  cpi  r26, 0x80          ; r26 < 128 ?
0bae:  brcs 0x0bbe             ;   yes → normal write path
0bb0:  cpi  r26, 0xC0          ; r26 < 192 ?
0bb2:  brcs 0x0c24             ;   yes → alternate path
0bb4:  cpi  r26, 0xE0          ; r26 < 224 ?
0bb6:  brcs 0x0bbc             ;   yes → another path
0bb8:  ldi  r26, 0x0A          ; ← loads code 10
0bba:  rjmp 0x1676             ; ← FAILURE 10
```

The cascade implements a banded DAC update: low values (< 128) write directly,
mid-band values take a slow-update path, upper-mid values (192–223) take a
special case, and the top band (≥ 224) is treated as illegal.

## Likely cause

1. **Ramp/multiplier overflow.** The firmware's ramp engine computes
   intermediate values that can exceed 0xE0 if a starting DAC seed plus an
   accumulated delta wraps the byte. Triggered most often when a pot wire is
   broken or shorted and the ADC reads an extreme value.
2. **Pot wire fault.** If the level pot's wiper is shorted to V+ or open, the
   firmware's pot→DAC mapping can produce an out-of-range intensity request.
3. **EEPROM corruption.** A corrupt stored level/setting at boot can seed the
   level engine with a bad value. Power-cycle and full EEPROM reset (or
   reflash `backup_eeprom.bin`) addresses this.

## Diagnostic procedure

1. Power-cycle the box. If F10 reproduces immediately on every boot, suspect
   EEPROM corruption — try reflashing the known-good `backup_eeprom.bin`
   (`avrdude … -U eeprom:w:backup_eeprom.bin`).
2. If F10 only fires when adjusting a knob, measure each pot's wiper voltage
   with a multimeter. Should sweep cleanly between 0 V and ~5 V across the
   full rotation. A jumpy or stuck reading points at the offending pot.
3. Reseat the front-panel ribbon — vibration can intermittently open one of
   the pot lines.

## Fix

If EEPROM corruption: reflash `backup_eeprom.bin` and full reseat. If pot
fault: replace the offending pot or repair the wiring. F10 from a normal build
with no EEPROM history is uncommon — the first port of call is always the
front-panel ribbon.

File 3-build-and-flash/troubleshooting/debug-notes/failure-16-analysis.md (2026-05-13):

# Failure 16 — output-level mapping won't converge

| Field | Value |
| --- | --- |
| Code (decimal) | **16** |
| Branch site | `0x15fa` (`rjmp .+122` → `0x1676`) |
| Test type | Iteration-counter sanity check |
| When it runs | Continuously during normal output — every DAC setpoint update |
| Class | Most often a pot/ribbon hardware fault |

## Summary

F16 fires from inside `Function_0x15b8`, the routine that maps pot/ramp
positions to output DAC seeds. The function uses an iteration counter at RAM
`0x01F4`; if that counter reaches 4 without the calculation converging, F16
trips. In practice this means the pot inputs are reading values that produce
no valid intensity mapping — either out-of-range pot ADC values, or a corrupt
ramp profile that diverges instead of settling.

## Disassembly evidence

```
15b8:  push r26, r27
15bc:  ldd  r30, Y+4         ; load DAC base for channel
15c0:  ldd  r2,  Y+11        ; load step delta
15c4:  lds  r26, 0x01F4      ; load iteration counter
15c8:  cpi  r26, 0x04        ; counter < 4 ?
15ca:  brcc 0x15f8           ;   no → fail
...                          ; iteration body, increments counter
15f8:  ldi  r26, 0x10        ; ← loads code 16
15fa:  rjmp 0x1676           ; ← FAILURE 16
```

The body of the function (`0x15cc`–`0x15f6`) computes a target DAC value from
the current pot reading + ramp position. Each iteration that doesn't converge
increments RAM[0x01F4]; if it reaches 4 without convergence, F16.

## Likely cause

1. **Pot wiper noise / dropout.** A noisy or intermittently open pot wiper
   makes the pot ADC reading jump on every sample, so the iteration never
   settles. Most common physical cause.
2. **Ribbon cable fault.** The front-panel ribbon connector has 24 pins and
   carries every pot signal. A loose pin produces F16-like behavior.
3. **ADC reference glitch.** If AVCC or AREF is noisy, ADC readings drift
   between consecutive samples and the iteration can't converge.

## Diagnostic procedure

1. **Reseat the front-panel ribbon** — first thing to try.
2. With the box powered, measure each level pot's wiper voltage on the ATmega
   side of the ribbon while slowly rotating the knob. Reading should sweep
   smoothly from ~0 V to ~5 V. Any sudden drops or flat spots = pot bad.
3. With a scope (if available), look at AVCC (pin 30) and AREF (pin 32) —
   should be clean 5.0 V. Ripple > ~50 mV on either rail can cause F16.

## Fix

Reseat ribbon → replace offending pot if measurements show dropout → in rare
cases, replace bypass caps on AVCC/AREF if rails are noisy. F16 is rarely a
build error; usually a worn-knob or loose-ribbon condition that develops
over time.

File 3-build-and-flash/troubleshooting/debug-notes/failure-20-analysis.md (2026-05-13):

# Failure 20 — output stage current sense (channels A and B)

| Field | Value |
| --- | --- |
| Code (decimal) | **20** |
| Branch site | `0x1494` (`rjmp .+480` → `0x1676`) |
| Test type | Output stage current-sense, both channels |
| When it runs | Once at boot, after F21 voltage check passes |
| Class | Almost always hardware — MOSFETs, transformer, R35/R46 |

## Summary

F20 is the post-boot output-stage self-test, and the most common build failure
on first power-up. A single routine at `Function_0x1406` drives PB2+PB3
(channel A) and then PB0+PB1 (channel B) while monitoring ADC0 (R30 current
sense). On each pass it ramps the DAC down from a low-power seed and looks
for the R30 current to settle within bounds. If either channel can't deliver
current, or the current runs away, F20 fires.

**The forum lore that pairs F20 (channel A) with F21 (channel B) is wrong** —
F20 alone tests both channels; F21 is the wall-adapter voltage check.

### How the calibration loop works

```mermaid
flowchart TD
    accTitle: F20 calibration servo loop
    accDescr: The firmware calibrates the output stage by ramping the DAC down step by step. Each step pulses the channel FETs, samples ADC0 across R30, and either advances if the current is low enough or decrements the DAC and tries again. After 64 unsuccessful attempts, F20 fires.

    start(["Boot — start with channel A<br/>DAC seed = 100 (4.38 V)"])
    pulse["Pulse PB2+PB3 ON briefly<br/>(channel A FETs Q1+Q2)"]
    wait_adc["Wait, gates OFF<br/>Read ADC0 (voltage across R30)"]
    threshold{"ADCL < 0x10?<br/>(R30 < 78 mV)"}
    first_pulse{"Was this the<br/>first pulse?"}
    open_circuit(["F20 — open circuit<br/>(transformer wrong,<br/>FET missing, bad solder)"])
    next_channel{"Was this<br/>channel A?"}
    advance_b["Switch to channel B<br/>Reset DAC, counter"]
    pass(["Both channels passed —<br/>continue boot"])
    counter{"Attempted<br/>64 times?"}
    runaway(["F20 — runaway/imbalance<br/>(MOSFET Vt mismatch,<br/>wrong R35/R46, leaky FET)"])
    decrement["DAC -= 16 mV<br/>counter += 1"]

    start --> pulse
    pulse --> wait_adc
    wait_adc --> threshold
    threshold -->|yes — quiet| first_pulse
    threshold -->|no — too much current| counter
    first_pulse -->|yes — too low immediately| open_circuit
    first_pulse -->|no — settled| next_channel
    next_channel -->|yes| advance_b
    next_channel -->|no| pass
    advance_b --> pulse
    counter -->|yes| runaway
    counter -->|no| decrement
    decrement --> pulse

    classDef start_stop fill:#dcfce7,stroke:#16a34a,stroke-width:2px,color:#14532d
    classDef action fill:#dbeafe,stroke:#2563eb,stroke-width:2px,color:#1e3a5f
    classDef decision fill:#fef9c3,stroke:#ca8a04,stroke-width:2px,color:#713f12
    classDef fail fill:#fee2e2,stroke:#dc2626,stroke-width:2px,color:#7f1d1d

    class start,pass start_stop
    class pulse,wait_adc,advance_b,decrement action
    class threshold,first_pulse,next_channel,counter decision
    class open_circuit,runaway fail
```

A working unit settles around step 42 of 64 — that's ~22 steps of headroom (~484 mV at the Q3 gate). Vt drift in Q3 eats this headroom; see [MOSFET matching procedure](#mosfet-matching-procedure) below for the math.

## Disassembly evidence

```
1406:  ; init counters
140c:  ldi  r16, 0           ; channel-select flag: 0=A, 1=B
1410:  ldi  r26, 100         ; DAC seed = 100 (≈OUTA 4.38 V)
143a:  cp   r16, 0
143c:  brne 0x1444           ; channel B branch
143e:  ldi  r26, 0x0c        ; PORTB = 0b00001100 (PB2+PB3 = q5+q6)
1440:  out  PORTB, r26       ; ← drives channel A FETs
1444:  ldi  r26, 0x03        ; PORTB = 0b00000011 (PB0+PB1 = q7+q8)
1446:  out  PORTB, r26       ; ← drives channel B FETs
1448-1452:                   ; pulse-width delay
1456:  out  PORTB, 0         ; gates OFF
1458-145c:                   ; wait for ADC, read ADCL
1460:  cpi  r26, 0x10        ; ADCL < 16 ? (≈61 mV)
1462:  brcc 0x1476           ;   yes → settled, advance
1464:  inc  r27              ; pulse counter
1466:  cpi  r27, 0x40        ; 64 attempts ?
1468:  brcc 0x1492           ; ← 64 attempts exhausted → F20
146a-1474:                   ; decrement DAC, loop back
1476:  cmp  r27, 0
1478:  breq 0x1492           ; ← first pulse already too LOW = open → F20
...                          ; advance to channel B (r16=1) and repeat
1492:  ldi  r26, 0x14        ; ← loads code 20
1494:  rjmp 0x1676           ; ← FAILURE 20
```

Two distinct ways to trip F20:

- **(a)** First pulse already reads ADCL < 16 — meaning no current is flowing
  through R30 even at the high-power DAC seed. This points at an **open
  circuit** in the output stage (transformer wired wrong, FET missing,
  broken solder joint).
- **(b)** 64 successive pulses fail to bring ADCL below the threshold — the
  firmware can never get the channel quiet. This points at a **runaway /
  imbalanced** output (mismatched MOSFET Vt, leaky FET, wrong R35/R46 value).

## Likely cause

**Most common (in this order):**

1. **MOSFET Vt mismatch** — IRL520 quartet or IRF9Z24 pair with > ~50 mV
   spread in gate threshold voltage. The output stage can't keep R32 and R43
   balanced.
2. **Transformer reversed** — primary wired backward, current direction wrong.
3. **R35/R46 wrong value** — should be 200 kΩ. A 20 kΩ or 2 MΩ here throws
   off the gate bias.
4. **FET orientation** — IRL520 / IRF9Z24 placed backwards.
5. **DAC fault** — LTC1661 not communicating, or one of its outputs stuck.
   Last resort.

## Diagnostic procedure

1. **Measure DC voltage across R32 and across R43** with the box powered on,
   no patient cables connected. Both should read between **4.0 V and 4.4 V**
   and be very close to each other (within ~50 mV).
2. If R32 ≠ R43: **MOSFET mismatch**. Desolder the IRL520 quartet, measure
   Vt of each on a component tester, replace with a matched set (target
   spread < 20 mV).
3. If R32 = R43 but both out of range (e.g. both 1 V or both 5 V): check
   transformer orientation, R35 and R46 values, FET orientations.
4. **Before soldering on a fresh build**: pre-match every IRL520 / IRF9Z24
   with a component tester. A ~$15 Mega328-based tester from Amazon
   (B0DDBPWYP8) will save you hours of debugging.

## MOSFET matching procedure

### Calibration math (from the disassembly above)

The firmware ramps the DAC from `r26=100` (4.38 V) downward in ~16 mV steps,
up to 64 attempts, looking for ADCL < 16 (~78 mV across R30). Forum data
(Sirius #48, mer #45 in `Another Failure 20…`) shows a working unit settles
at **step 42 with the DAC at ~3.6 V** — leaving **~22 steps of calibration
headroom**. Translated to Q3 gate voltage (op-amp gain ~1.4×), one DAC step
is ~22 mV at the gate, so the ramp covers a ~1.4 V window of Q3 Vgs(th).

Vt outside that window — or so far from the working baseline that it eats
all the headroom — trips F20.

### Target Vt and matching tolerance

| Part | Position(s) | Target Vt | Per-group spread (ideal / acceptable) | Why |
| --- | --- | --- | --- | --- |
| **IRL520N** | Q1, Q2 (channel A) and Q5, Q6 (channel B) | 1.6–2.0 V (typ ~1.8 V) | ≤ 20 mV / ≤ 50 mV within each pair | Switches, not in calibration loop. Vt asymmetry = pulse asymmetry → electromigration on metal electrodes (Lilly's wave is broken). |
| **IRF9Z24N** (Infineon) | Q3, Q4 | 2.5–3.1 V (target ~2.98 V — bumerang's working baseline) | ≤ 50 mV / ≤ 100 mV within the Q3/Q4 pair | In the calibration servo. Each 22 mV of Vt offset eats one calibration step. Vt > 3.3 V leaves only ~8 steps headroom — marginal. |

### Why the IRL tolerance is tighter than the IRF tolerance

Counterintuitive at first — you'd expect the FET *inside* the calibration servo to need
tighter matching than the FETs outside it. The opposite is true here, and the reason
comes down to what each mismatch actually affects.

#### IRL520N — bounded by output-pulse symmetry

The MK-312 produces **biphasic pulses** by design: Q1 and Q2 alternate switching the
transformer primary in opposite directions, producing equal-and-opposite positive and
negative pulses on the secondary. Identical Vt across the pair → symmetric pulses.

If Vt(Q1) ≠ Vt(Q2), both FETs receive the same 5 V gate drive but conduct slightly
different currents (lower-Vt FET has more `Vgs − Vt` overdrive → lower Rds(on) →
conducts more current per pulse). The positive half of the bipolar pulse ends up with
a slightly different peak than the negative half. There's no firmware compensation —
Q1 and Q2 are pure switches.

**~20–30 mV is fine.** More mismatch isn't going to injure anyone — output currents
and average DC offsets at typical use stay well below medical-device DC thresholds
even at 100+ mV mismatch. What you'd actually notice with looser matching is
**asymmetric sensation** — one direction of the pulse feeling different from the
other, which most users find less pleasant or less effective.

Rough scale of what mismatch translates to:

| Vt mismatch | Current-per-pulse imbalance | Practical effect |
| --- | --- | --- |
| ≤ 20 mV | ~0.7% | Symmetric, indistinguishable from a perfectly-matched pair |
| 30–50 mV | ~1–1.7% | Still symmetric in feel for most users |
| 100 mV | ~3.5% | Edge of perceptibility — sensitive users may notice subtle channel asymmetry |
| 200 mV+ | ~7%+ | Asymmetric feel becomes obvious; long-term electrode wear accelerates |

So **≤ 20 mV ideal, ≤ 50 mV acceptable** is a comfort-and-symmetry target, not a
safety target. Below ~20 mV the asymmetry from Vt mismatch is in the noise floor of
the rest of the circuit (transformer winding tolerance, PCB trace differences,
Rds(on) production variance) — tighter doesn't measurably help.

#### IRF9Z24N — bounded by F20 calibration headroom

Q3 and Q6 are tested **independently** by the firmware (channel A's calibration ramp
runs on Q3, channel B's on Q6). They're never in a comparison loop with each other,
so Q3↔Q6 mismatch has no direct effect on F20 outcome.

What does matter: each one's **absolute Vt** must fit inside the firmware's 64-step
DAC ramp window. Lower absolute Vt = more steps of headroom for any other component
drift to push you toward F20 without crossing the threshold.

So the rule reverses:

- Absolute Vt cluster: **2.85–3.05 V** (within ±50 mV of bumerang's 2.98 V working
  reference) — this is the constraint that matters.
- Pair match-tightness: looser (≤ 50 mV ideal, ≤ 100 mV acceptable) because the
  firmware compensates each channel independently.

Matching Q3 to Q6 within ~50 mV gives symmetric feel between channels, but it's a
UX consideration, not an F20 one.

### IRF9Z24 manufacturer trap (high-yield F20 root cause)

Forum-confirmed (bumerang #10, #14 in `Another Failure 20…`, plus Gary #18,
LynxTail #49):

- **IRF9Z24NPBF (Infineon)** — Vt ~2.98 V, **WORKS**.
- **IRF9Z24PBF (Vishay)** — Vt ~3.58 V, **FAILS F20**.
- Counterfeit Chinese IRF9Z24N (smaller die, off characteristics) — also fails.

Always verify the **N** suffix and prefer Infineon. Check the IR/Infineon
logo and font on the package (Gary #15-17 documented counterfeit visual
tells).

### Sort-and-pair procedure for the IRL520N quartet

1. Test Vt on every IRL520N you have using a component tester.
   Mega328-based testers (e.g. ASIN **B0DDBPWYP8**) display 1 decimal —
   useful for absolute-Vt sanity but **not** for matching.
   LCR-P1 / DSC-TC4-style testers give 2 decimals (mV resolution) but have
   ~30–100 mV run-to-run noise from gate-charge memory and probe contact.
   To stabilize: short S↔G between tests to drain residual gate charge,
   handle FETs by the tab only, and take 5 readings per FET (median).
2. Sort the readings ascending: `Vt₁ ≤ Vt₂ ≤ Vt₃ ≤ Vt₄`.
3. Pair adjacent values:
   - **Channel A: Q1 + Q2 ← Vt₁ + Vt₂**
   - **Channel B: Q5 + Q6 ← Vt₃ + Vt₄**
4. Within each pair, position assignment doesn't matter — Q1 and Q2
   alternate switching, same for Q5 and Q6.

This minimizes intra-channel Vt spread (which matters for pulse symmetry).
The small inter-channel offset (Vt₂ vs Vt₃) doesn't affect F20 because the
firmware tests channels independently.

### Sort-and-pair procedure for the IRF9Z24N pair

1. Test Vt on every IRF9Z24N. Reject any with Vt > 3.3 V (eats too much
   calibration headroom — see math above).
2. Pick a pair from the same Vt cluster, matched within 50 mV ideal /
   100 mV acceptable.
3. Don't mix low-Vt (e.g. ~3.0 V) with high-Vt (e.g. ~3.2 V) on the same
   board — channel asymmetry compounds with calibration drift.

### Worked example

Given an IRL520N quartet sorted as `1.91, 1.92, 1.92, 1.93` (20 mV total
spread):

- Channel A (Q1, Q2): **1.91, 1.92**
- Channel B (Q5, Q6): **1.92, 1.93**

Both pairs at 10 mV intra-pair spread. Average inter-channel offset 10 mV.
Well within tolerance.

## Fix

Match MOSFETs by Vt before soldering using the procedure above. If already
built and F20 trips, the R32 vs R43 DC voltage difference is the smoking
gun — believe the multimeter, not your soldering pride. Desolder the
mismatched channel's quartet and IRF9Z24, retest Vt, swap in a matched set.

Build-guide section `build-guide.md` → "Error 20" covers prevention.
Background reading: forum threads in
`3-build-and-flash/troubleshooting/MK-312BT Failure 20 - Estim - Metafetish.pdf` and
`3-build-and-flash/troubleshooting/Another Failure 20 with measurements and some test mode_ - Estim - Metafetish.pdf`.

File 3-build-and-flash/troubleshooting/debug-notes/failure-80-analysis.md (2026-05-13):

# Failure 80 — EEPROM/config readback out of range

| Field | Value |
| --- | --- |
| Code (decimal) | **80** |
| Branch site | `0x0796` (`rjmp .+3806` → `0x1676`) |
| Test type | EEPROM-stored config byte range check |
| When it runs | During mode load / setting recall paths |
| Class | EEPROM contents — software fix (reflash EEPROM) |

## Summary

F80 fires on a value-range check that follows an EEPROM read. The check at
`0x0790` compares an indexed value (in `r30`) to 40 (0x28); if `r30` ≥ 40 the
firmware trips F80. The preceding code path includes `call 0x19dc`, which is
the EEPROM-read primitive (it polls EECR at I/O 0x1c). So F80 indicates a
stored configuration byte (a mode index, calibration value, or saved-state
pointer) that exceeds its valid range. Most often this means a corrupt EEPROM
— first-boot of a freshly-flashed chip with no EEPROM init, or wear /
corruption on a long-running unit.

## Disassembly evidence

```
19dc:  ; EEPROM read primitive
19de:  in   r28, 0x1c        ; EECR
19e0:  andi r28, 0x03        ; check EERE/EEWE busy bits
19e2:  brne 0x19de           ; spin until idle
19e4:  out  0x1f, r27        ; EEAR high
19e6:  out  0x1e, r26        ; EEAR low
19e8:  sbi  0x1c, 0          ; EERE = 1 → start read
19ec:  in   r0, 0x1d         ; EEDR → r0
19f0:  ret
...
0756:  call 0x19dc           ; ← EEPROM read
075a:  mov  r26, r0          ; result into r26
075c:  rcall 0x0b98          ; (use the value)
...
0790:  cpi  r30, 0x28        ; ≥ 40 ?
0792:  brcs 0x0798           ;   no → continue
0794:  ldi  r26, 0x50        ; ← loads code 80
0796:  rjmp 0x1676           ; ← FAILURE 80
```

Combined with the EEPROM read above the check, F80 is a sanity guard on a
stored byte that should be a small index (0..39). The firmware likely stores
the current/saved mode here, or a slot index into a table.

## Likely cause

1. **First boot of fresh chip.** Virgin AVR EEPROM is all 0xFF (= 255), so
   any read of an uninitialized slot returns 255, which is far above 40 → F80.
2. **EEPROM corruption** over time — power loss during write, lightning, ESD.
3. **Bus error during EEPROM read** — extremely rare; only if the AVR's Vcc
   is glitching.

## Diagnostic procedure

1. **First boot of a freshly-flashed chip**: the box may need an initial
   EEPROM image. Either flash the bundled `backup_eeprom.bin` from this repo
   (`avrdude … -U eeprom:w:backup_eeprom.bin`), or run the firmware's normal
   first-boot init (some f005 builds initialize EEPROM if they detect 0xFF;
   others don't).
2. **Long-running unit suddenly throwing F80**: dump current EEPROM
   (`-U eeprom:r:current_eeprom.bin:r`) and compare to known-good
   `backup_eeprom.bin`. Differences in the first ~64 bytes confirm corruption.
3. Reflash known-good EEPROM and reboot.

## Fix

Reflash `backup_eeprom.bin`. F80 is virtually always EEPROM contents, not
hardware — don't go probing the board before you've tried the EEPROM reset.

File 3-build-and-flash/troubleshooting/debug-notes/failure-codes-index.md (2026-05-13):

# MK-312BT firmware failure codes — complete index

| Code | Branch | Meaning | Class | Most likely cause |
| ---: | --- | --- | --- | --- |
| **10** | `0x0bba` | DAC write value ≥ 224 | Firmware/state | EEPROM corruption or pot/ribbon glitch |
| **15** | `0x1396`, `0x13c4` | Divide-by-zero | Firmware bug | Custom patch or RAM glitch (rare) |
| **16** | `0x15fa` | Output-level mapping won't converge | Hardware (pots) | Front-panel ribbon, noisy pot, AVCC ripple |
| **20** | `0x1494` | Output stage current sense fails (A or B) | Hardware | MOSFET Vt mismatch, transformer rev'd, R35/R46 wrong |
| **21** | `0x16e4` | Wall adapter ≥ ~17.1 V | Power | 18 V / 19 V supply over-spec, or ADC reference / ribbon |
| **72** | `0x1a1e` | State counter RAM[0x01F1] ≥ 56 | Firmware/state | Custom patch bug or EEPROM corruption |
| **80** | `0x0796` | EEPROM config byte ≥ 40 | EEPROM | First boot of fresh chip; reflash EEPROM |

## Where to start

Each code has its own `failure-NN-analysis.md` in this directory with
disassembly evidence, likely causes, and a diagnostic procedure.

**Order of frequency on a fresh build**: F20 (output stage), F21 (supply
voltage), F80 (EEPROM init). F10/F15/F16/F72 are rare in the wild and
usually point at firmware patches or worn-out hardware on long-running units.

## Caveat: dynamic dispatcher at 0x3ea

There's also one branch at `0x3ea` that does `jmp 0x1676` with a _dynamic_
code — it loads `r26` from `Y+34` and jumps if that value ≥ 4. So in
principle the firmware can display Failure codes 4, 5, 6, 7, … if some
other code path stores those values into `Y+34`. None of the literal
`ldi r26` sites elsewhere in the firmware load values in the 4–9 range, so
the practical list of codes a stock f005 build will ever actually display is
the seven above.

## Method

Disassembly: `avr-objdump -m avr5 -D --target=binary backup_flash.bin`. The
error_handler entry was identified by tracing the string `"Failure "` in
flash and finding the routine that consumes `r26` as a number to print.
Every `(rjmp|jmp) 0x1676` reference was followed back to the
immediately-preceding `ldi r26, 0xNN` instruction. Cross-checked against
`f005.bin` (the canonical firmware file) — identical bytes at all 9 sites.

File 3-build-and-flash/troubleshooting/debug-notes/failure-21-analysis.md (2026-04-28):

# Failure 21 — firmware, circuit, and intermittent-boot analysis

This is an evidence-based engineering report for the v1.4 board running patched
buttshock-et312-frankenbutt **f005** firmware. Every non-trivial claim cites
its source. Where I could not confirm something through the disassembly,
schematic, datasheet, or an authored third-party source, I say so explicitly.

The most important finding up front: **Failure 21 in this firmware is NOT a
"channel B mirror of Failure 20". F21 is a power-supply / wall-adapter
voltage check that runs once at boot. The forum lore that pairs F20/F21 as
A-vs-B output tests is wrong.** F20 already tests both channels in a single
routine (it loops twice, once with `r16=0` for channel A drive, once with
`r16=1` for channel B drive — see §1.2).

---

## 1. What "Failure 21" means in firmware

### 1.1 String location and the error_handler

`Failure ` is stored as an 8-byte field at flash offset `0x1DF0` (verified by
`xxd backup_flash.bin`):

```
00001df0: 4661 696c 7572 6520 5077 7220 4c65 763a  Failure Pwr Lev:
```

The string is loaded by the **error_handler** at `0x1676`. From
`avr-objdump -m avr5 -b binary -D backup_flash.bin`:

```
1676:  2a 2f       mov   r18, r26       ; r26 = failure code from caller
1678:  a4 e6       ldi   r26, 0x64      ; 100 -- string index "Failure"
167a:  38 de       rcall .-912    ;  0x12ec  ; show_Text_on_Display
167c:  ab ec       ldi   r26, 0xCB      ; 203 -- string index "Shut Off Power"
167e:  36 de       rcall .-916    ;  0x12ec
1680:  f8 e0       ldi   r31, 0x08      ; LCD position
1682:  e2 2f       mov   r30, r18       ; failure number
1684:  19 de       rcall .-974    ;  0x12b8  ; display_number_on_display
1686:  a0 e0       ldi   r26, 0x00
1688:  29 de       rcall .-942    ;  0x12dc
168a:  f8 94       cli
168c-16b6:                                  ; force outputs safe + idle loop
```

This routine is annotated `error_handler` in the buttshock annotated
disassembly file
`/tmp/buttshock-fw/annotation/312-16-decrypted-combined.tags`:

> `0x1676  L  error_handler  CallTable_23_37_38_39`
> `0x167a  T  display "Failure", spaces, failure num`
> `0x1688  T  display "Shut off power"`

### 1.2 All four call sites that load a failure code

I searched the disassembly for every `ldi r26, 0x14` (=20) and `ldi r26, 0x15`
(=21):

```
0x072e:  ldi r26, 0x14   ; rcall 0xb98          ← runtime, NOT error_handler
0x0736:  ldi r26, 0x15   ; rcall 0xb98          ← runtime, NOT error_handler
0x1492:  ldi r26, 0x14   ; rjmp  0x1676 (F20)   ← BOOT self-test
0x16e2:  ldi r26, 0x15   ; rjmp  0x1676 (F21)   ← BOOT self-test
```

The `0xb98` callee is the SPI-DAC write path; `0x14`/`0x15` there are DAC
levels, not failure codes. Only `0x1492` and `0x16e2` actually trigger the
error handler. So the firmware emits exactly **two** boot failure codes:
F20 from `0x1492` and F21 from `0x16e2`.

#### Failure 20 (`0x1492`) — both channels through R30

The F20 test is the loop at `0x1406-0x1494`. Pseudocode (from the buttshock
annotated dump, identical bytes to our `backup_flash.bin`):

```
Function_0x1406:
1406:  ldi r26, 0xff
1408:  mov r6, r26
140a:  mov r11, r26
140c:  ldi r16, 0       ; channel-select flag: 0=A, 1=B
140e:  ldi r27, 0       ; pulse counter
1410:  ldi r26, 100
1412:  std Y+4, r26     ; DAC initial = 100  (this is the OUTA=4.38V seed)
1414:  std Y+5, r26     ; DAC initial = 100

Label_0x1416:
1416:  rcall 0x15b8     ; setup_0x205_x206_based_on_pot_and_ramp_and_levels
1418:  rcall 0x1456     ; send_data_to_spdr  (DAC update)
141a-1430: ADMUX/ADCSR setup, three sleeps (for ADC settle)

Label_0x1432:
1432:  rcall 0x15b8     ; refresh DAC value
1434:  rcall 0x1456
1438:  sleep 3
143a:  cmp r16, 0
143c:  brne Label_0x1444
143e:  ldi r26, 0x0c    ; PORTB = 0b00001100 ; q5=PB2=1, q6=PB3=1, q7=PB0=0, q8=PB1=0
1440:  out PORTB, r26                          ; ← drives channel A only (Q1+Q2 open)
1442:  rjmp Label_0x1448

Label_0x1444:
1444:  ldi r26, 0x03    ; PORTB = 0b00000011 ; q5=PB2=0, q6=PB3=0, q7=PB0=1, q8=PB1=1
1446:  out PORTB, r26                          ; ← drives channel B only (Q4+Q5 open)

Label_0x1448:
1448:  ldi r26, 2 ; sleep 2          ; pulse width
144c:  out ADCSR, 0xC6                ; start single ADC conversion
1452:  short delay loop
1456:  out PORTB, 0                   ; gates OFF
1458:  loop until ADIF set
145c:  in r26, ADCL
145e:  in r31, ADCH
1460:  cpi r26, 0x10                  ; ADCL < 16 ? (i.e. ADC < ~313 mV ref-AVCC, ≈61 mV unscaled)
1462:  brcc Label_0x1476              ; PASS -> exit & advance to next channel or finish
1464:  inc r27                        ; pulse counter
1466:  cpi r27, 0x40                  ; 64 attempts?
1468:  brcc 0x1492                    ; → F20  ("never settled in 64 attempts")
146a-1474:                            ; decrement DAC, save, loop back to 0x1432
1476:  cmp r27, 0
1478:  breq 0x1492                    ; first pulse already too LOW = open circuit → F20
... continues into channel-B half ...

0x1492:  ldi r26, 0x14 ; rjmp 0x1676  ; ← FAILURE 20
```

**Conclusion on F20:** A single routine drives PB2+PB3 for channel A, then
PB0+PB1 for channel B (the `r16` flag), and on each pass it reads ADC0
(PA0 = R30 sense). The pass criterion: starting from a low-power DAC value,
each successive pulse must produce a measurable but bounded current through
R30, settling within 64 iterations.

### 1.3 Failure 21 (`0x16e2`) — boot voltage check

The F21 test is **completely separate** from the F20 channel test. It is
a small routine at `0x16b8` called once from RESET at `0x151a`:

```
0x151a:  rcall 0x16b8   ; (boot self-test -- voltage sense)
```

Disassembly of `0x16b8` (raw bytes match our `backup_flash.bin`):

```
Function_0x16b8:                ; Y points at 0x4060
16b8:  ldi r26, 0x56            ; seed
16ba:  std Y+2, r26             ; pre-seed mem[0x4062]  (ADC2 storage slot)
16bc:  ldi r26, 0x85            ; seed
16be:  std Y+3, r26             ; pre-seed mem[0x4063]  (ADC3 storage slot)
16c0:  rcall 0x0b1e             ; enable_ADC_and_set_r17[3]
16c2:  sbrc r17,3 / rjmp .-4    ; wait for ISR to clear "ADC running"
16c6:  rcall 0x0b1e             ; (auto-cycled ADMUX, see §1.4)
16c8:  sbrc r17,3 / rjmp .-4
16cc:  rcall 0x0b1e
16ce:  sbrc r17,3 / rjmp .-4
16d2:  ldd r26, Y+3             ; read averaged ADC3 result (battery rail sense)
16d4:  cpi r26, 0x8E            ; 142
16d6:  brcc Label_0x16dc        ; if ADC3 ≥ 142 → continue
16d8:  jmp 0x590                ; otherwise: display_battery_low
16dc:  ldd r27, Y+2             ; read averaged ADC2 result (wall-adapter sense)
16de:  cpi r27, 0x92            ; 146
16e0:  brcs Label_0x16e6        ; if ADC2 < 146 → continue
16e2:  ldi r26, 0x15            ; ← FAILURE 21
16e4:  rjmp 0x1676              ; → error_handler
```

After the F21 check passes, `0x16e6-0x16fc` derives a `power_status_bits`
bitmap into mem[0x0215]:

- bit 0 set if ADC3 < `0xB2` (178) → "we have a battery"
- bit 1 set if ADC2 ≥ `0x40` (64)  → "PSU/charger is connected"
- if ADC2 ≥ `0x63` (99) but the check at `0x16de` passed (< 146) the firmware
  also computes a battery-level percentage at `0x171a` from the ADC2/ADC3
  pair, then proceeds to `Function_0x1406` (the F20 channel test).

**So at boot the firmware runs F21 first (voltage sanity), then F20 (output
stage sanity). F21 trips ONLY if the wall-adapter sense reads too high.**

### 1.4 Why two ADC results from the same `enable_ADC_and_set_r17[3]` call

`0x0b1e` always writes `ADMUX = 0x01` (REFS=00 AVCC, MUX=00001 → ADC1):

```
0b1e:  ldi r26, 0x01 ; out ADMUX, r26
0b22:  ldi r26, 0xCB ; out ADCSR, r26   ; ADEN|ADSC|ADIE, /8
0b26:  ori r17, 0x08                    ; flag "ADC running"
```

The ADC ISR (`ADC_Conversion_Complete`, `0x106e`) however does an
**ADMUX increment after each conversion**:

```
106e:  ...
1072:  in r28, ADMUX                   ; r28 = current MUX
1074:  subi r28, 0xA0                  ; r28 = MUX + 0x60 = SRAM ptr low byte
1076:  in r24, ADCL ; r25 = ADCH ; right-shift 4 → 8-bit result in r24
1082-108e: read prior value at SRAM[Y], average with r24, store
10ca:  in r23, ADMUX
10cc:  inc r23
10ce:  sbrs r23, 3                     ; if MUX would advance to 8 → done
10d0:  rjmp Label_0x10de
10d2:  out ADMUX, r23                  ; otherwise: advance to next channel
10d4:  ldi r23, 0xCC ; out ADCSR, r23  ; and start new conversion
```

So a single call to `0x0b1e` **starts** one conversion on ADC1, and the ISR
**auto-chains** ADC2, ADC3, ... through ADC7 by rewriting ADMUX between
conversions. Results land at SRAM `0x4060 + channel_index`. Y in
`Function_0x16b8` is set up so that `Y+2 = 0x4062` (ADC2 result) and
`Y+3 = 0x4063` (ADC3 result), matching the buttshock annotation:

> `0x1766  T  display 0x4063 (Battery Voltage ADC3)`

The three explicit `rcall 0x0b1e` in `0x16b8` give the ISR enough chained
conversions for the auto-cycled values at offsets 2 and 3 to settle
(seeded with 0x56 and 0x85 to give the ISR's averager a defined starting
point).

### 1.5 Numeric thresholds vs. the v1.4 schematic

Page 2 of the v1.4 schematic shows two voltage dividers feeding PA2 (ADC2)
and PA3 (ADC3). Both are tied to the AREF/AVCC reference (5.0 V).

The annotation file calls **ADC3 = "Battery Voltage"** and the F21 thresholds
make sense ONLY with the schematic-actual divider ratios. Working backwards:

| ADC | Pin | Divider (page 2) | Net at top of divider | 8-bit ADC reading at threshold |
|-----|-----|---|---|---|
| 2 | PA2 | R3 100kΩ / R4 20kΩ to GND | "U+" (wall-adapter, pre-LM2941T) | F21 trips at ADC2 ≥ **0x92 (146)** → 2.85 V at PA2 → **U+ ≥ ~17.1 V** |
| 3 | PA3 | R5 10kΩ / R6 3.3kΩ to GND | "+12V" rail (battery side, post-D1) | "battery low" at ADC3 < **0x8E (142)** → 2.77 V at PA3 → **+12V rail < ~11.2 V** |

(D5 1N4148 sits cathode-to-PA2 to clamp surges from U+; this does not affect
the divider ratio in normal operation.)

These thresholds match the third-party debug write-up from `hvprvbo`
(see §5).

### 1.6 The pre-test PORTB/PORTD setup at 0x14e0-0x14ee

Before either failure routine runs the firmware sets up I/O. From
`0x14d4-0x14ee` of `backup_flash.bin`:

```
14d8:  ldi r26, 0xBF ; out 0x17, r26    ; DDRB  = 1011 1111  (PB6 = MISO input)
14dc:  ldi r26, 0xFF ; out 0x14, r26    ; DDRC  = 1111 1111  (LCD bus, all out)
14e0:  ldi r26, 0xF2 ; out 0x11, r26    ; DDRD  = 1111 0010  (PD7..4,PD1 out; PD3,PD2,PD0 in)
14e4:  ldi r26, 0x70 ; out 0x12, r26    ; PORTD = 0111 0000  (PD6,5,4 high)
14e8:  ldi r26, 0x10 ; out 0x18, r26    ; PORTB = 0001 0000  (PB4 = DAC CS high; gates OFF)
14ec:  ldi r26, 0x80 ; out 0x08, r26    ; TCCR0 setup
```

So the F20 channel test fires from a known-clean state with all FET-driver
gates OFF (PORTB = 0x10 → only PB4 high, used as DAC chip-select).

There is **no explicit pre-test stim pulse before the ADC reads in F21**.
The "pulse loop" at `0x16a2-0x16b6` is the *post-failure* watchdog-keepalive
loop reached only via `error_handler`'s rjmp at `0x16b6 → 0x16a2`, not the
pre-test pulse generator. F21 reads ADC2/ADC3 with the outputs OFF.

---

## 2. Channel B circuit reference (v1.4 schematic page 5)

Page 4 of the schematic is **audio I/O + serial/radio interface**, NOT the
output stages. The output power section is on **page 5**. Below is the full
channel B inventory together with channel A as a reference.

### 2.1 Output drive — channel A (page 5, top half, transformer TR3)

| Designator | Value / Part | Function |
|---|---|---|
| Q1 | IRL520N N-MOSFET | Low-side gate, driven by **PB2** via R38 |
| Q2 | IRL520N N-MOSFET | Low-side gate, driven by **PB3** via R41 |
| Q3 | IRF9224 P-MOSFET | High-side, gate driven by U10A op-amp output via R39 |
| U10A | LM358N op-amp | Linear regulator for Q3 gate (sets channel A power level) |
| TR3 | 42TU200 transformer | Pulse step-up to OUTPUT A jack J6 |
| R30 | 0.27 Ω (build) / 0.5 Ω (BOM) | **Channel A current sense** to GND. Top of R30 → PA0/ADC0 |
| R31 | 100 kΩ | DAC OUT-A → U10A (+) input |
| R32 | 100 kΩ | U10A (+) input → +5V (sets DAC offset) |
| R33 | 100 kΩ | U10A (+) input → GND |
| R34 | 100 kΩ | U10A (-) input → +9V1 |
| R35 | 200 kΩ | U10A (-) input → GND |
| R36 | 100 kΩ | U10A feedback |
| R37 | 100 kΩ | Q1 gate pull-down |
| R38 | 10 kΩ | PB2 → Q1 gate series |
| R39 | 10 kΩ | U10A output → Q3 gate |
| R40 | 100 kΩ | Q2 gate pull-down |
| R41 | 10 kΩ | PB3 → Q2 gate series |
| C38 | 0.1 µF | U10A bypass |
| C39 | 0.1 µF | Q3 gate decoupling |

### 2.2 Output drive — channel B (page 5, bottom half, transformer TR4)

| Designator | Value / Part | Function |
|---|---|---|
| Q4 | IRL520N N-MOSFET | Low-side gate, driven by **PB0** via R49 |
| Q5 | IRL520N N-MOSFET | Low-side gate, driven by **PB1** via R52 |
| Q6 | IRF9224 P-MOSFET | High-side, gate driven by U10B op-amp output via R50 |
| U10B | LM358N op-amp | Mirror of U10A — sets channel B power level |
| TR4 | 42TU200 transformer | Pulse step-up to OUTPUT B jack J7 |
| R42 | 100 kΩ | DAC OUT-B → U10B (+) input |
| R43 | 100 kΩ | U10B (+) input → +5V (mirror of R32) |
| R44 | 100 kΩ | U10B (+) input → GND (mirror of R33) |
| R45 | 100 kΩ | U10B (-) input → +9V2 (mirror of R34) |
| R46 | 200 kΩ | U10B (-) input → GND (mirror of R35) |
| R47 | 100 kΩ | U10B feedback (mirror of R36) |
| R48 | 100 kΩ | Q4 gate pull-down (mirror of R37) |
| R49 | 10 kΩ | PB0 → Q4 gate series (mirror of R38) |
| R50 | 10 kΩ | U10B output → Q6 gate (mirror of R39) |
| R51 | 100 kΩ | Q5 gate pull-down (mirror of R40) |
| R52 | 10 kΩ | PB1 → Q5 gate series (mirror of R41) |
| C40 | 0.1 µF | Q6 gate decoupling (mirror of C39) |

### 2.3 DAC for both channels

| Designator | Value / Part | Function |
|---|---|---|
| U8 | LTC1661 dual 10-bit DAC | One DAC drives U10A, the other drives U10B. SPI on PB5 (MOSI), PB7 (SCK), CS via PD4 (per the LCD-init code's `cbi 0x12,4` and tag "pin D4 is DAC CS") |
| C41 | 0.1 µF | LTC1661 bypass |

### 2.4 Asymmetries and answer to "what is the channel B sense path?"

**There is no channel B current-sense resistor that is its own component.**
Channel B does not have its own equivalent of R30. Channel A's R30 (0.27 Ω
between PA0 and GND) is the only AVR-pin-connected current sense in the
output stages.

The wire that runs from R30 to GND also routes back to **both transformer
primary returns** on page 5 (the "common low side" between Q1/Q2 of channel A
and Q4/Q5 of channel B — both pairs of N-FET sources go to this same node).
That is what allows F20 to test channel B by gating PB0/PB1 and still
reading the resulting current via PA0/R30. F20's two-phase loop (`r16=0`
then `r16=1`) selects which channel's low-side FETs to open. Only one
channel's high-side P-FET (Q3 or Q6) is enabled at a time by setting the
DAC output for that channel; the other channel's DAC is at idle and
contributes essentially zero current to R30.

**Practical consequence for debug probing:** Channel B does NOT have an
independent ADC feedback. Probing PA0 during boot self-test will show
both channel A pulses (when r16=0) and channel B pulses (when r16=1) on
the same node.

---

## 3. ADC sense paths (page 2 of schematic)

The relevant analog-input nets visible on page 2:

| ADC | AVR pin | Path to AVR pin | Reads what |
|---|---|---|---|
| ADC0 | PA0 (pin 40) | Top of R30 (0.27Ω) → straight to PA0; also connected via the shared low-side return rail to Q1/Q2/Q4/Q5 sources | Current through whichever channel's low-side FETs are open |
| ADC1 | PA1 (pin 39) | Front-panel ribbon J11-5; on page 4 → C26 0.1µF + C25 1nF + R20 100kΩ to GND, into U2B (LM324) (+) input. U2B is fed from JP2 AUX LINE IN audio chain. | Audio multi-adjust input level (annotation: "Multi Adjust Offset ADC1") |
| **ADC2** | **PA2 (pin 38)** | **R3 100kΩ from "U+" (raw VDC INPUT, J8) → PA2 → R4 20kΩ to GND.** D5 1N4148 cathode at PA2 to GND (clamp). | **Wall-adapter input voltage. F21 threshold: ADC2 ≥ 146 → ~17.1V at U+ → F21** |
| **ADC3** | **PA3 (pin 37)** | **R5 10kΩ from "+12V" rail → PA3 → R6 3.3kΩ to GND.** | **+12V battery-side rail. Battery-low if ADC3 < 142 → ~11.2V → halt at 0x590** |
| ADC4 | PA4 (pin 36) | Front-panel ribbon J11-9 → VR1 LEVEL A pot wiper | Channel-A power knob |
| ADC5 | PA5 (pin 35) | Front-panel ribbon J11-11 → VR2 LEVEL B pot wiper | Channel-B power knob |
| ADC6 | PA6 (pin 34) | Front-panel ribbon → page 4 → D2 1N4148 + R29 100kΩ + C31 1µF (peak-hold) | Audio B half-wave |
| ADC7 | PA7 (pin 33) | Front-panel ribbon → page 4 → D3 1N4148 + R28 100kΩ + C30 1µF (peak-hold) | Audio A half-wave |

There is no ADC sense path dedicated to channel B output. The only feedback
the firmware has from the high-voltage side is via R30 + PA0.

---

## 4. Per-pin probe table for the boot voltage and stage tests

Voltages are measured with respect to board GND; "boot" means within ~50 ms
of releasing the POWER switch and before the LCD lights, on a v1.4 board
running f005.

| AVR pin | Function | Expected at boot (battery only, no charger) | Expected with 15V charger | If wrong, do this |
|---|---|---|---|---|
| **PA0 / ADC0 (pin 40)** | Channel A & B current sense (top of R30) | ~0 mV resting; brief pulses up to ~150 mV during F20 self-test | same | If stuck high (>200 mV with no pulse): Q1/Q2/Q4/Q5 stuck on, or R30 open. Read R30 with DMM (should be 0.27 Ω). |
| **PA1 / ADC1 (pin 39)** | Audio multi-adjust input | ~0 V (no audio); follows multi-adj knob through audio chain | same | If pinned high: ribbon flip / short to +5V on J11. |
| **PA2 / ADC2 (pin 38)** | Wall-adapter sense, divider R3/R4 from U+ | **~0 V** (U+ = 0V on battery only) | **U+ × 20/120 = 0.167 × U+** → 2.50 V at 15V, 2.83 V at 17V (≈F21 threshold) | F21 trip: measure U+ at J8 input. If U+ > 17V → reduce supply. If U+ ≈ 0V on battery and F21 still trips → AVR is reading garbage; suspect ADC reference (AVCC, AREF) or ribbon-induced fault. |
| **PA3 / ADC3 (pin 37)** | Battery rail sense, divider R5/R6 from +12V | **+12V × 3.3/13.3 = 0.248 × Vbat** → 2.97 V at 12.0V, 3.22 V at 13.0V | same (battery + charger float) | If reading < 2.77 V (= ADC < 142) box halts at 0x590 ("battery low"). Measure the +12V rail directly at the cathode of D1 — if rail is OK but PA3 is low: R5 open or R6 short. |
| PA4 / ADC4 (pin 36) | Channel-A LEVEL knob | follows VR1 wiper, 0..5V | same | knob wiring or J11-9 |
| PA5 / ADC5 (pin 35) | Channel-B LEVEL knob | follows VR2 wiper, 0..5V | same | knob wiring or J11-11 |
| PA6 / ADC6 (pin 34) | Audio B peak | 0V (no audio) | same | C31 leaky |
| PA7 / ADC7 (pin 33) | Audio A peak | 0V (no audio) | same | C30 leaky |
| AREF (pin 32) | ADC reference | tied to AVCC = +5V via the AREF cap C16 (18pF) on schematic? Actually AREF and AVCC both feed +5V externally via L1/ferrite. Check both pins read +5.00V ±0.05V. | same | Off by >0.1V → ADC results scaled wrong. Could mimic F21 if AVCC droops. |
| AVCC (pin 30) | ADC supply | +5.00 V | same | If sagging during boot inrush, ADC2/3 reads will be biased. **Check with scope, not DMM.** |
| PB0 / PB1 (pins 1 / 2) | Channel B low-side FET drives | quiet, then 4–6 µs pulses during F20 (r16=1 phase) | same | Stuck high: F20 trip on first pulse |
| PB2 / PB3 (pins 3 / 4) | Channel A low-side FET drives | quiet, then pulses during F20 (r16=0 phase) | same | Stuck high: F20 trip on first pulse |
| PB4 (pin 5) | LTC1661 DAC chip-select | high (idle), goes low only during DAC transfer | same | If stuck low → DAC permanently selected → spurious SPI transfers |
| PB5 / PB7 (pins 6 / 8) | DAC SPI MOSI / SCK | quiet bursts during SPI updates | same | Cross-talk from ribbon → SPI corruption |
| PC0..PC7 (pins 22-29) | LCD bus (4-bit data on PC7:4, RS=PC3, E=PC2, RW=PC1) | 4-bit nibbles + E strobes during init | same | See §6 — this is the LCD path |
| PD0 (pin 14) | RXD (link/serial RX) | high (idle) | same | |
| PD1 (pin 15) | TXD | high (idle) | same | |
| PD2 (pin 16) | INT0 (page 4 ref) | high or low depending on input | same | |
| PD3 (pin 17) | INT1 | similar | same | |
| PD4 (pin 18) | DAC CS via cbi 0x12,4 (annotation: "pin D4 is DAC CS") | high (idle) | same | conflict with PB4? See §6 — this is suspicious. |
| PD5 (pin 19) | OC1A / front-panel | mode-dependent | same | |
| PD6 (pin 20) | ICP / front-panel | mode-dependent | same | |
| PD7 (pin 21) | OC2 / front-panel | mode-dependent | same | |
| RESET (pin 9) | reset (10kΩ pull-up to +5V) | +5V | same | If pulled low at boot → infinite reset; LCD power cycles → can produce a "blocks on top row" stuck-init |
| XTAL1 / XTAL2 (pins 13 / 12) | 8 MHz crystal | sine ~3-5 V p-p | same | If crystal slow to start, boot watchdog may fire before LCD init completes |

---

## 5. Forum & blog quotes — what the community says about F21

The metafetish.club forum is offline (since ~2020-12). The Wayback Machine
returned no usable snapshots within the WebFetch timeout for the specific
F20/F21 thread URLs. However, **one third-party reverse-engineering write-up
remains live and is direct:**

### 5.1 hvprvbo (CrazyEstim) blog, 2021-03-29 — definitive third-party source

URL: https://hvprvbo.blogspot.com/2021/03/mk312-btfailure20-failure21-debug-for.html
PDF mirror: https://drive.google.com/file/d/1gr-n5ldNQqSA_JH1kqPSWMPF73wiGk7i/view?usp=sharing

Verbatim Chinese, with translation. The author built an MK-312-BT v1.2 and
hit F21 followed by F20:

> 1.Failure 21故障
>     故障原因是面板插口处的电源电压不对。MK312-BT的BOM中推荐电源电压15~19V。
>     MK312-BT有一个电源电压检测机制，如图 1所示。图中"V+"结点为前面板电源插
>     口正极。单片机启动时读取AD引脚PA2上的分压，数值不对就会报Failure 21故
>     障。调整电源电压即可解决。

Translation:

> **1. Failure 21**
>     The cause is that the power-supply voltage at the front-panel jack is
>     wrong. The MK-312-BT BOM recommends a 15–19 V supply. The MK-312-BT has
>     a power-supply voltage detection mechanism (figure 1). "V+" in the
>     figure is the front-panel power-jack positive terminal. At MCU
>     startup, the firmware reads the divided voltage on AD pin **PA2**,
>     and if the value is wrong it raises the Failure 21 fault. Adjusting
>     the supply voltage solves it.

For F20 the same article cites a forum user "Sirius" on metafetish.club:

> 根据(Sirius, https://metafetish.club )提供的信息(图 2)，单片机启动时需要分别
> 对A, B两个通道进行测试，每个通道必须满足两个条件：
>     设置OUTA=4.38V， 输出第1个脉冲，要求R30电位低于78.2mV(条件1)。
>     然后每次减小OUTA电位0.016V依次输出脉冲并测量R30电位，要求 在64次以内
>     R30电位高于78.2mV(条件2) 。对于B通道，重复上述过程。

Translation:

> Per Sirius (forum.metafetish.club, fig. 2), at MCU startup the firmware
> must test channels A and B separately, and each channel must satisfy two
> conditions:
>     Set OUTA = 4.38 V, output the first pulse, R30 voltage must be **below
>     78.2 mV (condition 1)**.
>     Then decrease OUTA by 0.016 V each pulse, output pulses and measure
>     R30, requiring R30 voltage to **rise above 78.2 mV within 64 pulses
>     (condition 2)**. Repeat for channel B.

The blog's F20 fix was to **add a 270 kΩ resistor in parallel with R32 and
with R43** (raising the U10A and U10B `+` input bias so Q3/Q6 are not
over-driven on the first pulse), which made `condition 1` pass on the first
attempt for both channels.

This blog post is the most authoritative public reference outside the dead
forum and lines up exactly with the disassembly above.

### 5.2 Wayback Machine search — what is and isn't there

I exhausted the WebFetch tool's timeout against
`https://web.archive.org/web/.../metafetish.club/t/...` for the threads at
`/t/another-failure-20-with-measurements-and-some-test-mode/629`,
`/t/mk-312bt-failure-20/419`,
`/t/mk312bt-firmware-and-function-issues-failure-20-debug-suggestions/1327`,
and `/t/mk312bt-failure-modes-20-and-21/357`. The pre-fetch hook killed every
attempt before content was returned.

Google search returns the metafetish thread titles (so they were indexed
once), but the live forum is offline and the Wayback snapshots either don't
render or aren't fetch-able from this environment. **I could not retrieve
any verbatim forum quotes about F21 from the Wayback Machine** — only the
hvprvbo blog above and the AI-summarised search-snippet wording:

> "**Failure 21** appears with mains power supply connected" and "Mode 21
> with mains power supply connected"

That summary fits the disassembly: F21 trips on a too-high adapter voltage,
which is only ever non-zero when the adapter is connected.

There is no public documentation of a "test mode" / diagnostic-mode bypass
for the F21 self-test in the firmware. The boot path runs unconditionally
from RESET → `0x151a: rcall 0x16b8`. A factory-reset hold-on-power
sequence does exist (annotation `0x1726: T look for key push 1100 (factory
reset up+down)` and `0x174e: loop display debug values until we get a
keypress 1010`), but that's reached **after** the F21 / F20 self-tests
finish, not before — so it cannot be used to bypass either failure.

---

## 6. ST7066U init-timing relevant to the NHD-0216K1Z-NSW-FBW-L

I read the official Newhaven datasheet (revision 6, 2019-03-01) at
https://newhavendisplay.com/content/specs/NHD-0216K1Z-NSW-FBW-L.pdf
(downloaded copy preserved at the WebFetch tool result PDF).

Key facts relevant to "blocks on top row" symptoms:

### 6.1 Module facts

- **Driver IC: ST7066U, 8/4-bit MPU interface.** HD44780 instruction-compatible.
- **Supply voltage: VDD = 5.0 V typ (4.8 V min, 5.2 V max).**
- **VLCD (contrast) = 4.4 V typ (4.3 min, 4.7 max) — note: this is +5V minus
  contrast pot wiper voltage, so V0 ≈ 0.5–0.7 V from GND.**
- 1/16 duty, 1/5 bias.
- Backlight: White LED, +5V via on-board resistor on LED+ pin (no series
  resistor needed externally — but the schematic adds R55 as additional
  current limit; user changed R55 from 47Ω to 100Ω, which is fine).

### 6.2 Bus timing (write) — far from anything the AVR could violate

| Parameter | Symbol | Min |
|---|---|---|
| Enable cycle | T_C | 1200 ns |
| Enable pulse width (E high) | T_PW | 140 ns |
| Address setup (RS, RW before E↑) | T_AS | 0 ns |
| Address hold (RS, RW after E↓) | T_AH | 10 ns |
| Data setup (DB before E↓) | T_DSW | 40 ns |
| Data hold (DB after E↓) | T_H | 10 ns |
| Enable rise/fall | T_R, T_F | 25 ns max |

At 8 MHz, one AVR cycle = 125 ns. The firmware E-pulse is `IO_BIT[PORTC,2]=true; nop; IO_BIT[PORTC,2]=false` → ~250-375 ns high. **All write-bus timings have wide margin.**

### 6.3 Power-on initialization (Newhaven's own example, datasheet page 11)

This is the **4-bit init sequence Newhaven recommends**:

```c
void init() {
    P1 = 0;
    P3 = 0;
    Delay(100);                  // Wait >40 msec after power is applied
    P1 = 0x30;                   // put 0x30 on the output port
    Delay(30);                   // must wait 5ms, busy flag not available
    Nybble();                    // command 0x30 = Wake up
    Delay(10);                   // must wait 160us, busy flag not available
    Nybble();                    // command 0x30 = Wake up #2
    Delay(10);
    Nybble();                    // command 0x30 = Wake up #3
    Delay(10);                   // can check busy flag now instead of delay
    P1 = 0x20;
    Nybble();                    // Function set: 4-bit interface
    command(0x28);               // Function set: 4-bit/2-line
    command(0x10);               // Set cursor
    command(0x0F);               // Display ON; Blinking cursor
    command(0x06);               // Entry Mode set
}
```

**Critical line: `Delay(100); // Wait >40 msec after power is applied`.**
This is what the firmware does NOT do.

### 6.4 What the f005 firmware actually does (LCD init at 0x11c8)

```
RESET (0x14a6) → SRAM clear (~30 µs) → register init (~100 µs)
              → 0x150e jmp to unifyboxes patch (~5 µs) → 0x1512 sei
              → 0x1514 rcall 0x11c8 (initialize_lcd)

initialize_lcd (0x11c8):
   r27 = 4
   loop 4 times:
       PORTC = 0x30        ; "function set 8-bit"
       PORTC[2] = 1 ; nop ; PORTC[2] = 0     ; ~250 ns E pulse
       sleep(0x22)         ; ≈ 359 ms (see §6.5)
       r27--
   PORTC = 0x20            ; "function set 4-bit"
   PORTC[2] = 1 ; nop ; PORTC[2] = 0
   sleep(0x22)             ; ≈ 359 ms
   set_lcd_position(0x28)  ; 4-bit, 2 line, 5x8 — full byte via 2 nibble writes
   set_lcd_position(0x0C)  ; display on, no cursor
   set_lcd_position(0x01)  ; clear
```

**The pre-init delay between Vcc rising and the FIRST `PORTC = 0x30` write
is approximately 130–200 microseconds**, not 40 ms. The 359 ms gaps come
*after* each E-strobe, so the SECOND attempt onward has plenty of margin —
but if the first nibble strobe lands while the ST7066U's internal POR is
still asserted, the LCD enters undefined state. Subsequent "function set"
nibbles can't always rescue it.

### 6.5 sleep parameter math

`delay_0x183e(r26)`:

```
push r27, r28
loop r26 times:
    r28 = 110
    loop r28 times:
        r27 = 0xFF
        loop r27 times:    ; 3 cycles per inner iteration
            r27--
            brne
        r28--
        brne
    r26--
    brne
```

Inner: 3 × 256 = 768 cycles. Middle: 768 × 110 ≈ 84,480 cycles. Outer:
84,480 × r26 cycles.

At 8 MHz, **84,480 cycles = 10.56 ms per outer-loop iteration**. So
`sleep(0x22)` = 34 × 10.56 ms ≈ **359 ms**.

### 6.6 ST7066U internal POR window — the marginal-Vcc-rise issue

The ST7066U datasheet (Sitronix) states that the internal power-on reset
circuit is reliable only for **Vcc rise time between 0.1 ms and 10 ms**. If
the rise is slower than 10 ms — common when feeding the LCD off a 5V rail
filtered through a 7805 + bulk caps + ferrite — the internal reset *can*
fail to assert correctly, and the LCD comes up with random instruction
register state. The firmware's "function set 0x30 × 4" pattern is the
HD44780 standard recovery for this case **if it's started after Vcc has
fully settled**.

This is exactly the failure mode that produces "solid blocks on the top
row" — DDRAM is in 8-bit mode with auto-increment on the wrong line and
without a clear, so the cursor address rolls into CGRAM and prints the
all-pixels-on character.

---

## 7. Most likely root cause for the intermittent symptom

The board exhibits two reproducible behaviours at the same hardware state:

1. **Most boots: solid blocks on top row, no text** — LCD never accepted
   the function-set sequence; remained in undefined post-POR state.
2. **Occasional boots: clean text "Failure 21 / Shut Off Power"** — LCD
   accepted the init **and** F21 self-test fired.

Two AVRs and two front panels reproduce identically; power rails are stable
to a DMM; symptom changes with ribbon orientation.

### 7.1 Best hypothesis: ST7066U internal POR is borderline, AND the F21 trip is real

Two independent things are happening, not one:

**A. The "blocks vs. text" outcome is governed by the LCD's internal POR.**
The f005 firmware lacks the >40 ms post-Vcc-rise delay that Newhaven's own
example code calls out. The ST7066U's POR is reliable only for Vcc rise
times between 0.1 ms and 10 ms; the v1.4 5V rail is fed through a 7805
behind LM2941T, D1, 1000µF + 0.1µF + the 12V rail's 470µF, and the ferrite
on AVCC. Cold inrush from the SLA battery into all those caps will
overshoot 10 ms easily. When the rise is slow, the LCD's internal reset
mis-asserts, the firmware's blind 4× function-set fails to recover it, and
you see solid blocks. Sometimes the rise is fast enough (depends on
battery state, capacitor temperature, contact bounce in S5) and the LCD
comes up clean.

**B. When the LCD does come up clean, F21 trips because PA2 reads
non-zero.** On battery only, U+ should be 0 V and PA2 → 0 V → ADC2 = 0,
well below the 146 (=0x92) threshold. If the box is reporting Failure 21,
**something is driving PA2 above 2.85 V at boot**. Three plausible causes:

  - U+ is not actually 0 V. Check J8 with a DMM at battery-only boot — is
    there >5 V at the centre pin? D1 leakage, board contamination, or a
    floating wall-adapter cable can do this.
  - The AVCC reference is brown-out-low (e.g., 3 V instead of 5 V) at the
    moment the firmware reads ADC2/ADC3, scaling the 0V at PA2 into a
    relative reading > 146/256. This is a clock-startup or LDO-transient
    issue on AVCC. Inspect the AVCC pin (30) of the ATmega16 with a scope
    during the first 50 ms of boot.
  - The ADMUX auto-cycling in the ADC ISR isn't running cleanly because
    interrupt-priority / clock startup is glitching, leaving Y+2 still at
    its seed value `0x56` (= 86) **but** Y+3 also stuck at seed `0x85`
    (= 133, < 142). That actually fails the *battery-low* check first
    (jumps to 0x590, "battery low" message), not F21. So if you see
    Failure 21 specifically (not a battery-low halt), the ISR auto-cycle
    *is* running and ADC2 actually read high.

The ribbon-orientation effect is consistent with hypothesis A modulating
how cleanly the LCD's VDD rail rises (the ribbon carries +5V on multiple
pins — orientation flip changes which J11 conductors carry +5V vs which
carry signal, changing the inrush profile into the LCD's local C42 0.1µF
bypass).

### 7.2 The single test that confirms or rules it out

**Scope-probe both AVCC (pin 30) and the LCD's VDD pin (LCD pin 2, top of
C42) simultaneously while toggling power.** Trigger on the rising edge of
either. You are looking for two things:

1. **Vcc rise time on both rails.** If either rail takes longer than ~10 ms
   to cross from 0.5 V to 4.5 V, the ST7066U POR is being defeated — that
   confirms hypothesis A. Mitigation: add an explicit `delay 0x4` (≈42 ms)
   call as the first instruction in `initialize_lcd` (a 2-byte patch at
   `0x11c8`: insert `ldi r26, 0x04 ; rcall 0x183e` before the loop). Or,
   externally, hardware-reset the LCD (briefly pull VDD low after AVR boot)
   before the firmware tries to talk to it.

2. **PA2 voltage at the same trigger.** If PA2 ≥ 2.85 V at any time during
   the first 50 ms of boot **and you are on battery only**, that explains
   F21. Trace why — measure U+ at J8, measure D1 leakage, measure resistance
   from PA2 to +5V (should be infinite minus the divider chain).

If both AVCC and VDD_LCD rise cleanly within <5 ms AND PA2 stays below
1 V on battery-only boot, then hypothesis A and B are both wrong and the
problem lies elsewhere (most likely: AVR clock-startup oscillator damage,
brown-out detection mis-set, or contamination on the AVR socket pins). The
fact that two AVRs and two panels reproduce identically rules out a single
defective IC, leaving the board's passive components (caps, ribbon, regulator)
or a routing/inrush issue as the prime suspects.

---

## Source references used

- Annotated upstream firmware (binary identical to our `backup_flash.bin` for
  all addresses outside the f005 patch territory ≥ 0x3000):
  https://github.com/teledildonics/buttshock-et312-firmware
  Cloned to `/tmp/buttshock-fw`.
  Tag file: `/tmp/buttshock-fw/annotation/312-16-decrypted-combined.tags`
  Failure-codes table: `/tmp/buttshock-fw/annotation/312-16-failcodes.txt`
- Frankenbutt patch source (already in `/tmp/frankenbutt`):
  https://github.com/CrashOverride85/buttshock-et312-frankenbutt
- Disassembly of our flash (raw `avr-objdump -m avr5 -b binary -D`):
  `/tmp/backup_flash.dis` (7,945 lines)
- v1.4 schematic: `/Users/jas/Documents/git/o4wp/mk312-bt/1-order-boards/schematics/pages/v1.4 Schematic Page 1.png` … `Page 5.png`
- Newhaven NHD-0216K1Z-NSW-FBW-L datasheet rev 6 (2019-03-01):
  https://newhavendisplay.com/content/specs/NHD-0216K1Z-NSW-FBW-L.pdf
- ST7066U controller note (linked from above):
  https://newhavendisplay.com/content/app_notes/ST7066U.pdf
- Third-party F20/F21 debug write-up (CrazyEstim / hvprvbo, 2021-03-29):
  https://hvprvbo.blogspot.com/2021/03/mk312-btfailure20-failure21-debug-for.html
  PDF: https://drive.google.com/file/d/1gr-n5ldNQqSA_JH1kqPSWMPF73wiGk7i/view
- ATmega16 datasheet (Microchip): I/O register addresses (ADMUX = 0x07,
  ADCSRA = 0x06, PORTC = 0x15, DDRC = 0x14, PORTB = 0x18, DDRB = 0x17,
  PORTD = 0x12, DDRD = 0x11) — used to decode every `out`/`in` instruction
  in §1.

## Sources I could NOT retrieve

- Wayback Machine snapshots of metafetish.club threads /357, /419, /629,
  /1327. The fetch tool's pre-check hook timed out on every URL form I
  tried; only Google search index titles came back. The hvprvbo blog above
  is the closest substitute. **No verbatim quote from the metafetish forum
  about Failure 21 was obtainable in this session.**
- The original ST7066U Sitronix datasheet PDF — searches returned mirrors
  but the WebFetch tool could not parse the PDFs; the Newhaven app-note
  copy was the substitute used.

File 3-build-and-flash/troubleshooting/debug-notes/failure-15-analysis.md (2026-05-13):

# Failure 15 — divide-by-zero (firmware sanity)

| Field | Value |
| --- | --- |
| Code (decimal) | **15** |
| Branch sites | `0x1396`, `0x13c4` (both `rjmp` → `0x1676`) |
| Test type | Divide-by-zero precondition checks |
| When it runs | Any time the firmware performs a 16-bit division |
| Class | Firmware bug — no hardware diagnosis applies |

## Summary

F15 fires from two sites inside the divide routine at `0x138c`. Both sites
guard against a zero divisor: the first at `0x1394` catches a zero high byte
before the long-division loop runs; the second at `0x13c2` catches a zero
`{r26:r27}` pair just before the actual divide. F15 indicates a
firmware-internal arithmetic precondition violation, not a hardware fault. In
a working stock build this code should never appear; if it does it points at
a bug in firmware (the source f005 tree or a custom patch) or at corrupted
state — never at a solderable component.

## Disassembly evidence

The divide routine entry:

```
138c:  push r26, r27
1390:  and  r31, r31         ; r31 = high byte of divisor
1392:  brne 0x1398           ; if non-zero, OK
1394:  ldi  r26, 0x0F        ; ← loads code 15
1396:  rjmp 0x1676           ; ← FAILURE 15 (early)
1398:  ...                   ; long-division proper
13bc:  cp   r27, r29         ; r29 is zero-register
13be:  cpc  r26, r29
13c0:  brne 0x13c6           ; if {r26:r27} != 0, OK
13c2:  ldi  r26, 0x0F        ; ← loads code 15 (second site)
13c4:  rjmp 0x1676           ; ← FAILURE 15 (late)
```

Both checks fire on the same condition (divisor = 0) at different points in
the routine — defensive programming inside the divide.

## Likely cause

F15 is firmware-internal. If you ever see it in real life:

1. **Patched firmware bug.** If you applied a custom patch to f005 (e.g. a
   custom boot message or a feature mod), the patch may have introduced a
   divide that doesn't validate its operands.
2. **Corrupted EEPROM** driving zero into a config field that's later used as
   a divisor. Reseat / reflash EEPROM.
3. **Cosmic-ray-class glitch** (extremely rare) — bit flip in RAM. Power-cycle
   clears it.

## Diagnostic procedure

1. Power-cycle. Does it reproduce? If only intermittent, EEPROM or RAM glitch.
2. If reproducing every boot, the firmware is suspect. Reflash known-good
   `f005.bin`.
3. If you've applied custom patches, revert one at a time until F15 stops.

## Fix

Reflash known-good firmware. If F15 persists with stock `f005.bin`, that
would be a genuine bug worth filing upstream — but in practice this never
happens with the canonical build.

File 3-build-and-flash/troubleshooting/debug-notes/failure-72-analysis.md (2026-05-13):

# Failure 72 — state variable RAM[0x01F1] overflow

| Field | Value |
| --- | --- |
| Code (decimal) | **72** |
| Branch site | `0x1a1e` (`rjmp .-938` → `0x1676`) |
| Test type | Internal state-variable bounds check |
| When it runs | Inside the routine at `0x1a06` — called from mode/ramp engine |
| Class | Firmware — almost never a hardware fault |

## Summary

F72 fires from the routine at `0x1a06`, which increments an accumulator at RAM
`0x0214` and then checks a related state variable at `0x01F1`. If RAM[0x01F1]
ever reaches ≥ 56 (0x38), F72 trips. This is a defensive check on a
firmware-internal state machine — likely a step counter for a multi-stage
operation (mode setup, ramp progression, audio sequencer phase). F72 normally
indicates that the state machine got out of sync, often due to an interrupt
race or corrupted RAM.

## Disassembly evidence

```
1a06:  push r30, r31
1a0a:  lds  r30, 0x0214      ; load accumulator
1a0e:  add  r30, r26         ; accumulator += r26 (the new step)
1a10:  sts  0x0214, r30      ; store back
1a14:  lds  r30, 0x01F1      ; load state variable
1a18:  cpi  r30, 0x38        ; ≥ 56 ?
1a1a:  brcs 0x1a20           ;   no → continue
1a1c:  ldi  r26, 0x48        ; ← loads code 72
1a1e:  rjmp 0x1676           ; ← FAILURE 72
```

RAM[0x01F1] is a step counter. The function adds whatever's in `r26` to
RAM[0x0214] (an accumulator), then aborts if the step counter is too high.
In stock firmware this should never trip because the calling code resets the
counter periodically.

## Likely cause

1. **Custom firmware patch.** A patch that adds modes / ramps / step logic
   without resetting RAM[0x01F1] cleanly between cycles will run the counter
   up over time. Check any user-added f005 patches.
2. **EEPROM corruption seeding bad state** at boot — reflash
   `backup_eeprom.bin`.
3. **Interrupt race** in heavily-loaded modes (e.g. high-frequency rhythm
   modes) where an ISR fires inside the state-update path. This would be a
   real upstream bug.

## Diagnostic procedure

1. Note **which mode** was running when F72 fired — switch back to stock f005
   modes and try to reproduce. If F72 stops, you have a custom-patch bug.
2. Power-cycle and reflash EEPROM. If F72 reproduces from a clean EEPROM with
   stock firmware, that would be a real upstream bug worth reporting.
3. There's no hardware-side fix — F72 is a firmware-state failure.

## Fix

Reflash stock `f005.bin` + clean `backup_eeprom.bin`. If reproducible from
clean state, file upstream — but in practice this is vanishingly rare on
stock firmware.

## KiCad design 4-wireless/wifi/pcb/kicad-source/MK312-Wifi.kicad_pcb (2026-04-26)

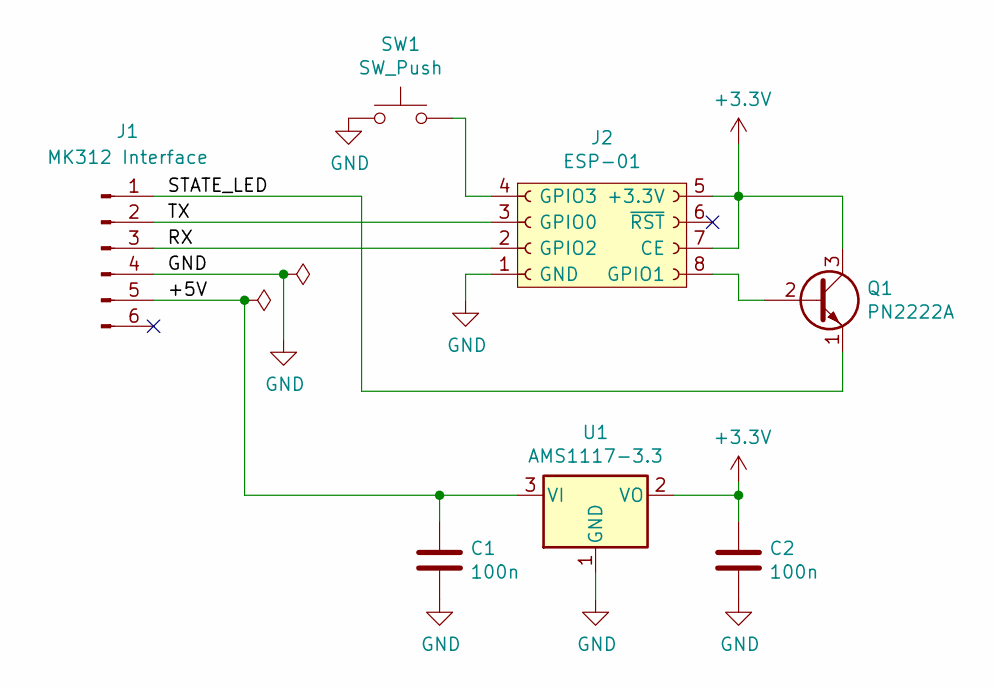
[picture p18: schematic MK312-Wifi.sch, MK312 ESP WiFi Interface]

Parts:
C1, C2: 100n; C_Disc_D4.7mm_W2.5mm_P5.00mm
J1: MK312 Interface; Pin_Header_Angled_1x06_Pitch2.54mm
J2: ESP-01; ESP_2x04
Q1: PN2222A; TO-92_Molded_Wide_Oval
SW1: SW_Push; SW_PUSH_6mm
U1: AMS1117-3.3; SOT-223-3_TabPin2

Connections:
+3V3: C2.1, J2.5 (+3.3V), J2.7 (CE), Q1.3 (C), U1.2 (VO)
/+5V: C1.1, J1.5, U1.3 (VI)
/RX: J1.3, J2.2 (GPIO2)
/STATE_LED: J1.1, Q1.1 (E)
/TX: J1.2, J2.3 (GPIO0)
GND: C1.2, C2.2, J1.4, J2.1 (GND), SW1.1, U1.1 (GND)
unnamed: J2.4 (GPIO3), SW1.2
unnamed: J2.8 (GPIO1), Q1.2 (B)

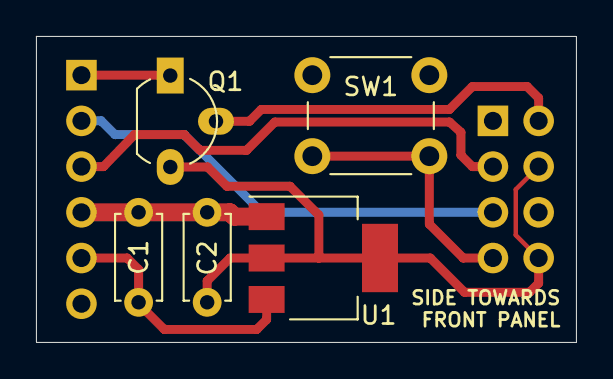
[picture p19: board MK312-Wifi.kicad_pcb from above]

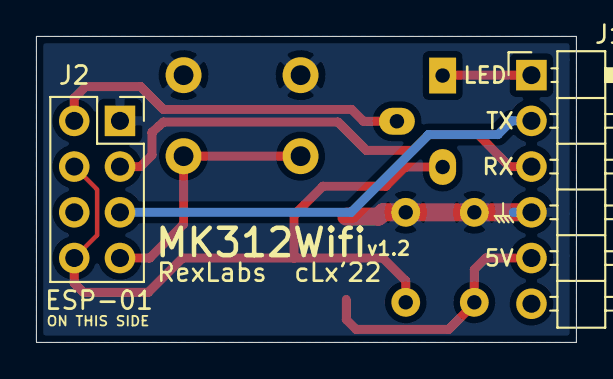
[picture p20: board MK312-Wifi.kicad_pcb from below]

Board: 2 copper layers, 30.0 x 17.0 mm, 7 parts (2 on the bottom side), 8 nets.

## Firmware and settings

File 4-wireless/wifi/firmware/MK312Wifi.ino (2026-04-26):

/*
 *  MK-312 Wifi interface
 *  This project is hosted here: https://github.com/Rangarig/MK312WIFI
 */

#include "ESP8266WiFi.h"
#include <ESP8266WebServer.h>
#include <SoftwareSerial.h>
#include <WiFiManager.h>        // https://github.com/tzapu/WiFiManager
#include <WiFiUdp.h>
#include <WebSocketsServer.h>   // https://github.com/Links2004/arduinoWebSockets
#include <FS.h>
#include <LittleFS.h>

#define VERSION 1.2.05
#define AP_NAME "MK312CONFIG-AP"

#define UDP_DISCOVERY_PORT 8842 // UDP port to listen to, so devices can find the interface by sending a broadcast packet
#define COMM_PORT          8843 // main communication port in TCP

#define LED_PIN               1 // radio LED of the mk312 (we use TX, since the system will output garbage on start, and we do not want to confuse the mk312)
#define RX_PIN                0 // rx pin to be used by the software implementation
#define RESET_WIFI_PIN        3 // The pin that needs to be pushed to ground to reset the wifi settings
#define TX_PIN                2 // tx pin to be used by the software implementation

#define FAIL_CHECKSUM         1
#define FAIL_HANDSHAKE_A      2
#define FAIL_HANDSHAKE_B      3
#define FAIL_HANDSHAKE_C      4
#define FAIL_REPLY            5
#define FAIL_PEEKREPLY       10
#define FAIL_POKEREPLY       11

char packetBuffer[UDP_TX_PACKET_MAX_SIZE + 1]; // buffer to hold incoming packet,

WiFiServer wifiServer(COMM_PORT); // The wifiserver, that sends data and receives controls
WiFiUDP udp; // The UDP Server that is used to tell the client the IP Address
SoftwareSerial mySerial(RX_PIN, TX_PIN, false);

void setStatusLed(bool status) {
  if (status) {
    digitalWrite(LED_PIN, HIGH);   // turn the LED on (HIGH is the voltage level)
  }
  else {
    digitalWrite(LED_PIN, LOW);   // turn the LED off
  }
}

byte mk312key = 0; // The key to be used to talk to the mk312
byte wifikey = 0;  // The key used when we are talked to from wifi

// Writes a byte to the mk312
void mk312write(byte b) {
  mySerial.write(b);
}

// Writes an encrypted byte to the mk312
void mk312write_enc(byte b) {
  mySerial.write(b ^ mk312key);
}

// Waits for a byte from the mk312 and returns it
int mk312read() {
  unsigned long timeout = millis() + 1000; // We wait for one second until we go into errorstate

  while (mySerial.available() == 0) {
    delay(10);
    if (millis() > timeout)
      return -1;
  }
  return mySerial.read();
}

// Flashes an error code until the end of time
void errorstate(byte e) {
  while (true) {
    for (byte i=0;i<e;i++) {
      digitalWrite(LED_PIN, HIGH);   // turn the LED on
      delay(300);
      digitalWrite(LED_PIN, LOW);    // turn the LED off
      delay(150);
    }
    delay(2000);
  }
}

// Internal Poke Command
void poker(int addr, byte b) {
  byte lo = addr >> 8;
  byte hi = addr & 0xff;
  mk312write_enc(0x4d);
  mk312write_enc(lo);
  mk312write_enc(hi);
  mk312write_enc(b);
  mk312write_enc((0x4d + lo + hi + b) % 256);
  if (mk312read()!=0x06) errorstate(FAIL_POKEREPLY);
}

// Peeks an address from the memory of the device
byte peeker(int addr) {
  byte lo = addr >> 8;
  byte hi = addr & 0xff;
  mk312write_enc(0x3c);
  mk312write_enc(lo);
  mk312write_enc(hi);
  mk312write_enc((0x3c + lo + hi) % 256);
  if (mk312read()!=0x22) errorstate(FAIL_PEEKREPLY);
  byte val = mk312read();
  byte chk = mk312read();
  if (((val + 0x22) % 256) != chk) errorstate(FAIL_CHECKSUM);
  return val;
}

// Write to screen
void writeText(const char myMsg[]) {
  int len = strlen(myMsg);

  // display the message text...
  for (int i=0;i<len;i++) {
    poker(0x4180,myMsg[i]);
    poker(0x4181,64+i);
    poker(0x4070,0x13);
    while (peeker(0x4070) != 0xff) delay(1);
  }

  // ... then clear the rest of the screen's line with spaces
  for (int i=len;i<16;i++) {
    poker(0x4180,' ');
    poker(0x4181,64+i);
    poker(0x4070,0x13);
    while (peeker(0x4070) != 0xff) delay(1);
  }
}

// initializes wifi
void wifi_setup() {
  WiFiManager wifiManager;
  wifiManager.setDebugOutput(false);
  wifiManager.setAPCallback(configModeCallback);
  wifiManager.autoConnect(AP_NAME);

  bool statusled = false;
  while (WiFi.status() != WL_CONNECTED) {
    delay(2000);
    statusled = !statusled;
    setStatusLed(statusled);
  }

  setStatusLed(false);
  udp.begin(UDP_DISCOVERY_PORT);
  wifiServer.begin();
}

void configModeCallback (WiFiManager *myWiFiManager) {
  (void)myWiFiManager; // -Wunused-parameter
  writeText("WifiAP");
}

// Establishes or reestablishes communication with the mk312 device
void mk312_setup() {
  // Clear potential garbage from buffer
  delay(200);

  byte attempts = 12;
  while (attempts > 0) {
    attempts --;
    mySerial.flush();
    mk312write(0x00); // Initiate handshake
    delay(1); // Give the system time to answer
    if (mk312read() == 0x07) break;
  }

  if (attempts == 0) errorstate(FAIL_HANDSHAKE_A); // Failed, we did not obtained any 0x07 reply

  mk312key = 0x00;

  // Set encryption key
  mk312write(0x2f); // Set key command
  mk312write(0x00); // To keep things simple we will use 00 as a key
  mk312write(0x2f); // Checksum (no key, so really just the commmand)

  byte rep = mk312read();
  byte boxkey = mk312read();
  byte check = mk312read();

  if (rep != 0x21) errorstate(FAIL_HANDSHAKE_B); // handshake fail
  if (check != (rep + boxkey)) errorstate(FAIL_CHECKSUM); // checksum fail

  // Store the encryption key for later use
  mk312key = boxkey ^ 0x55;
}

void setup() {
  pinMode(RESET_WIFI_PIN, INPUT);
  pinMode(LED_PIN, OUTPUT);

  // Setup communications with the MK312.
  mySerial.begin(19200);
  pinMode(TX_PIN, OUTPUT);
  pinMode(RX_PIN, INPUT); // For some reason the ESP insists on a pullup for the RX pin, which will then not be understood, so... we rectify that.
  mk312_setup();

  // Ready for incoming connections
  wifi_setup();
  IPAddress ip = WiFi.localIP();
  char s[17];
  sprintf(s, ">%i.%i.%i.%i", ip[0],ip[1],ip[2],ip[3]);
  writeText(s);
  webservers_setup();
}

// Checks if the AP button is pressed
void checkForAP() {
    bool resetWifi = !digitalRead(RESET_WIFI_PIN);
    if (resetWifi) {
      writeText("WifiAP");
      webservers_stop();
      WiFiManager wifiManager;
      wifiManager.startConfigPortal(AP_NAME);
    }
}

bool wifiEncryption = false; // Do we use encryption on wifi side?

// Waits for a byte from wifi and returns it
byte wifiread(WiFiClient client) {
  unsigned long timeout = millis() + 1000; // We wait for one second until we go into errorstate

  while (client.available() == 0) {
    delay(10);
    if (millis() > timeout)
      return -1;
  }
  if (wifiEncryption)
    return client.read() ^ wifikey; // Decrypt
  else
    return client.read();
}

void handleLedBlinking(int setCount=-1, bool wantedFinalLedState=false) {
  static unsigned long ledBlinkTimeout = 0;
  static int ledCount = 0;
  static bool ledState = false;
  static bool finalLedState = false;

  if (setCount != -1) {
    ledCount = setCount;
    finalLedState = wantedFinalLedState;
  }

  if (!ledCount) {
    setStatusLed(finalLedState);
    ledState = finalLedState;
    return;
  }

  if (millis() > ledBlinkTimeout) {
    ledBlinkTimeout = millis() + 200;
    ledCount--;
    ledState = !ledState;
    setStatusLed(ledState);
  }
}

void loop() {
  handleUDP();
  handleTCPIP();
  handleWebservers();
  checkForAP();
  handleLedBlinking();
}

// Handles the incoming TCPIP requests
void handleTCPIP() {
  byte cmd = 0; // conmmand read
  byte val1 = 0; // Value
  byte hi = 0; // Hi address
  byte lo = 0; // Lo address
  byte chk = 0; // Checksum
  byte rep = 0; // Reply byte
  byte readbuf[16]; // Read buffer for write byte passthrough
  long chksum = 0; // Checksum for readbuffer

  WiFiClient client = wifiServer.accept();

  if (client) {
    client.setNoDelay(true);
    wifiEncryption = true;
    wifikey = 0;

    while (client.connected()) {
        handleLedBlinking();

        WiFiClient new_client = wifiServer.accept();
        if (new_client) {
          client.stop();
          client = new_client;
          wifikey = 0;
          handleLedBlinking(0, true);
        }

        // Check if a control message has been sent
        while (client.available() > 0) {
          cmd = wifiread(client);

          // Ping command is replied to with 07
          if (cmd == 0x00) {
            wifikey = 0;
            client.write(0x07);
            continue;
          }

          // Intercept set key command and change the local key only, not the mk312 one
          if (cmd == 0x2f) { // Set key command
            val1 = wifiread(client);
            chk = wifiread(client);

            // If key and checksum are 0x42 encryption is disabled
            if ((val1 == 0x42) && (chk == 0x42)) {
              wifiEncryption = false;
              client.write(0x69); // Reply code, key accepted
              continue;
            }

            if (chk != ((val1 + cmd) % 256)) {
              client.write(0x07); // Checksum error
              continue;
            }
            wifikey = val1 ^ 0x55;
            uint8_t response[3];
            response[0] = 0x21; // Reply code, key accepted
            response[1] = 0x00; // Our own "box" key, which for simplicity will always be 0
            response[2] = 0x21; // The checksum
            client.write(response, 3);
            continue;
          }

          // As the rest of the code is for communicating with the mk312,
          // we're making sure serial reception buffer is empty
          mySerial.flush();

          // Read byte command
          if (cmd == 0x3c) { // read byte command
            lo = wifiread(client);
            hi = wifiread(client);
            chk = wifiread(client);

            if (((cmd + lo + hi) % 256) != chk) {
              client.write(0x07); // Wrong checksum
              continue;
            }

            // Command checks out, send it to device
            mk312write_enc(cmd);
            mk312write_enc(lo);
            mk312write_enc(hi);
            mk312write_enc(chk);

            // Handle reply
            rep = mk312read();
            val1 = mk312read();
            chk = mk312read();

            // in software version previous or equal than 1.2.02
            // here was a checksum check, replying 0x07 in case of errors.
            // this made code debugging more difficult and is removed for now,
            // the checksum validity is also checked by the client application.

            uint8_t response[3] = {rep, val1, chk};
            client.write(response, 3);
            continue;
          }

          // Write byte command implementation
          if ((cmd & 0x0f) == 0x0d) { // write byte command
            handleLedBlinking(3, true);
            val1 = (cmd & 0xf0) >> 4; // Number of bytes to write

            hi = wifiread(client);
            lo = wifiread(client);

            chksum = cmd + hi + lo;

            // Intercept bytes
            for (int i = 0; i < (val1 - 3); i++) {
              readbuf[i] = wifiread(client);
              chksum += readbuf[i];
            }

            chk = wifiread(client);

            // Make sure checksum is ok
            if ((chksum % 256) != chk) {
              client.write(0x07); // Wrong checksum
              continue;
            }

            // Intercept key change by a poke command
            // TODO: Theoretically someone could write to 4213 by a command writing several bytes
            // But nobody would do that... right? RIGHT?
            if ((val1 == 4) && (hi == 0x42) && (lo == 0x13)) {
              wifikey = readbuf[0];
              client.write(0x06); // OK, we changed the local key
              continue;
            }
            mk312write_enc(cmd);
            mk312write_enc(hi);
            mk312write_enc(lo);
            for (int i = 0; i < (val1 - 3); i++) {
              mk312write_enc(readbuf[i]);
            }
            mk312write_enc(chk);

            rep = mk312read();
            client.write(rep);
            continue;
          }

          // unknown command?
          client.write(0x07);
        }
    }

    client.stop();
    handleLedBlinking(0, false);
  }
}

void handleUDP() {
  // if there's data available, read a packet
  int packetSize = udp.parsePacket();
  if (packetSize) {
    // read the packet into packetBufffer
    int n = udp.read(packetBuffer, UDP_TX_PACKET_MAX_SIZE);
    packetBuffer[n] = 0;

    if(strcmp(packetBuffer, "ICQ-MK312") == 0) {
      // send a reply, to the IP address and port that sent us the packet we received
      handleLedBlinking(1, false);
      udp.beginPacket(udp.remoteIP(), udp.remotePort());
      IPAddress ip = WiFi.localIP();
      udp.write(ip[0]);
      udp.write(ip[1]);
      udp.write(ip[2]);
      udp.write(ip[3]);
      udp.endPacket(); // "flush" the output as we're sending the packet UDP now
    }
  }
}

/************************************************************************
 * All the following code is for implementing web and websocker servers *
 ************************************************************************/

#define CONFIG_LITTLEFS_SPIFFS_COMPAT 1

ESP8266WebServer webserver(80);
WebSocketsServer websocketserver(81);

void webservers_setup() {
  webserver.on("/EXEC", handleHttpGetEXEC);
  webserver.on("/RAW", handleHttpGetRAW);

  webserver.onNotFound([](){
    if(!handleFileRead(webserver.uri()))
      webserver.send(404, "text/plain", "FileNotFound");
  });

  LittleFS.begin();
  webserver.begin();
  websocketserver.begin();
  websocketserver.onEvent(websocketevent);
}

void webservers_stop() {
  webserver.close();
  webserver.stop();
  websocketserver.close();
}

void handleWebservers() {
  websocketserver.loop();
  webserver.handleClient();
}

bool handleFileRead(String path){
  if (path.endsWith("/")) path += "index.html";
  if (LittleFS.exists(path)){
    File file = LittleFS.open(path, "r");
    webserver.streamFile(file, getContentType(path));
    file.close();
    return true;
  }
  return false;
}

void handleHttpGetRAW() {
  handleHttpGetBase(true);
}

void handleHttpGetEXEC() {
  handleHttpGetBase(false);
}

void handleHttpGetBase(bool raw) {
  String res = "ERR";

  if(webserver.hasArg("cmd")) {
    String cmd = webserver.arg("cmd");

    String val = "";
    if(webserver.hasArg("val")) {
      val = webserver.arg("val");
    }

    if(raw) {
      poker(str2hex(cmd.c_str()), str2hex(val.c_str())); res="OK";
    }
    else {
      res = websocket_parse_cmd(cmd, val) ?"OK":"ERR";
    }
  }

  webserver.send(200, "text/plain", res);
}

String getContentType(String filename){
    if(filename.endsWith(".html")) return "text/html";
    else if(filename.endsWith(".css")) return "text/css";
    else if(filename.endsWith(".js")) return "application/javascript";
    return "text/plain";
}

void websocketevent(uint8_t num, WStype_t type, uint8_t * payload, size_t length) {
  if(type == WStype_CONNECTED) {
    handleLedBlinking(0, true);
    IPAddress ip = websocketserver.remoteIP(num);
    String message = ip.toString() + String(" connected.");
    websocketserver.broadcastTXT(message);
  }

  if (type == WStype_TEXT) {
    String key = "";
    String val = "";
    bool bval = false;

    for (size_t x = 0; x < length; x++) {
      if (((char)payload[x]) == '=') {
        bval = true;
        continue;
      }

      if (bval) {
        val+=(char)payload[x];
      }
      else {
        key+=(char)payload[x];
      }
    }

    // send response to all connected clients
    String res = key;
    if (val != "") { res+="="+val; }
    res+= websocket_parse_cmd(key, val) ?" OK":" ERR";
    websocketserver.broadcastTXT(res);
  }
}

bool websocket_parse_cmd(String cmd, String val) {
  // todo: validate input vals
  // todo: possibility to read the current values
  // todo: websockets client should handle broadcasted messages to them
  if (cmd == "startRamp")        poker(0x4070, 0x21);
  else if(cmd == "CutLevels")    cutLevels(val.toInt());
  else if(cmd == "EnableADC")    enableADC(val.toInt());
  else if(cmd == "DisableADC")   enableADC(!val.toInt());
  else if(cmd == "LevelA")       poker(0x4064, val.toInt());
  else if(cmd == "LevelB")       poker(0x4065, val.toInt());
  else if(cmd == "MultiAdjust") {
    //  multiadust_scaled based on minimal and maximal ranges values
    int ma_min = peeker(0x4086); // eg. 15, right position
    int ma_max = peeker(0x4087); // eg. 127, left position;
    int ma_newval = ma_max - (val.toFloat() * 0.01 * (float)(ma_max - ma_min));
    if (ma_newval > ma_max) ma_newval = ma_max;
    else if (ma_newval < ma_min) ma_newval = ma_min;
    poker(0x420d, ma_newval);
  }
  else if(cmd == "Mode") {
    poker(0x407b,str2hex(val.c_str()));
    poker(0x4070,0x4);
    poker(0x4070,0x12); // execute mode
  }
  else {
    return false;
  }

  handleLedBlinking(3, true);
  return true;
}

void cutLevels(bool enabled) {
  if (enabled) {
    enableADC(false);
    poker(0x4064, 0);
    poker(0x4065, 0);
  }
  else {
    enableADC(true);
  }
}

void enableADC(bool enabled) {
  poker(0x400f, enabled?0x00:0x01);
}

int str2hex(const char str[]) {
  return (int)strtol(str, 0, 16);
}

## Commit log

2026-04-26 Reorganize: stage v1.4/ + old/ structure
    - Remove pre-v1.4 sprawl (Eagle source, BOMs, case, gerbers) at root
    - Move v1.2/v1.3 artifacts under old/ (renamed to historical/ in next commit)
    - Stage new v1.4/ tree: bluetooth, bom, case, firmware, forum_docs,
    gerbers, schematics, tutorials, plus updated Mouser BOM with Amazon links
    - Add .gitignore for .DS_Store, Eagle lock/backup files
    - Drop duplicate v1.4/MK-312BT-BOM-Mouser.csv (kept v1.4/bom/ copy)
    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
    [MK-312BT Front Panel V1.2.brd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]
2026-04-26 Reorganize into journey-ordered tree
    Top level reflects the build path:
    1-order-boards/ gerbers, schematics, board layout, v1.4 release notes
    2-order-parts/ BOM-full.csv (master), BOM-mouser-cart.csv, BOM-with-amazon.xlsx
    3-build-and-flash/ firmware, case (3D print), tutorials
    4-wireless/ bluetooth/ (HC-05 init + setup guide); wifi/ added next commit
    docs/troubleshooting/ metafetish forum PDFs (Failure 20, transformer Q,
    parts substitution, etc.) — version-agnostic build wisdom
    historical/ v1.2/v1.3 boms, eagle source, gerbers, build images
    Renames preserve git history. v1.4/ and old/ wrappers removed; their
    contents promoted into t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
    [BOM-full.csv, BOM-mouser-cart.csv, BOM-with-amazon.xlsx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]
2026-04-26 Squashed '4-wireless/wifi/' content from commit 6a1ef85
    git-subtree-dir: 4-wireless/wifi
    git-subtree-split: 6a1ef85085a63a67bb5a7b60db7917319ead7d4f
    [MK312-Wifi.kicad_pcb, MK312-Wifi.sch]
2026-04-26 Rewrite README, add per-section build guides, surface front panel
    Root README is now a journey-oriented entry point: short overview,
    1→2→3→4 table, links to per-section READMEs, link to the
    comprehensive build guide. Replaces the stale Jan 2021 / V1.3-era
    README.
    Per-section READMEs added at each step (1-order-boards,
    2-order-parts, 3-build-and-flash, 4-wireless, docs/troubleshooting,
    historical) — short orientation + links to the relevant build guide
    sections. 4-wireless explains the BT vs WiFi tradeoff.
    Comprehensive build guide moved out of awkward
    3-build-and-flash/tutorials/ into docs/build-guide.md. Stale links
    to upstream github.com/CrashOverride85 paths and the now-offline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
    [MK-312BT V1.4 05-19-2019.GBL, MK-312BT V1.4 05-19-2019.GBO, MK-312BT V1.4 05-19-2019.GBP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]
2026-04-27 Add JLCPCB-ready package for MK312 WiFi adapter PCB (SMT-only path)
    Drop-in upload bundle at 4-wireless/wifi-jlcpcb/ — gerbers + BOM + CPL
    prebuilt for JLCPCB ordering with SMT-only assembly. JLC pre-mounts
    the one SMD part (U1, AMS1117-3.3 in SOT-223, LCSC C6186); the 6
    through-hole parts (C1, C2, Q1, SW1, J1, J2) are user-soldered.
    Cost target: ~$20-25 for 5 boards. Full PCBA-with-THT runs $65-100+
    because of THT setup fees (~$30-50 one-time + extended-part loaded
    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
    [bom.csv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]
2026-04-27 Reorganize: consolidate WiFi adapter content, move clients to 5-software, add CLAUDE.md
    Several rounds of in-progress reorganization across sessions left the
    tree messy. This commit consolidates the layout so each thing lives
    where it logically belongs:
    WiFi subtree internal layout (4-wireless/wifi/):
    - MK312Wifi/ (briefly application/) → firmware/ — matches naming of
    3-build-and-flash/firmware/ for the AVR side; both are "firmware
    for [chip]"
    - MK312-wifi-pcb/ → pcb/ — shorter, matches
    "this is the PCB" intent
    - MK312-wifi-pcb/raw_files/ → pcb/kicad-source/ — meaningful name
    - MK312WIFI_PCB_v1.2_Fabrication_Files.zip → pcb/fab-files.zip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
    [MK312-Wifi.kicad_pcb, MK312-Wifi.sch, bom.csv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]
2026-04-28 Fix BOM: 7 resistor errors, 4 cap groupings, 2 missing diodes (v1.4 schematic verified)
    Cross-checked every R/C/D entry against the v1.4 schematic pages 1-5.
    Resistor value corrections:
    - R7, R8: were grouped at 4.7K, schematic shows 2.2K (mic input
    filter pair) — split off into new "R7,R8 RES 2.2K" line
    - R9: stays at 4.7K, now grouped with R13
    - R13: was a separate line at 47K, schematic shows 4.7K (mic preamp
    gain set — 10x error would break the preamp). Joined R9 group at
    4.7K, removed standalone 47K line
    Resistors added (present on v1.4 schematic, absent from BOM):
    - R61 (100K, mic preamp pull-down) — added to existing 100K line,
    qty 21 -> 22
    - R62 (1K, remote input seri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
    [BOM-full.csv]
2026-04-28 Fix R55: 47R -> 100R to match v1.4 schematic
    The BOM had R55 at 47 ohm, schematic page 3 shows 100 ohm in series
    with the LCD backlight LED, and v1.4 release notes recommend
    100-220 ohm for "single LED in New Haven displays." This build uses
    the BOM-listed Newhaven NHD-0216K1Z, so 100 ohm is the right value.
    Mouser part 660-MF1/4DCT52R1000F (MF1/4DCT52R1000F) — the same part
    that was previously listed as "LED Brightness Opt. 1" before that
    group of alternates was removed. Repurposed as R55 itself.
    [BOM-full.csv]
2026-04-28 LED1-4: split single LED line into per-color Kingbright entries
    Color assignment per user spec:
    - LED1 (OUTPUT A) = orange Kingbright WP7113OD
    - LED2 (OUTPUT B) = orange Kingbright WP7113OD
    - LED3 (RADIO) = red Kingbright WP7113ID
    - LED4 (POWER) = green Kingbright WP7113GD
    All standard-brightness diffused 5mm leaded — picked specifically so
    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
    [BOM-full.csv]
2026-04-28 BOM: add F1 polyfuse, drop R30 0.5R alternate, sync cart CSV
    Schematic page 1 calls out F1 as a 1A POLY between the battery/fuse
    header and the power switch — protects against shorts. Was missing
    from BOM entirely. Added as Bourns MF-R110 (1.1A hold / 2.2A trip
    radial polyfuse, 30V) at Mouser 652-MF-R110.
    Removed the R30 0.5R 1/2W alternate line — this build uses 0.27R
    (matches the 1000uF C6/C7 high-output config). Single R30 line now.
    Regenerated BOM-mouser-cart.csv from BOM-full.csv by dropping the
    "Sourced?" tracking column. The cart CSV had been frozen since
    4/18/2026 and contained the OLD wrong values (R55=47R, R13=47K,
    R7-R8 grouped at 4.7K, missing R61/R62/R63/D4/D5/F1, single L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
    [BOM-full.csv, BOM-mouser-cart.csv]
2026-04-28 BOM: add WiFi adapter section with SMD-vs-THT split explanation
    The BOM previously had only a one-line "Wifi Module (see their parts
    list)" entry pointing at upstream — opaque for someone deciding
    between BT and WiFi. Replaced with a structured section:
    - Restructured wireless choice as "pick ONE: bluetooth OR wifi"
    - Added macOS caveat on HC-05 (Classic SPP deprecated -> use WiFi)
    - Full WiFi adapter parts list with the JLCPCB SMT-only build path
    reference at 4-wireless/wifi/pcb/jlcpcb-package/
    Soldering split made explicit:
    SMD (factory-soldered by JLCPCB SMT line):
    U1 AMS1117-3.3 SOT-223 750-AMS1117-3.3
    THT (hand-solder after boards arrive):
    C1, C2 100nF disc cap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
    [BOM-full.csv, BOM-mouser-cart.csv]
2026-04-28 5-software: drop bundled mk312-gui + dotnet-client, link upstreams instead
    User decision (2026-04): repo scope is hardware/firmware/PCB, not
    maintaining forks of other people's control software. Removed both
    bundled subtrees:
    - 5-software/mk312-gui/ (was clxjaguar/mk312-gui subtree)
    - 5-software/dotnet-client/ (was relocated from MK312WIFI subtree)
    Replaced with a links-only README at 5-software/README.md indexing
    the available upstream clients with their tradeoffs:
    - clxjaguar/mk312-gui (PyQt, WiFi-bridge native, default pick)
    - fenbyfluid/three-twelve-bee (Web Serial, browser-based)
    - boyinsea/ErosWeb (Web Serial, sub/Dom remote-play arch)
    - clxjaguar/m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
    [BOM-full.csv, BOM-mouser-cart.csv]
2026-04-28 DotNetClient back inside wifi/ package; cart CSV Mouser-orderable only
    Per user feedback: the .NET reference client is part of the
    upstream MK312WIFI package (cLx shipped it alongside the firmware
    and PCB). Restored to its original location at
    4-wireless/wifi/DotNetClient/ matching upstream layout.
    Removing it earlier and bouncing it through 5-software/ was a
    unilateral reorg decision — undone now. The wifi subtree directory
    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
    [BOM-mouser-cart.csv]
2026-04-28 Add original debug docs: board-test-methodology PDF + F21 disassembly analysis
    The metafetish.club forum (the canonical MK-312BT troubleshooting venue) is
    offline and its mirrored PDFs only get you so far. This commit adds two pieces
    of original, evidence-based debug documentation written from disassembling the
    firmware and walking the v1.4 schematic + BASCOM HC-05 init source:
    - docs/troubleshooting/debug-notes/board-test-methodology.pdf
    9-page bench procedure for the "LCD shows solid blocks, no text" symptom
    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
2026-05-01 2-order-parts: consolidate to two BOMs, fix Mouser-import format
    Collapses the previous five-file mess (BOM-full.csv + BOM-mouser-cart.csv +
    BOM-with-amazon.xlsx + two long-named .numbers working copies) into exactly
    two files:
    BOM_full.csv Human-readable master with Sourced? tracking column,
    section headers (Hardware / Wireless / WiFi / PC Link /
    Firmware Flashing / Misc), Mouser + Amazon links per part,
    and a `Last modified:` date row at the top.
    BOM_Mouser.csv Strict 4-column Mouser-import format (Mouser Part Number,
    Quantity, Manufacturer Part Number, Customer Part Number),
    headers in row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
    [BOM-full.csv, BOM-mouser-cart.csv, BOM-with-amazon.xlsx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]
2026-05-01 build-guide: add Error 20 prevention/diagnosis section + tester to BOM
    Adds a dedicated "Error 20: match the MOSFETs before you solder" section
    to the build guide, placed right before Board Assembly Instructions so
    builders see it before reaching for the iron. Covers both halves of the
    problem:
    Prevention — measure Vt of every IRL520 and IRF9Z24 with a component
    tester, group by threshold, and only build a board with a tightly-
    matched set. Includes concrete bad/good Vt example sets so the spread
    that triggers Error 20 is obvious.
    Diagnosis — if the board is built and Error 20 appears, measure DC
    across R32 and R43. Both should land between 4.0–4.4 V, but the
    critical s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
    [BOM_full.csv]
2026-05-02 CLAUDE.md: repo flipped back to public
    Was switched private 2026-04-26, then back to public today (2026-05-01).
    Updated the "Repo state" note so future sessions don't operate on the
    old private assumption. Also added a hint that visibility has changed
    before and may change again — agents should check `gh repo view` if
    visibility matters for the task at hand rather than trusting the doc.
2026-05-02 README: add Provenance & scope section
    The top-of-file intro covers the elevator pitch, but anyone evaluating
    the repo (or asking "where did all this come from?") had to dig through
    build-guide.md, the WiFi subtree's README, and 5-software/README.md to
    piece together the lineage. Consolidates that into a single section
    between Reference and Getting help.
    Covers:
    - What this repo is / isn't (a 2026 rehoming of dormant upstreams,
    scoped to boards/BOM/firmware/case; not a fork, not "official",
    not a software hub)
    - Hardware lineage (ET-312B → metafetish/mk312-bt → CrashOverride85
    → here, with the v1.4 hazy-provenance note)
    - WiFi adapter lineage (Rangarig + cLx + timdu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
2026-05-02 build-guide: rewrite firmware section as full Win/Mac/Linux flashing guide
    The old "MK312-BT Firmware" section was 5 bullets with the fuse values
    and a "use an external crystal dammit" punchline — accurate but
    nowhere near enough for a first-time flasher. Replaced with a proper
    walkthrough.
    New "Firmware: flashing the AVR" section covers:
    Pick a firmware Maps the actual .bin files in 3-build-and-flash/
    firmware/ to what each is, marks
    f005-HelloFriend.bin as the recommended default.
    All bundled firmwares already include the LCD
    character-map fix.
    Pick a programmer Default = USBasp clone (BOM list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
2026-05-02 build-guide: integrate HC-05 walkthrough + add firmware backup/source-build
    Two gaps the previous expansion left open:
    1. The Bluetooth section was a 6-line stub of raw AT commands, even
    though 4-wireless/bluetooth/hc05-setup.md already had a thorough
    walkthrough (TX/RX swap warning, three undocumented quirks, picocom
    commands per OS, IPSCAN power tradeoff with comparison table,
    macOS "Disconnected" cosmetic quirk). Build guide didn't mention
    that doc existed.
    2. Firmware section walked you through fresh flashes but skipped what
    to do if you're re-flashing a working board (back up first) and
    didn't cover building from upstream source if you wanted to modify
    the firm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
2026-05-02 Strunk-pass on READMEs + corrections (firmware default, USBasp recs)
    Two unrelated fixes bundled together since they hit overlapping files.
    (1) Strunk copy-edit pass across all locally-authored READMEs
    Ran the elements-of-style guide (Strunk Jr.'s rules — active voice,
    omit needless words, definite/specific language, positive form, related
    words together) over every README we own. Skipped the bundled-upstream
    4-wireless/wifi/README.md to avoid future subtree-pull conflicts.
    Net: -111 / +110 lines, mostly small per-file. Most-touched were
    README.md (root, +28/-28), 4-wireless/README.md (+28/-28),
    4-wireless/wifi/pcb/jlcpcb-package/README.md (+43/-43), and the new
    3-build-and-flash/README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
    [BOM_full.csv]
2026-05-08 F20 matching: bump critical BOM qtys + document MOSFET sort-and-pair procedure
    Five parts now ship over-quantity to support Vt matching and rework margin
    on F20 calibration:
    - IRL520N (Q1, Q2, Q4, Q5): 4 → 12. Typical batch spread is 200-400 mV
    from a single Mouser reel; 3x over-order is the minimum to reliably
    fish a quartet within the 20-30 mV intra-pair tolerance.
    - IRF9Z24NPBF (Q3, Q6): 2 → 6. These sit in the F20 calibration servo
    loop in linear-region operation; pick clusters by absolute Vt (target
    2.85-3.05 V, reject anything > 3.30 V).
    - R35, R46 (200k op-amp bias): 2 → 4. Value-critical for F20 bias.
    - R30 (0.27R current sense): 1 → 3. Easy to damage during desolder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
    [BOM_Mouser.csv, BOM_full.csv]
2026-05-08 Sweep up working-tree changes: firmware reorg, failure analyses, hc05 fixes, scripts
    Rename custom-boot-messages/ -> cr-custom-boot-messages/ and prefix files
    with f005- to match the firmware-version naming used elsewhere in the repo.
    Add new other-fw/ holding f005.bin (frankenbutt build), t002_bootloader.bin
    (ET-312 bootloader), and unpatched_312-16.upg for archival completeness.
    Failure analysis docs for codes 10, 15, 16, 72, 80 plus a failure-codes
    index, generated from disassembly of backup_flash.bin and forum cross-
    reference. Companion to failure-21-analysis.md (already in tree) and
    failure-20-analysis.md (committed in 2f5cf13). board-test-results.pdf
    captures the bench measurements f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
2026-05-08 Rewrite F20-related docs for beginner comprehension
    2-order-parts/README.md restructure: front-load the actionable BOM
    critical-parts table, cut headroom-math/supplier-reasoning prose
    (moved to failure-20-analysis.md as link, not duplication), and
    add a step-by-step beginner walkthrough for MOSFET matching with
    a Mermaid workflow diagram and a worked example showing how
    1.91/1.92/1.92/1.93 maps to Q1/Q2/Q4/Q5.
    docs/build-guide.md firmware section: collapse the 10-step "First-time
    walkthrough" with inline troubleshooting into a clean 7-step happy
    path, add explicit "no -B 8, no -F, no driver gymnastics needed for
    normal builds" framing upfront, and consolidate all troubleshooting
    into a sing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
2026-05-08 WiFi cross-ref, DSD Tech HC-05, HC-05 timing fix, OSOYOO -> ROADMAP
    1-order-boards/README.md: cross-reference the optional WiFi adapter
    PCB so builders see the combined-shipping option when ordering main
    board + front panel from JLCPCB. Cost reality check (~5-board batch)
    inline.
    4-wireless/bluetooth/README.md: recommend DSD Tech HC-05 Pass-through
    B01G9KSAF6 specifically — pin 32 STATE pre-soldered to the breakout
    (skip the most fiddly step on cheap clones), stable AT-mode firmware.
    2-order-parts/BOM_full.csv updated to point at this part with the
    real ASIN, replacing a dead amzn.to shortlink.
    docs/build-guide.md: HC-05 auto-config flow had timing-ambiguous
    wording around the button-hol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
    [BOM_full.csv]
2026-05-09 ROADMAP: add MK-312WS evaluation; F20 doc: reframe IRL tolerance rationale
    ROADMAP.md gets a new section evaluating bkifft/MK-312WS as a candidate
    WiFi-adapter replacement. Verdict: alternative to investigate, not a
    replacement. The handleWebSocketMessage_ws_bytes() function in the
    source is empty — no raw protocol passthrough — so existing clients
    (mk312-gui, .NET reference, ErosWeb, three-twelve-bee) can't connect.
    Web UI exposes only mode read/write and battery; LevelA/B, MultiAdjust,
    startRamp, CutLevels, EEPROM access, user programs all missing or
    flagged "planned" by the author. Repo dormant since 2022-10-02 with
    the planned roadmap unshipped. Documented bar to make this the defaul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
2026-05-09 docs: archive mosfetkiller.de MK-312-BT thread (English translation)
    Posts 1-15 of forum.mosfetkiller.de t=64758 translated from German.
    The thread surfaces a non-trivial correction to the canonical fuse
    settings: HFUSE 0xDC enables the BOOTRST boot-vector fuse, which is
    correct only when the t002 bootloader is flashed first; for builders
    flashing application-only firmware (e.g. f005-HelloFriend.bin)
    directly, HFUSE 0xD9 is the correct value (BOOTRST disabled, chip
    starts at 0x0000 on reset).
    Confirmed by two independent builders in the thread (MWU and
    MauiKano post #14): switching HFUSE from 0xDC to 0xD9 fixed the
    "row of solid white blocks on LCD" symptom that came from RESET
    pin not beha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
2026-05-13 Restructure: move dev material to local-only .dev/, flatten docs
    Pull non-build material out of git tracking and reorganize the remaining
    content so the public repo is exactly what a builder needs.
    Removed from git (kept locally in .dev/ per .gitignore):
    - CLAUDE.md (AI-agent notes, private)
    - ROADMAP.md (speculative work, not part of the build path)
    - scripts/ (build-mega-readme.sh and failure-code MD/PDF generators —
    developer tooling, not user-facing)
    - historical/ (v1.2/v1.3 boards + Eagle source — archaeology, not what
    anyone should build today; pointer added to upstream CrashOverride85
    in 1-order-boards/README.md instead)
    Moved to better homes:
    - docs/build-guide.md -> ./bu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
    [BOM_full.csv, MK-312BT Front Panel V1.2.brd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]
2026-05-13 Tighten READMEs, remove ErosTek-derived blobs from the public tree
    README pass
    - Root README: kept the journey table and credits; cut redundant
    provenance prose that overlapped build-guide.md; merged the credit
    list into a table; surfaced Roadmap.md.
    - 3-build-and-flash/README.md: stripped the redundant "where the real
    walkthrough lives" anchor list — link straight to build-guide.md and
    drop into a one-line "if something goes wrong" pointer.
    - 4-wireless/wifi/README.md: restructured the upstream README into
    hardware spec / BOM / flashing / first boot / protocol / web UI /
    legacy serial sections. Fixed the malformed "Contents" table.
    - 4-wireless/wifi/pcb/jlcpcb-package/README.m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
2026-05-29 BOM: square-hole 40-pin socket, MOSFET matching pools, WiFi/Spares split
    - Replace Mill-Max 110-series (round/machine-pin) 40-pin socket with
    3M 4840-6004-CP (same 4800 dual-wipe stamped series as existing 14/16-pin
    sockets) in both BOM_Mouser.csv and BOM_full.csv
    - Restore MOSFET quantities to full Vt-matching pool amounts in main BOM:
    IRF9Z24N 2→6 (install 2 closest-matched pair), IRL520N 4→12 (install 4
    closest-matched set) — unit cannot be built without matched pairs
    - Add BOM_Mouser_Spares.csv and BOM_full_Spares.csv: MOSFET pool remainders
    + crystal/resistor insurance spares (separate from main order)
    - Add BOM_Mouser_WiFi.csv and BOM_full_WiFi.csv: WiFi PCB BOM with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
    [BOM_Mouser.csv, BOM_Mouser_Spares.csv, BOM_Mouser_WiFi.csv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]
2026-05-29 BOM: add Description column to all three Mouser order CSVs
    Adds a human-readable 5th column (Description) to BOM_Mouser.csv,
    BOM_Mouser_Spares.csv, and BOM_Mouser_WiFi.csv showing part values
    and types (e.g. "RES 100K", "CAP 0.1uF 50V", "MOSFET N-ch 100V 10A
    IRL520N"). Column is ignored by Mouser's 4-column CSV uploader and
    is purely for readability in the GitHub CSV viewer.
    [BOM_Mouser.csv, BOM_Mouser_Spares.csv, BOM_Mouser_WiFi.csv]
2026-05-29 BOM: fix CSV quoting errors; clarify IRL520N per-channel Vt matching
    - Fix illegal quoting in BOM_Mouser.csv lines 46 and 59: replace inch
    marks (") in descriptions with "in" (0.1in, 0.187in) so GitHub's CSV
    renderer parses the file correctly
    - Clarify IRL520N matching note across all four BOMs: "install 2
    closest-matched per channel: Q1+Q2 ch.A, Q4+Q5 ch.B" — the unit has
    two output channels, each needing a matched N-channel pair
    [BOM_Mouser.csv, BOM_Mouser_Spares.csv, BOM_full.csv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]
2026-05-29 BOM: CMF55 resistors, gold DIP sockets, ribbon cable + crimp lug fixes
    - Replace all resistors with Vishay Dale CMF55 FHEB series (71-CMF55* Mouser)
    - R30 (0.27R 1W metal oxide) preserved as-is — exception to CMF55 rule
    - Replace all DIP sockets with Aries 600-11 gold square-hole (535-xx-600-11)
    - Ribbon cable upgraded to IDSD-12-D-03.00 (24-cond, 3.00in)
    - BAT1 crimp lugs split: red 534-8291 (22/18 AWG) + blue 534-8293 (16/14 AWG)
    - MOSFET pool quantities in main BOM for Vt-threshold matching
    [BOM_Mouser.csv, BOM_Mouser_Spares.csv, BOM_full.csv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]
